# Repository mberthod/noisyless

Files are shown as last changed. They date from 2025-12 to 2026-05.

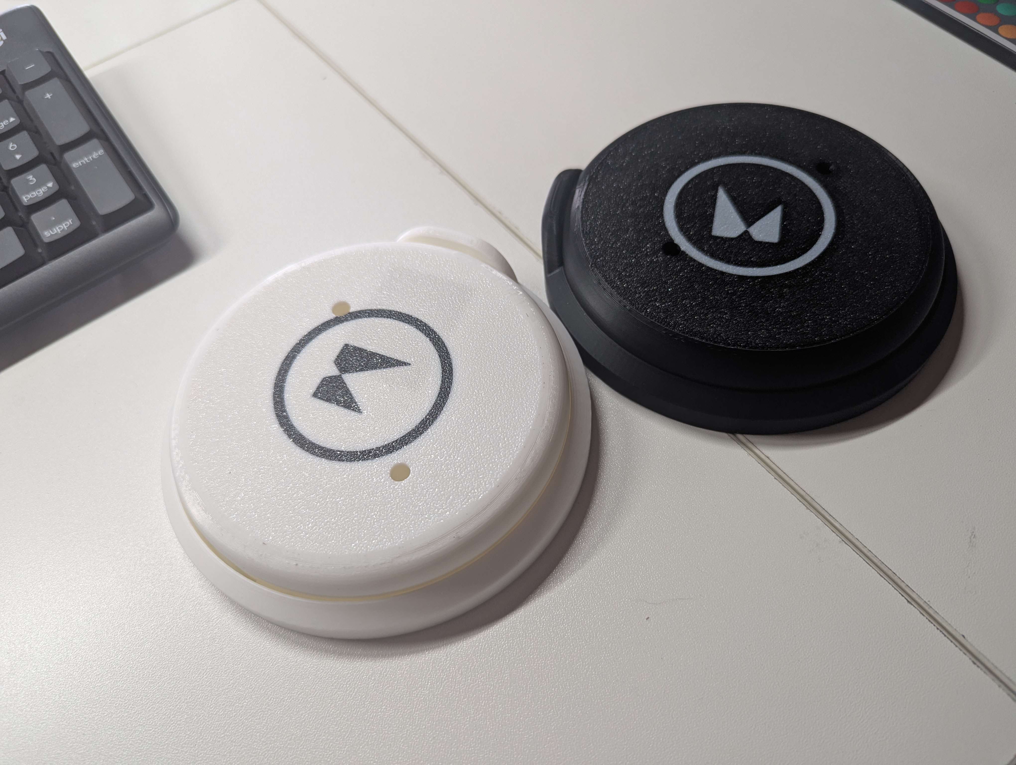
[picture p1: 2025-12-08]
01_PROJETS/202604_089_Capteur_Environnemental_V1/04_FABRICATION/PXL_20250405_083316542.jpg

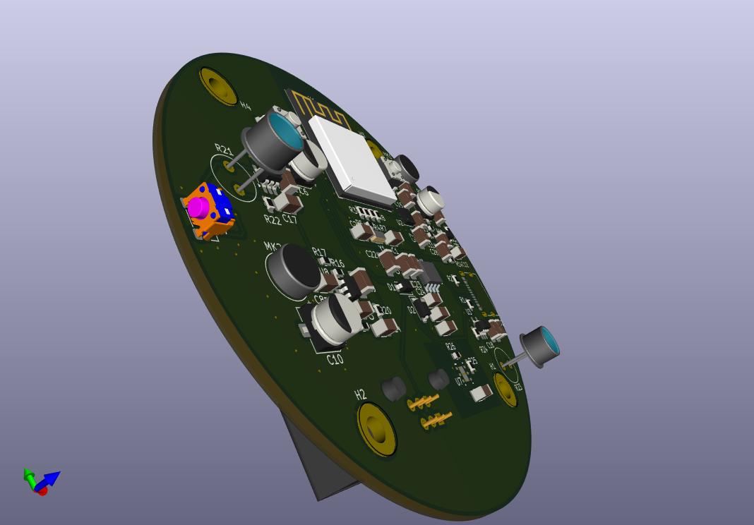
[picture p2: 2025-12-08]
01_PROJETS/202604_089_Capteur_Environnemental_V1/01_CAHIER_DES_CHARGES/Environnemental_sensor_V01.jpg

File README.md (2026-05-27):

# NOISYLESS — Capteur Environnemental IoT

Firmware ESP32-S3 modulaire pour le capteur environnemental NOISYLESS. Monitoring en temps réel du bruit, de la luminosité, de la qualité d'air (IAQ/CO₂/VOC) et de la présence humaine — transmission MQTT vers le dashboard, OTA over-the-air, LED de statut RGB.

## Capteurs (5 axes)

| Capteur | Pins | Mesure | Module |
|---|---|---|---|
| 🔆 **Luminosité ×2** | GPIO1, GPIO2 (ADC 12-bit) | Lux ambiant, deux directions | `analog_sensors.h` |
| 🎤 **Bruit (micro ×2)** | GPIO3, GPIO4 (ADC 12-bit) | Niveau sonore crête-à-crête (peak-to-peak 50ms) | `analog_sensors.h` |
| 🌡️ **Qualité d'air** | I²C SDA=GPIO35, SCL=GPIO36 | IAQ, CO₂eq, bVOCeq, T°/Hum/Pression compensées, Gas | `bme680_sensor.h` |
| 📡 **Présence radar** | UART Serial1 RX=GPIO18, TX=GPIO17 (256000 bauds) | Cible mobile, cible stationnaire, distance cm | `ld2410_sensor.h` |

### Principe de mesure

- **Lux ×2** : lecture directe `analogRead()` 12-bit, deux photorésistances orientées
- **Micro ×2** : échantillonnage 50ms, calcul de l'amplitude crête-à-crête (`max - min`) via deux électrets analogiques
- **BME680 + BSEC2** : capteur I²C 0x76, mode Ultra Low Power (ULP) — mesure toutes les 3s, calibration IAQ continue via algorithme Bosch BSEC2 (IAQ 0-500, CO₂eq, bVOCeq, T°/Hum/Pression compensées)
- **LD2410** : radar 24 GHz sur UART 256000 bauds, parse les trames binary → détection mouvement + stationnaire + distance

## Architecture firmware (v2.0.0)

```
05_FIRMWARE/
├── src/
│   ├── main.cpp                     # setup(), tâches FreeRTOS
│   ├── sensors/
│   │   ├── bme680_sensor.h/.cpp     # BME680 + BSEC2 (IAQ, CO2, VOC, T/H/P)
│   │   ├── ld2410_sensor.h          # LD2410 radar (présence, distance)
│   │   └── analog_sensors.h         # Lux ×2 + micros ×2 (ADC peak-to-peak)
│   ├── comm/
│   │   └── wifi_mqtt.h              # WiFi (hardcodé) + MQTT (PubSubClient)
│   ├── ota/
│   │   └── ota_manager.h            # OTA HTTP check 60s + download + flash SHA256
│   └── ui/
│       └── led_status.h/.cpp        # LED RGB (actif bas), séquence boot, timings
├── include/
│   ├── wifi_config.h                # SSID + mot de passe WiFi
│   └── credentials.h                # MQTT host/user/pass
└── platformio.ini                   # ESP32-S3, DIO, BSEC2 + LD2410 + PubSubClient
```

### FreeRTOS — 3 tâches

| Tâche | Cœur | Priorité | Stack | Rôle |
|---|---|---|---|---|
| `task_mqtt` | 0 | 1 | 4 Ko | WiFi/MQTT/OTA + publication 10s + LED rouge si WiFi perdu |
| `task_sensors` | 1 | 2 | 4 Ko | BME680 tick + LD2410 tick + Analog (50ms) |
| `task_led` | 0 | 0 | 2 Ko | Timings LED (vert boot 1s, flash publish 200ms) |

Les données sont partagées via `SharedData` protégé par `SemaphoreHandle_t` mutex.

### Séquence LED

| État | LED | Durée |
|---|-----|---|
| Boot | 🔴 Rouge fixe | ~1s |
| WiFi en cours | 🔵 Bleu fixe | Jusqu'à connexion |
| Version | 🔵×N clignotements | N = 3ᵉ chiffre version (ex: v2.0.**0** → 10 flashs) |
| Connecté | 🟢 Vert fixe | 1s |
| Publication MQTT OK | 🟢 Flash vert | 200ms |
| Idle | ⚫ Éteinte | — |
| WiFi perdu | 🔴 Rouge fixe | Jusqu'à reconnexion |

**Mapping GPIO** : LED_R=GPIO12, LED_G=GPIO13, LED_B=GPIO14. Actif bas : `LOW = allumé`.

## Payload MQTT

Topic : `esp32/noisyless/{MAC}/datas`

```json
{
  "product": "noisyless_env",
  "client_code": "client_demo",
  "device_id": "NL-A1B2C3D4E5F6",
  "fw_version": "2.0.0",

  "lux1_raw": 2048,
  "lux2_raw": 1890,
  "sound_mic1_pp": 295,
  "sound_mic2_pp": 266,

  "presence": true,
  "distance_cm": 120,

  "temp_comp_c": 22.40,
  "hum_comp_pct": 48.30,
  "pressure_pa": 101325,
  "iaq": 25.0,
  "co2eq_ppm": 450.0,
  "bvoc_eq_ppm": 0.50,
  "gas_ohms": 50000,
  "iaq_accuracy": 3,
  "stab_status": 1,
  "run_in_status": 1,

  "rssi_dbm": -58,
  "uptime_s": 3600
}
```

**Champs optionnels** : si le BME680 n'est pas détecté, les champs IAQ/CO₂/VOC/T°/Hum/Pression sont omis. Si le LD2410 n'est pas détecté, `presence` et `distance_cm` restent à `false`/`0`.

## Déploiement OTA — Workflow complet

### Prérequis

- PlatformIO (`pio --version`)
- Accès SSH au serveur Hetzner : `noisyless@91.99.26.43`
- Firmware servi par nginx depuis `/opt/noisyless/static/firmware/` sur le port 80
- WiFi hardcodé dans `include/wifi_config.h`

### 1. Modifier le firmware

```bash
cd 05_FIRMWARE
```

Sources à modifier :
- `src/main.cpp` — `FW_VERSION`, logique métier
- `include/wifi_config.h` — SSID + mot de passe WiFi
- `include/credentials.h` — host/user/pass MQTT

**Incrémenter `FW_VERSION`** dans `main.cpp` :
```cpp
#define FW_VERSION "2.0.1"  // ← changer ici
```

### 2. Builder

```bash
pio run -e esp32dev
```

Sortie : `.pio/build/esp32dev/firmware.bin` (~972 Ko avec BSEC2+LD2410)

**Config PlatformIO** (`platformio.ini`) :
- `board = esp32-s3-devkitc-1`
- `board_build.flash_size = 8MB`
- `board_build.psram_type = disabled`
- `board_build.flash_mode = dio`
- `board_build.flash_freq = 40m`
- `build_flags = -D ARDUINO_USB_CDC_ON_BOOT=1`
- `lib_deps = PubSubClient, ld2410, bsec2, BME68x`

### 3. Calculer le SHA256

```bash
sha256sum .pio/build/esp32dev/firmware.bin
```

### 4. Déployer sur le serveur

```bash
# Copier le binaire
scp .pio/build/esp32dev/firmware.bin noisyless@91.99.26.43:/opt/noisyless/static/firmware/

# Mettre à jour le manifest OTA
ssh noisyless@91.99.26.43 'cat > /opt/noisyless/static/firmware/latest.json << EOF
{"version":"2.0.1","url":"http://91.99.26.43/firmware/firmware.bin","sha256":"LE_HASH_ICI"}
EOF'
```

### 5. Vérifier

```bash
# Manifest
curl -s http://91.99.26.43/firmware/latest.json

# Binaire (200 OK)
curl -sI http://91.99.26.43/firmware/firmware.bin | head -3

# SHA256 côté serveur
ssh noisyless@91.99.26.43 'sha256sum /opt/noisyless/static/firmware/firmware.bin'
```

### 6. Propagation OTA

Chaque module checke le manifest **toutes les 60s**. Si `version != FW_VERSION` :
1. Téléchargement `.bin` (30s timeout)
2. Vérification SHA256
3. `Update.begin()` → flash
4. `ESP.restart()`

**Rollback automatique** : si le firmware ne boote pas, le bootloader ESP32-S3 restaure la partition précédente.

### 7. Surveillance

```bash
# Devices et versions
ssh noisyless@91.99.26.43 "docker compose -f /opt/noisyless/docker-compose.yml exec -T timescaledb psql -U noisyless -d noisyless -c 'SELECT device_id, firmware_version, status, last_seen FROM noisyless.devices ORDER BY last_seen DESC;'"

# Logs env-ingest
ssh noisyless@91.99.26.43 "docker compose -f /opt/noisyless/docker-compose.yml logs --tail=30 env-ingest | grep -E 'fw_version|device_id'"
```

### Flash USB direct (recovery)

```bash
pio run -e esp32dev -t upload

# Bootloop → full erase
pio run -e esp32dev -t erase && pio run -e esp32dev -t upload
```

## Architecture système

```
┌──────────────────────────┐     MQTT      ┌─────────────────┐     SQL      ┌──────────────┐
│  ESP32-S3 (×N)           │──────────────▶│  Hetzner VPS     │─────────────▶│ TimescaleDB   │
│  WiFi + MQTT + OTA       │   port 1883   │  mosquitto       │             │               │
│  lux×2 + mic×2           │               │  env-ingest      │    HTTP     │ devices       │
│  BME680/BSEC2 IAQ        │               │  api             │◀────────────│ measurements │
│  LD2410 présence         │◀──────────────│  nginx (static)  │             └──────────────┘
│  LED RGB statut          │   OTA HTTP:80  │                  │
└──────────────────────────┘               └─────────────────┘
```

## Pièges connus

- **ESP32-S3 flash mode** : S3-MINI-1 est QIO natif mais GPIO12/14 sont sur le bus SPI → utiliser DIO 40 MHz. Sans ça, les LEDs ne fonctionnent pas.
- **Partitions OTA** : `default.csv` suffit. `custom_partitions.csv` peut causer des bootloops si l'otadata est corrompue.
- **WiFiManager NVS** : les credentials WiFiManager survivent au reflash. Utiliser `esptool.py erase_flash` si on change de WiFi.
- **LED jaune** : toujours `led_off()` avant de changer de couleur (actif bas, rouge+vert simultanés = jaune).
- **SHA256 mismatch** : OTA silencieusement ignoré si le hash manifest ≠ hash binaire. Vérifier avec `curl | sha256sum`.
- **BSEC2 calibration** : l'IAQ met ~5 min à se stabiliser au premier boot (`run_in_status` = 1). L'accuracy monte progressivement de 0 à 3.
- **LD2410 baud rate** : 256000 obligatoire. Le constructeur documente 115200 mais le firmware usine est à 256000.
- **BME680 I²C** : scanne 0x76 puis 0x77. Si le capteur est en mode sleep (broche MODE flottante), il ne répond pas. GPIO37 doit être LOW.
- **Taille flash** : BSEC2 + BME68x + LD2410 = ~972 Ko / 1310 Ko dispo (74%). Compiler sans PSRAM. Vérifier `board_build.psram_type = disabled`.

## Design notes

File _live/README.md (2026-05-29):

# _live/ — Snapshot production NOISYLESS v1

Ce dossier est un **instantané** (`snapshot`) de ce qui tourne réellement
sur le VPS Hetzner (91.99.26.43) à la date du 29 mai 2026.

## Structure

```
_live/
├── STATE.md               ← État des lieux complet (ce document)
├── docker-compose.yml     ← Compose utilisé en production
├── services/              ← Code source des micro-services
│   ├── api/               ← FastAPI (auth, devices, admin, shop...)
│   ├── env-ingest/        ← ESP32 capteurs environnement → DB
│   ├── mqtt-ingest/       ← HeatMap → DB
│   ├── heatmap-agg/       ← Agrégation 5 min
│   └── alert-engine/      ← Alertes seuils
├── nginx/
│   ├── nginx.conf         ← Config nginx (2 domaines, SSL, proxy)
│   └── nginx.conf.bak     ← Backup précédent
├── mosquitto/config/
│   └── mosquitto.conf     ← Config broker MQTT
└── static/                ← Pages web (html uniquement)
    ├── platform.html      ← Dashboard plateforme
    ├── admin.html         ← Panel admin
    ├── dashboard.html     ← Dashboard utilisateur
    ├── pilote-heatmap.html
    ├── precommande.html
    ├── conciergerie.html
    ├── produits/          ← heatmap-indoor, outdoor, property-pack
    ├── cas-usage/         ← conciergerie, hospitality, immobilier, villa
    ├── comparatif/        ← vs-camera, vs-detecteur, vs-minut
    ├── technologie/       ← intelligence-spatiale, privacy, reseau-maille
    └── firmware/          ← stable.json, latest.json
```

## Avertissement

Les fichiers dans `services/` et `static/` sont les sources déployées en
production. Les chemins d'infrastructure correspondants dans le repo
sont synchronisés avec `_infra/` et `_commun/web/site/`.

Pour toute modification : éditer dans `_infra/`, déployer sur VPS,
**puis** mettre à jour `_live/` en miroir.

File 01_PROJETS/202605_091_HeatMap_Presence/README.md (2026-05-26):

# NOISYLESS — Organisation des projets

**Date :** 24 Mai 2026  
**Vue d'ensemble :** 3 produits distincts, 1 infrastructure commune

---

## 📋 Les 3 projets hardware

| Projet | Code | Capteurs | Usage | Prix cible |
|---|---|---|---|---|
| **NOISYLESS Simple** | `nl-presence` | PIR + ToF mono + CO₂ + Son | Détection présence basique | ~50 € |
| **NOISYLESS HeatMap Intérieur** | `nl-map-in` | Matrice ToF 16×16 (TMF8829) | Heatmap intérieure | ~80 € |
| **NOISYLESS HeatMap Extérieur** | `nl-map-out` | Radar 60 GHz (MS72SF1) | Heatmap extérieure | ~120 € |

---

## 🏗️ Architecture commune

```
┌─────────────────────────────────────────────────────────────┐
│                    NOISYLESS PLATFORM                       │
├─────────────────────────────────────────────────────────────┤
│                                                             │
│  ┌──────────┐  ┌──────────┐  ┌──────────┐                  │
│  │  Simple  │  │   Int    │  │   Ext    │                  │
│  │ nl-      │  │ nl-map-  │  │ nl-map-  │                  │
│  │ presence │  │   in     │  │   out    │                  │
│  └────┬─────┘  └────┬─────┘  └────┬─────┘                  │
│       │             │             │                         │
│       └─────────────┴─────────────┘                         │
│                     │                                       │
│                     ▼                                       │
│              ┌─────────────┐                                │
│              │   Mosquitto │  MQTT Broker                   │
│              │   (TLS 8883)│                                │
│              └──────┬──────┘                                │
│                     │                                       │
│                     ▼                                       │
│              ┌─────────────┐                                │
│              │  TimescaleDB │  Base de données              │
│              └──────┬──────┘                                │
│                     │                                       │
│       ┌─────────────┼─────────────┐                        │
│       │             │             │                         │
│       ▼             ▼             ▼                         │
│  ┌────────┐   ┌────────┐   ┌────────┐                      │
│  │ ingest │   │  agg   │   │ alert  │                      │
│  │  MQTT  │   │heatmap │   │ engine │                      │
│  └────────┘   └────────┘   └────────┘                      │
│                                                             │
│       ┌─────────────────────────────┐                      │
│       │      FastAPI Backend        │                      │
│       │   + Dashboard Web/Mobile    │                      │
│       └─────────────────────────────┘                      │
│                                                             │
└─────────────────────────────────────────────────────────────┘
```

---

## 📁 Arborescence des répertoires

```
/home/mathieu/Kdrive/01_CLIENTS/NOISYLESS/
├── 00_INFOS_CLIENT/              # Contrat, factures, contacts
│
├── _infra/                       # INFRASTRUCTURE COMMUNE
│   ├── docker-compose.yml        # Tous services
│   ├── services/
│   │   ├── mqtt-ingest/          # Subscribe MQTT → DB
│   │   ├── heatmap-agg/          # Agrégation 5min
│   │   ├── alert-engine/         # Alertes Telegram
│   │   └── api/                  # FastAPI REST
│   ├── mosquitto/                # Config broker
│   ├── timescaledb/              # Config DB
│   ├── nginx/                    # Reverse proxy + SSL
│   └── docs/
│       ├── DEPLOYMENT.md         # Guide déploiement (SIMPLE !)
│       ├── MAINTENANCE.md        # Opérations courantes
│       └── TROUBLESHOOTING.md    # Problèmes courants
│
├── 202605_091_HeatMap_Presence/  # PROJET PILOTE ( HeatMap )
│   ├── PROJECT.md                # Fiche projet #091
│   │
│   ├── 01_NOISYLESS_SIMPLE/      # Produit : Détection basique
│   │   ├── firmware/
│   │   │   └── node-presence/
│   │   │       ├── src/
│   │   │       ├── platformio.ini
│   │   │       └── README.md
│   │   ├── hardware/
│   │   │   ├── schematics/
│   │   │   └── bom/
│   │   ├── docs/
│   │   │   ├── QUICKSTART.md     # Démarrage rapide
│   │   │   └── INSTALL.md        # Installation
│   │   └── scripts/
│   │       └── flash.sh
│   │
│   ├── 02_NOISYLESS_HEATMAP_INT/ # Produit : Heatmap intérieur
│   │   ├── firmware/
│   │   │   └── node-tof-esp32s3/
│   │   │       ├── src/
│   │   │       ├── components/
│   │   │       ├── platformio.ini
│   │   │       └── README.md
│   │   ├── hardware/
│   │   │   ├── schematics/
│   │   │   └── bom/
│   │   ├── docs/
│   │   │   ├── QUICKSTART.md
│   │   │   └── INSTALL.md
│   │   └── scripts/
│   │       └── flash.sh
│   │
│   └── 03_NOISYLESS_HEATMAP_EXT/ # Produit : Heatmap extérieur
│       ├── firmware/
│       │   └── node-radar-ms72sf1/
│       │   ├── src/
│       │   ├── platformio.ini
│       │   └── README.md
│       ├── hardware/
│       │   ├── schematics/
│       │   └── bom/
│       ├── docs/
│       │   ├── QUICKSTART.md
│       │   └── INSTALL.md
│       └── scripts/
│           └── flash.sh
│
└── 202604_089_Capteur_Environnemental_V1/  # Ancien projet (archive)
```

---

## 🎯 Différences entre projets

### NOISYLESS Simple (`nl-presence`)

**Objectif :** Détecter présence + bruit + qualité d'air

**Capteurs :**
- PIR (présence binaire)
- ToF mono-zone (distance)
- SCD4x (CO₂, température, humidité)
- INMP441 (niveau sonore dB)

**Firmware :**
- Publish toutes les 30s
- Payload simple : `{present: bool, co2: int, db: int, temp: float}`
- Batterie possible (deep sleep)

**Backend :**
- Table `measurements` standard
- Alertes seuil CO₂ / bruit

---

### NOISYLESS HeatMap Intérieur (`nl-map-in`)

**Objectif :** Heatmap de densité intérieure

**Capteurs :**
- TMF8829 (ToF 16×16 zones)
- ESP32-S3 (WiFi + BLE)

**Firmware :**
- Mesh ESP-NOW (multi-noeuds)
- Master → MQTT toutes les 10s
- Payload : `{grid: [[count]], total: int}`

**Backend :**
- Continuous aggregates 5min
- Heatmap par zone
- Alertes suroccupation

---

### NOISYLESS HeatMap Extérieur (`nl-map-out`)

**Objectif :** Heatmap de densité extérieure

**Capteurs :**
- MS72SF1 (Radar 60 GHz)
- ESP32-S3 (WiFi + BLE)

**Firmware :**
- UART parsing (trames binaires TLV)
- Mesh ESP-NOW (multi-noeuds)
- Master → MQTT toutes les 10s
- Payload : `{targets: [{x,y,z,v}], count: int}`

**Backend :**
- Agrégation cibles 3D
- Heatmap projetée 2D
- Alertes suroccupation

---

## 🚀 Démarrage rapide

### 1. Déployer l'infrastructure

```bash
cd /home/mathieu/Kdrive/01_CLIENTS/NOISYLESS/_infra
./scripts/deploy.sh
```

→ Voir `_infra/docs/DEPLOYMENT.md`

### 2. Flasher un device

```bash
cd 01_NOISYLESS_SIMPLE/firmware/node-presence
pio run --target upload
```

→ Voir `01_NOISYLESS_SIMPLE/docs/QUICKSTART.md`

### 3. Claimer un device

```bash
curl -X POST https://platform.noisyless.com/api/devices/claim \
  -H "Authorization: Bearer <token>" \
  -d '{"duid": "24:EC:4A:23:36:BC", "claim_code": "HMAC..."}'
```

---

## 📊 État d'avancement

| Projet | Firmware | Hardware | Backend | Docs | Statut |
|---|---|---|---|---|---|
| **Simple** | 🟡 50% | ⚪ 0% | ✅ 80% | 🟡 50% | En dev |
| **HeatMap Int** | ✅ 90% | ⚪ 0% | ✅ 80% | 🟡 50% | Pilote |
| **HeatMap Ext** | 🟡 30% | ⚪ 0% | 🟡 50% | 🟡 50% | En dev |
| **Infra** | N/A | N/A | ✅ 90% | 🟡 60% | quasi-OK |

---

## 🔗 Liens utiles

- **Infrastructure :** `_infra/docs/DEPLOYMENT.md`
- **Projet #091 :** `PROJECT.md`
- **Architecture :** `_infra/ARCHITECTURE.md`
- **Migration :** `_infra/MIGRATION_PLAN.md`

---

*Document créé : 24 Mai 2026*  
*Mis à jour : 24 Mai 2026*

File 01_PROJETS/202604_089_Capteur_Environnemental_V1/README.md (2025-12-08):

# Environmental Sensor Firmware Documentation

## Overview

This documentation describes the firmware for an ESP32-S3 based environmental sensor system. The system is designed to monitor various environmental parameters including air quality, light levels, sound levels, and presence detection. The firmware is built using the Arduino framework and FreeRTOS for task management.

## System Architecture

The firmware is organized into several key components:

1. **Sensor Management**: Handles reading data from various environmental sensors
2. **Network Communication**: Manages WiFi connectivity and data transmission to a server
3. **Memory Management**: Monitors and optimizes memory usage
4. **Alert System**: Detects and reports significant environmental changes
5. **OTA Updates**: Supports over-the-air firmware updates

## FreeRTOS Task Structure

The firmware uses FreeRTOS to manage concurrent operations through the following tasks:

- **Memory Task**: Monitors memory usage and performs periodic defragmentation
- **Sensor Task**: Reads data from sensors at regular intervals
- **Network Task**: Handles all network communications
- **Button Task**: Monitors the physical button for user interactions

## Key Features

- Real-time environmental monitoring
- Automatic data transmission to a central server
- Offline data storage with automatic transmission when connectivity is restored
- Memory leak detection and prevention
- Automatic firmware updates
- Alert system for significant environmental changes

## Getting Started

To use this firmware:

1. Configure your credentials in `credentials.h`
2. Upload the firmware to your ESP32-S3 device
3. The device will automatically connect to WiFi and begin monitoring

## Memory Management

The firmware includes sophisticated memory management features:

- Periodic memory status logging
- Memory leak detection
- Automatic defragmentation
- NVS (Non-Volatile Storage) cleaning

## Network Communication

The firmware supports:

- Automatic WiFi connection and reconnection
- HTTP communication with a central server
- Retry mechanisms for failed transmissions
- Offline data storage

## Alert System

The alert system can detect:

- Device removal from its mounting
- Significant environmental changes
- System errors and warnings

## OTA Updates

The firmware supports over-the-air updates:

- Automatic update checking
- Secure update process
- Version management

## Dependencies

- Arduino Framework
- FreeRTOS
- WiFi Library
- HTTPClient Library
- ArduinoJson Library
- Preferences Library

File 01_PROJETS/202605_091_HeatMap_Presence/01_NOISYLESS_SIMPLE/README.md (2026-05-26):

# NOISYLESS Simple — `nl-presence`

**Statut :** En développement  
**Cible :** Détection présence basique + qualité d'air  
**Prix :** ~50 € BOM

---

## 📋 Spécifications

### Capteurs

| Capteur | Rôle | Interface |
|---|---|---|
| PIR HC-SR501 | Présence binaire | GPIO (IRQ) |
| VL53L0X | Distance mono-zone | I2C |
| SCD4x | CO₂, T°, HR | I2C |
| INMP441 | Niveau sonore (dB) | I2S |

### MCU

| Paramètre | Valeur |
|---|---|
| Modèle | ESP32-S3-MINI-1 |
| Flash | 8 MB |
| WiFi | 2.4 GHz |
| BLE | 5.0 |
| Antenne | PCB ou U.FL |

### Alimentation

| Mode | Conso | Autonomie |
|---|---|---|
| Actif | ~80 mA | — |
| Deep sleep | ~50 µA | ~2 ans (18650) |
| Secteur | USB-C 5V | Permanent |

---

## 📁 Structure du firmware

```
firmware/node-presence/
├── src/
│   ├── main.c              # App principale
│   ├── sensors/
│   │   ├── pir.c           # Driver PIR
│   │   ├── tof.c           # Driver VL53L0X
│   │   ├── scd4x.c         # Driver CO₂
│   │   └── mic.c           # Driver INMP441
│   ├── mesh/
│   │   ├── espnow.c        # ESP-NOW mesh
│   │   └── mqtt.c          # MQTT client
│   └── config/
│       ├── nvs.c           # Config NVS
│       └── ota.c           # OTA updates
├── platformio.ini
└── README.md
```

---

## 🔧 Installation firmware

### Prérequis

```bash
# Installer PlatformIO
pip install platformio

# Ou VS Code + extension PlatformIO
```

### Build

```bash
cd firmware/node-presence
pio run
```

### Flash USB

```bash
# Mode bootloader (tenir BOOT + RESET)
pio run --target upload
```

### Flash OTA (après premier claim)

```bash
# Le device récupère sa config WiFi + MQTT via provisioning
# Puis les mises à jour sont automatiques
```

---

## 📡 Payload MQTT

### Topic
```
noisyless/<duid>/telemetry
```

### Format
```json
{
  "schema": "nl.telemetry.v1",
  "model": "nl-presence",
  "duid": "24:EC:4A:23:36:BC",
  "ts": 1716500000,
  "metrics": {
    "present": true,
    "co2_ppm": 450,
    "temp_c": 22.5,
    "hum_pct": 45,
    "sound_db": 35
  },
  "health": {
    "battery_mv": 3300,
    "rssi": -62,
    "fw": "1.0.0"
  }
}
```

### Fréquence
- **Secteur :** Toutes les 30s
- **Batterie :** Toutes les 5min + delta significatif

---

## 🔐 Provisioning

### Méthode 1 : QR Code (recommandé)

1. Scanner QR sur étiquette device
2. App → WiFi credentials → device
3. Device → phone-home → backend
4. Backend → claim automatique

### Méthode 2 : SoftAP

1. Device boot → AP `NOISY-XXXX`
2. Connect → http://192.168.4.1
3. Config WiFi + MQTT
4. Redémarrage

### Méthode 3 : Claim code (secours)

1. Code HMAC sur étiquette
2. API POST `/devices/claim`
3. Validation manuelle

---

## 🏠 Installation physique

### Montage

| Emplacement | Hauteur | Fixation |
|---|---|---|
| Plafond | 2.5-3.5 m | Vis ou adhésif |
| Mur | 1.5-2.0 m | Vis |
| Bureau | — | Posé |

### Orientation

```
        ┌─────────┐
        │  PIR    │  ← Face à la zone à surveiller
        │  ● ●    │
        └─────────┘
           │
        Capteur
           │
        ▼ Zone de détection (120°)
```

### Portée PIR

- **Détection :** ~7 m
- **Angle :** 120°
- **Hauteur max :** 3.5 m

---

## 🆘 Dépannage

| Symptôme | Cause | Solution |
|---|---|---|
| LED ne s'allume pas | Pas d'alim | Vérifier USB-C |
| Pas de WiFi | Mauvais credentials | Refaire provisioning |
| CO₂ = 400 constant | SCD4x pas init | Redémarrer device |
| PIR toujours actif | Face à source chaleur | Déplacer capteur |
| Battery drain | Deep sleep bug | Flash firmware v1.1+ |

---

## 📊 Backend integration

### Tables DB utilisées

```sql
-- Devices
SELECT * FROM noisyless.devices WHERE model = 'nl-presence';

-- Mesures
SELECT time, payload->>'co2_ppm' AS co2
FROM noisyless.measurements
WHERE model = 'nl-presence'
ORDER BY time DESC
LIMIT 100;

-- Agrégats 5min
SELECT window_start, avg((payload->>'co2_ppm')::int) AS avg_co2
FROM noisyless.measurements_agg_5min
WHERE model = 'nl-presence'
GROUP BY window_start;
```

### Alertes configurables

```sql
-- Inscrire une alerte CO₂
INSERT INTO noisyless.alert_thresholds (villa_id, param, threshold)
VALUES ('villa_001', 'co2_ppm', 1000);

-- Inscrire une alerte présence (fête)
INSERT INTO noisyless.alert_thresholds (villa_id, param, threshold)
VALUES ('villa_001', 'present_count', 10);
```

---

## 📄 Fichiers du projet

| Fichier | Rôle |
|---|---|
| `firmware/node-presence/` | Code ESP32 |
| `hardware/schematics/` | Schémas électroniques |
| `hardware/bom/` | Liste composants |
| `docs/QUICKSTART.md` | Démarrage rapide |
| `docs/INSTALL.md` | Guide installation |
| `scripts/flash.sh` | Script flash |

---

## 🔗 Liens

- **Dashboard :** https://platform.noisyless.com
- **API docs :** https://api.platform.noisyless.com/docs
- **Infra deployment :** `../../_infra/docs/DEPLOYMENT.md`

---

*Créé : 24 Mai 2026*  
**Statut :** Firmware 50%, Hardware 0%, Backend 80%

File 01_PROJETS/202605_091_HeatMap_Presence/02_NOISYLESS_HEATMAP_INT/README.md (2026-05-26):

# NOISYLESS HeatMap Intérieur — `nl-map-in`

**Statut :** Pilote fonctionnel  
**Cible :** Heatmap intérieure (ToF 16×16)  
**Prix :** ~80 € BOM

---

## 📋 Spécifications

### Capteurs

| Capteur | Rôle | Interface |
|---|---|---|
| TMF8829 | ToF 16×16 zones | I2C |
| ESP32-S3 | MCU + WiFi | — |

### MCU

| Paramètre | Valeur |
|---|---|
| Modèle | ESP32-S3-MINI-1 |
| Flash | 8 MB |
| WiFi | 2.4 GHz |
| BLE | 5.0 |

### Alimentation

| Mode | Conso |
|---|---|
| Actif | ~150 mA |
| Deep sleep | ~100 µA |
| Secteur | USB-C 5V |

---

## 📁 Structure du firmware

```
firmware/node-tof-esp32s3/
├── src/
│   ├── main.c              # App principale
│   ├── components/
│   │   ├── tmf8829/        # Driver ToF
│   │   ├── cluster/        # Clustering 4-way
│   │   ├── mesh/           # ESP-NOW mesh
│   │   └── config/         # NVS config
│   └── power.c             # Gestion énergie
├── platformio.ini
└── README.md
```

---

## 🔧 Installation firmware

### Build

```bash
cd firmware/node-tof-esp32s3
pio run
```

### Flash

```bash
pio run --target upload
```

---

## 📡 Payload MQTT

```json
{
  "schema": "nl.telemetry.v1",
  "model": "nl-map-in",
  "duid": "24:EC:4A:23:36:BC",
  "ts": 1716500000,
  "metrics": {
    "grid": [[0,1,2],[1,3,1],[0,1,0]],
    "total_count": 5,
    "max_count": 3
  },
  "health": {
    "battery_mv": 3300,
    "rssi": -62,
    "fw": "1.0.0"
  }
}
```

---

## 🏠 Installation

### Montage plafond (recommandé)

```
        ┌─────────────┐
        │   ToF       │  ← Plafond, 2.5-3.5 m
        │  (16×16)    │
        └──────┬──────┘
               │
        ▼ Zone 5×5 m
```

### Multi-noeuds (mesh)

```
  ┌─────┐    ┌─────┐    ┌─────┐
  │Node1│◄──►│Node2│◄──►│Node3│  ← ESP-NOW mesh
  └──┬──┘    └──┬──┘    └──┬──┘
     │          │          │
     └──────────┴──────────┘
                │
           ┌────▼────┐
           │ Master  │  → MQTT
           └─────────┘
```

---

## 📊 Backend

### Tables utilisées

```sql
-- Heatmap agrégée 5min
SELECT window_start, villa_id, zone, total_count, max_count
FROM noisyless.heatmap_agg_5min
WHERE villa_id = 'villa_001'
ORDER BY window_start DESC
LIMIT 12;
```

### Alertes

```sql
-- Suroccupation
INSERT INTO noisyless.alert_thresholds (villa_id, param, threshold)
VALUES ('villa_001', 'max_count', 10);
```

---

## 🆘 Dépannage

| Symptôme | Cause | Solution |
|---|---|---|
| Pas de mesures | ToF pas init | Vérifier I2C (SDA/SCL) |
| Grid vide | Personne hors portée | Portée max ~5 m |
| Mesh instable | Nodes trop loin | Max 30 m entre nodes |

---

*Créé : 24 Mai 2026*  
**Statut :** Firmware 90%, Backend 80%

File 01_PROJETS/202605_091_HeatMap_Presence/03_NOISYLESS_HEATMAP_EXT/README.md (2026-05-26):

# NOISYLESS HeatMap Extérieur — `nl-map-out`

**Statut :** En développement  
**Cible :** Heatmap extérieure (Radar 60 GHz)  
**Prix :** ~120 € BOM

---

## 📋 Spécifications

### Capteurs

| Capteur | Rôle | Interface |
|---|---|---|
| MS72SF1 | Radar 60 GHz | UART |
| ESP32-S3 | MCU + WiFi | — |

### Performances

| Paramètre | Valeur |
|---|---|
| Portée | 0.5 - 30 m |
| Champ | 120° azimuth |
| Cibles max | 10-12 |
| Insensible | Lumière, pluie, vent |

---

## 📁 Structure du firmware

```
firmware/node-radar-ms72sf1/
├── src/
│   ├── main.c              # App principale
│   ├── components/
│   │   ├── ms72sf1/        # Driver UART
│   │   ├── parser/         # Parsing TLV
│   │   └── mesh/           # ESP-NOW
│   └── config/
├── platformio.ini
└── README.md
```

---

## 🔧 Test Python (validé)

```bash
# Installer dépendances
pip install PyQt5 pyqtgraph pyserial numpy

# Lancer l'app
python3 ms72sf1_radar_map.py --port /dev/ttyUSB0 --zmin 0.5 --zmax 2.5
```

---

## 📡 Payload MQTT

```json
{
  "schema": "nl.telemetry.v1",
  "model": "nl-map-out",
  "duid": "24:EC:4A:23:36:BC",
  "ts": 1716500000,
  "metrics": {
    "targets": [
      {"id": 1, "x": 1.2, "y": -0.5, "z": 1.8, "vx": 0.3, "q": 85}
    ],
    "count": 1
  },
  "health": {
    "battery_mv": 3300,
    "rssi": -62,
    "fw": "1.0.0"
  }
}
```

---

## 🏠 Installation

### Montage extérieur

```
        ┌─────────────┐
        │   Radar     │  ← IP65, -20 à +60°C
        │  60 GHz     │
        └──────┬──────┘
               │
        ▼ Zone 30×30 m
```

### Alimentation

- **Secteur :** USB-C 5V
- **PoE :** Option avec injecteur
- **Batterie :** 18650 + panneau solaire (option)

---

## 🆘 Dépannage

| Symptôme | Cause | Solution |
|---|---|---|
| Pas de trames | UART mal branché | Croiser TX/RX |
| Cibles fantômes | Sensibilité haute | `AT+SENS=3` |
| Z incorrect | Hauteur montage | `AT+HEIGHT=H` |

---

*Créé : 24 Mai 2026*  
**Statut :** Test Python OK, Firmware ESP32 30%

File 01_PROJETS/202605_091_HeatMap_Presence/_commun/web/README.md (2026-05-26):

# NOISYLESS — Web & Platform

**Structure :**
```
web/
├── site/              # Site vitrine OVH (noisyless.com)
│   ├── index.html     # Landing page (déjà en ligne)
│   └── assets/        # Images, CSS, JS
│
├── frontend/          # Dashboard client (platform.noisyless.com)
│   ├── src/
│   │   ├── components/
│   │   ├── views/
│   │   └── App.vue
│   └── public/
│
└── backend/           # API + Auth (VPS 91.99.26.43)
    ├── api/
    │   ├── main.py
    │   ├── auth.py    # Register, login, verify
    │   └── devices.py # CRUD devices
    └── services/
```

---

## 📋 État actuel

| Élément | URL | État |
|---|-----|---|
| **Site vitrine** | `noisyless.com` | ✅ En ligne (OVH) |
| **Dashboard** | `platform.noisyless.com` | 🟡 Page statique (VPS) |
| **Auth API** | `api.platform.noisyless.com/auth/*` | ❌ À créer |

---

## 🚀 Architecture cible

```
┌─────────────────────────────────────────────────────┐
│  OVH Hosting (noisyless.com)                        │
│  — Site vitrine statique                            │
│  — Présentation produits                            │
│  — Bouton "Dashboard" → platform.noisyless.com      │
└─────────────────────────────────────────────────────┘
                      │
                      ▼
┌─────────────────────────────────────────────────────┐
│  VPS 91.99.26.43 (platform.noisyless.com)           │
│  ┌─────────────────────────────────────────────┐   │
│  │  Frontend (Vue.js + Tailwind)               │   │
│  │  — Login/Register                           │   │
│  │  — Dashboard client                         │   │
│  │  — Devices management                       │   │
│  └─────────────────────────────────────────────┘   │
│  ┌─────────────────────────────────────────────┐   │
│  │  Backend (FastAPI)                          │   │
│  │  — POST /auth/register                      │   │
│  │  — POST /auth/login                         │   │
│  │  — POST /auth/verify                        │   │
│  │  — GET  /api/devices                        │   │
│  │  — POST /api/devices                        │   │
│  └─────────────────────────────────────────────┘   │
│  ┌─────────────────────────────────────────────┐   │
│  │  Database (TimescaleDB)                     │   │
│  │  — users                                    │   │
│  │  — devices                                  │   │
│  │  — measurements                             │   │
│  └─────────────────────────────────────────────┘   │
└─────────────────────────────────────────────────────┘
```

---

## 🔧 Prochaines étapes

### Semaine 1 — Authentification

1. **Backend API** (`backend/api/auth.py`)
   - [ ] `POST /auth/register` — Créer compte
   - [ ] `POST /auth/login` — Login + JWT
   - [ ] `POST /auth/verify` — Vérifier email
   - [ ] `POST /auth/forgot` — Reset password

2. **Frontend** (`frontend/src/views/Auth.vue`)
   - [ ] Page register
   - [ ] Page login
   - [ ] Page verify email
   - [ ] Dashboard après login

3. **Email (Brevo)**
   - [ ] Configurer API key Brevo
   - [ ] Template email verification
   - [ ] Template welcome

---

## 📊 Flux utilisateur

```
1. User arrive sur noisyless.com (OVH)
         │
         ▼
2. Clique "Dashboard" → platform.noisyless.com
         │
         ▼
3. Page login/register
         │
    ┌────┴────┐
    │         │
    ▼         ▼
4a. Login   4b. Register
    │         │
    ▼         ▼
5. JWT    5. Email verification
    │         │
    └────┬────┘
         ▼
6. Dashboard (voir ses devices + heatmap)
         │
         ▼
7. Acheter devices (Stripe)
         │
         ▼
8. Claim devices (QR code / HMAC)
```

---

## 🔗 Liens

- **Site OVH :** `ftp://noisyln@ftp.cluster121.hosting.ovh.net/www/`
- **VPS SSH :** `ssh -i ~/.ssh/id_ed25519 noisyless@91.99.26.43`
- **Infra docs :** `../_infra/docs/DEPLOYMENT.md`

---

*Créé : 24 Mai 2026*

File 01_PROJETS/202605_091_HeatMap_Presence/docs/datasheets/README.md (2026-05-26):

# Datasheets — Téléchargement manuel requis

## Téléchargés ✅
| Fichier | Taille | Source |
|---|---|---|
| `BME680-DS001.pdf` | 1.4 MB | Bosch Sensortec |
| `ESP32-S3-MINI-1_datasheet.pdf` | 1.3 MB | Espressif |

## À télécharger manuellement
| Fichier | URL probable | Notes |
|---|---|---|
| `TMF8829_DS001140.pdf` | https://www.ams-osram.com/en/download/doc/ds001140 | Portail de téléchargement ams-OSRAM — navigation manuelle requise |
| `TMF8829_short_DS001148.pdf` | https://www.ams-osram.com/en/products/tmf8829 | Short datasheet (général) — le DS001140 complet est protégé |
| `LD6001A_datasheet.pdf` | https://www.hi-link.com/products/ld6001a | Hi-Link product page — contacter le fabricant ou chercher via LCSC |

## Notes
- TMF8829 : le datasheet complet (DS001140, 2.5 MB) existe mais n'est pas accessible en curl direct — portail avec cookie/redirect
- LD6001A : Hi-Link ne publie pas le PDF en téléchargement libre — contacter le support ou chercher un distributeur (LCSC, AliExpress)
- ESP32-S3 (datasheet général, pas MINI-1) déjà couvert par le MINI-1 + la référence ESP32-S3 standard

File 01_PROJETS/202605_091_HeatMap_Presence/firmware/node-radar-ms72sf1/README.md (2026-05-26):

# MS72SF1 Radar Node — Documentation

## Vue d'ensemble

**Capteur :** MinewSemi MS72SF1 (mmWave 60-64 GHz)  
**Usage :** Détection de présence + tracking multi-cibles extérieur/intérieur  
**Portée :** Jusqu'à 30 m, insensible lumière du jour  
**Interface :** UART (115200 baud) → Protocole binaire TLV

---

## Spécifications techniques

| Paramètre | Valeur |
|---|---|
| Fréquence | 60-64 GHz (mmWave FMCW) |
| Portée | 0.1 - 30 m |
| Champ de vue | 120° (azimuth), 60° (élévation) |
| Résolution | ~5 cm (distance), ~10° (angle) |
| Cibles max | 10-12 personnes simultanées |
| Interface | UART TTL (3.3V) |
| Baudrate | 115200 |
| Alimentation | 3.3V ou 5V (selon module) |
| Montage | Plafond ou mural |

---

## Protocole de communication

### Trame binaire (datasheet §8.2)

```
┌────────┬────────┬────────┬─────────────────────┐
| HEADER | LENGTH | FRAME  | TLVs (variable)     |
| 8 octets| 4 octets| 4 octets| { type, len, payload } |
└────────┴────────┴────────┴─────────────────────┘
```

**Header :** `01 02 03 04 05 06 07 08` (fixe)  
**Length :** `uint32` little-endian (trame complète, header inclus)  
**Frame :** `uint32` little-endian (numéro de trame)

### TLV (Type-Length-Value)

| Type | Nom | Description |
|---|-----|---|
| 1 | Point Cloud | Nuage de points bruts (len=0 sur ce firmware) |
| 2 | Tracks | Pistes personnes (8 floats par cible) |

**Structure Track (32 octets = 8 × float32) :**

| Offset | Champ | Type | Unité |
|---|---|---|---|
| 0 | Q | float | Qualité (0-100) |
| 4 | ID | float | Identifiant unique |
| 8 | X | float | Position (m) |
| 12 | Y | float | Position (m) |
| 16 | Z | float | Hauteur (m) |
| 20 | Vx | float | Vitesse X (m/s) |
| 24 | Vy | float | Vitesse Y (m/s) |
| 28 | Vz | float | Vitesse Z (m/s) |

---

## Commandes AT

### Initialisation

```python
AT_INIT = [
    b"AT+DEBUG=3\n",   # Mode 3 = trames binaires
    b"AT+START\n",     # Démarrer l'acquisition
]
```

### Autres commandes (datasheet §8.1)

| Commande | Description |
|---|---|
| `AT+VERSION` | Version firmware |
| `AT+HELP` | Liste des commandes |
| `AT+CONFIG=<param>` | Configuration |
| `AT+STOP` | Arrêter l'acquisition |
| `AT+RESET` | Redémarrer le module |

---

## Test Python

### Installation dépendances

```bash
# Debian/Ubuntu
sudo apt install python3-pyqt5 python3-pyqtgraph python3-serial python3-numpy

# Ou via pip
pip install PyQt5 pyqtgraph pyserial numpy
```

### Usage

```bash
# Mode normal
python3 ms72sf1_radar_map.py

# Port série personnalisé
python3 ms72sf1_radar_map.py --port /dev/ttyUSB1

# Debug (hexdump des trames)
python3 ms72sf1_radar_map.py --debug

# Sans initialisation AT (si déjà fait)
python3 ms72sf1_radar_map.py --no-init

# Filtrage hauteur (rejette chiens, enfants assis)
python3 ms72sf1_radar_map.py --zmin 0.5 --zmax 2.5

# Désactiver filtrage zone
python3 ms72sf1_radar_map.py --no-zone-filter
```

### Options de filtrage

| Option | Description | Valeur recommandée |
|---|---|---|
| `--confirm N` | Trames avant validation piste | 3 (défaut) |
| `--zmin M` | Hauteur mini (m) | 0.5 (rejette chiens) |
| `--zmax M` | Hauteur maxi (m) | 2.5 (debout) |
| `--view M` | Demi-étendue vue (m) | 5.0 |

---

## Portage ESP32-S3

### Architecture cible

```
ESP32-S3 (UART) ←→ MS72SF1
    │
    ├─ ESP-NOW mesh (même proto que node-tof)
    │
    └─ MQTT (master only)
```

### Travail requis

| Tâche | Effort | Notes |
|---|---|---|
| Driver UART ESP-IDF | 2h | Lecture trames binaires |
| Parser TLV | 4h | Même algo que Python |
| Filtre anti-ghost | 2h | Confirmation N trames |
| Intégration mesh ESP-NOW | 4h | Compatibilité node-tof |
| Calibration zone/Z | 2h | Config NVS |
| Payload MQTT | 2h | Format compatible backend |

**Total : ~16h**

---

## Payload MQTT (format cible)

```json
{
  "schema": "nl.telemetry.v1",
  "model":  "nl-map-out",
  "duid":   "24:EC:4A:23:36:BC",
  "ts":     1716500000,
  "metrics": {
    "targets": [
      {"id": 1, "x": 1.2, "y": -0.5, "z": 1.8, "vx": 0.3, "vy": -0.1, "vz": 0.0, "q": 85},
      {"id": 2, "x": -1.0, "y": 2.1, "z": 1.7, "vx": -0.2, "vy": 0.4, "vz": 0.0, "q": 72}
    ],
    "count": 2,
    "zone": {"xmin": -3.0, "xmax": 3.0, "ymin": -3.0, "ymax": 3.0}
  },
  "health": {
    "battery_mv": 3300,
    "rssi": -62,
    "fw": "1.0.0"
  }
}
```

**Différences vs ToF :**
- `targets[]` au lieu de `grid[][]`
- Coordonnées 3D + vitesse
- `model = "nl-map-out"`

---

## Calibration

### Montage plafond (recommandé)

```
        ┌────────────┐
        │   Radar    │  ← Plafond, hauteur H
        │    (0,0)   │
        └─────┬──────┘
              │ Z (hauteur)
              │
    ──────────┼──────────  ← Sol (Z = -H)
              │
    ◄──── X ──┼── ─────►
              │
              │ Y (profondeur)
```

**Paramètres NVS :**
- `calib_x_m` : Décalage X (m)
- `calib_y_m` : Décalage Y (m)
- `calib_z_m` : Hauteur montage (m)
- `calib_theta_deg` : Rotation (°)

### Commandes AT de calibration

```
AT+ZONE=XMIN,XMAX,YMIN,YMAX
AT+HEIGHT=H
AT+ANGLE=THETA
```

---

## Dépannage

| Symptôme | Cause probable | Solution |
|---|---|---|
| Pas de trames | Mauvais port série | `ls /dev/ttyUSB*` |
| Trames corrompues | Baudrate incorrect | Vérifier 115200 |
| Cibles fantômes | Sensibilité trop haute | `AT+SENS=N` (réduire) |
| Perte de cibles | Zone trop petite | `AT+ZONE=...` (élargir) |
| Z incorrect | Hauteur montage erronée | `AT+HEIGHT=H` |

---

## Références

- Datasheet MS72SF1 : `docs/MS72SF1_Datasheet.pdf`
- Protocole §8.2 : `docs/MS72SF1_Protocol.pdf`
- Commandes AT §8.1 : `docs/MS72SF1_AT_Commands.pdf`

---

*Créé : 24 Mai 2026*  
*Statut : Test Python OK, portage ESP32 à faire*

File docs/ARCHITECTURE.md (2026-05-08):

# NOISYLESS — Architecture & Pipeline de donnees

**Derniere mise a jour** : 2026-05-08
**Etat** : MVP fonctionnel end-to-end

---

## 1. Vue d'ensemble

```
+------------------+        WiFi          +-----------------+
| ESP32-S3 capteur | <------------------> | Reseau client    |
| BME680 + LD2410  |                      +-----------------+
| 2x mic + 2x lux  |                              |
+------------------+                              |
        |                                         v
        | MQTT plain (port 1883)         +-----------------+
        | Topic: esp32/noisyless/        | Internet        |
        |        <MAC>/datas             +-----------------+
        v                                         |
+------------------+                              v
| VPS Hetzner      |   <----  91.99.26.43  ------+
| (platform.       |
|  noisyless.com)  |
+------------------+
        |
        | Docker network "noisyless_default"
        |
        +---> Mosquitto (1883)  -+
        |                        |
        |                        v
        +---> mqtt_ingest.py ----+
        |        |
        |        v
        +---> TimescaleDB (5432, table measurements)
        |
        +---> FastAPI (interne 8000) <-- Nginx (443) <-- HTTPS clients
```

---

## 2. Pipeline de donnees

### 2.1 Firmware ESP32-S3

**Fichier principal** : `05_FIRMWARE/src/main.cpp`

**Capteurs lus** :
| Capteur | Bus | Pins | Donnees |
|---|-----|---|---|
| BME680 | I2C | SDA=35, SCL=36 | Temp, humidite, pression, gaz, IAQ, CO2eq, VOC (via BSEC2) |
| LD2410 | UART1 | RX=18, TX=17 @256000 baud | Presence, distance moving/stationary, energy |
| Mic 1 | ADC analog | GPIO 3 | Pic-a-pic 50ms |
| Mic 2 | ADC analog | GPIO 4 | Pic-a-pic 50ms |
| Lux 1 | ADC analog | GPIO 1 | Brut 0-4095 |
| Lux 2 | ADC analog | GPIO 2 | Brut 0-4095 |

**Tasks FreeRTOS** (dual-core ESP32-S3) :
- `task_mqtt` — connexion WiFi + MQTT, publish toutes les 10s, check OTA toutes les heures
- `task_adc` — lecture lux + mic toutes les 100ms
- `task_ld2410` — lecture frames radar toutes les 100ms (parser custom)
- `task_bsec` — execute BSEC2 toutes les 50ms

**Format JSON publie** (toutes les 10s) :
```json
{
  "product": "noisyless_env",
  "device_id": "NL-001",
  "fw_version": "1.0.0",
  "temperature_c": 27.47,
  "humidity_pct": 43.07,
  "pressure_pa": 95867,
  "gas_ohms": 59724,
  "iaq": 50.0,
  "co2eq_ppm": 500.0,
  "bvoc_eq_ppm": 0.5,
  "lux1_raw": 1014,
  "lux2_raw": 1158,
  "sound_mic1_pp": 251,
  "sound_mic2_pp": 0,
  "presence": true,
  "target_distance_cm": 30,
  "rssi_dbm": -47,
  "uptime_s": 3373
}
```

**Topic MQTT** : `esp32/noisyless/<MAC>/datas` (MAC sans deux-points, hex maj.)

### 2.2 Mosquitto (broker MQTT)

**Container** : `noisyless-mosquitto-1` sur VPS
**Config** : `/opt/noisyless/mosquitto/config/mosquitto.conf`

```
listener 1883
allow_anonymous false
password_file /mosquitto/config/passwd
persistence true
persistence_location /mosquitto/data/
```

**Auth** : user `esp32` / pass dans `/opt/noisyless/mosquitto/config/passwd`
**Port expose** : 1883 sur l'IP publique du VPS (Hetzner sans firewall par defaut)
**TLS 8883** : non actif au MVP, prevue pour Phase 2 (clients externes)

### 2.3 mqtt_ingest.py (pont MQTT -> DB)

**Container** : `noisyless-mqtt-ingest`
**Image** : buildee localement depuis `/opt/noisyless/mqtt-ingest/`

**Role** :
1. Subscribe au topic `esp32/noisyless/+/datas`
2. Parse le JSON
3. Convertit `sound_mic1_pp` -> dB SPL (formule log)
4. Convertit `lux1_raw` -> lux (lineaire)
5. INSERT dans `measurements` (TimescaleDB)
6. UPDATE `devices.last_seen` + `firmware_version`

**Conversions appliquees** :
- `db_avg = 30 + 20*log10(max(pp, 1))`
- `db_peak = 30 + 20*log10(max(max(mic1, mic2), 1))`
- `lux = raw_adc * 0.25`

**Code** : `/home/mathieu/noisyless/deploy/mqtt-ingest/mqtt_ingest.py`

### 2.4 TimescaleDB (table measurements)

**Container** : `noisyless-timescaledb-1`
**DB** : `noisyless`, user `noisyless`
**Schema** :
```sql
CREATE TABLE measurements (
    time TIMESTAMPTZ NOT NULL,
    device_id VARCHAR(20) REFERENCES devices(device_id),
    temp NUMERIC(5,2),
    humidity NUMERIC(5,2),
    gas_resistance NUMERIC(10,2),
    iaq INTEGER,
    presence BOOLEAN,
    distance_cm NUMERIC(5,2),
    db_avg NUMERIC(5,2),
    db_peak NUMERIC(5,2),
    lux1 NUMERIC(5,2),
    lux2 NUMERIC(5,2),
    PRIMARY KEY (time, device_id)
);
SELECT create_hypertable('measurements', 'time');
```

`devices.firmware_version` ajoute via `ALTER TABLE` le 2026-05-08.

### 2.5 API FastAPI

**Container** : `noisyless-api-1`
**Endpoints utilises par le dashboard** :
- `POST /api/auth/send-magic-link` — auth email-only
- `POST /api/auth/verify-magic-link` — retourne JWT
- `GET /api/devices` — liste capteurs lies au user (avec dernier etat)
- `GET /api/devices/{id}/live` — derniere mesure (format imbrique)
- `GET /api/devices/{id}/timeline` — 24h d'historique
- `POST /api/devices` — lier un nouveau capteur

**Format reponse `/live`** (corrige 2026-05-08) :
```json
{
  "device_id": "NL-001",
  "last_seen": "2026-05-08T13:16:03Z",
  "bme": { "temp": 27.47, "humidity": 43.07, "iaq": 50, "gas_resistance": 59724 },
  "ld2410": { "presence": true, "distance_cm": 30 },
  "mic": { "db_avg": 78.1, "db_peak": 78.1 },
  "lux1": 1.2,
  "lux2": 11.2
}
```

### 2.6 Dashboard frontend

**Fichiers** : `/opt/noisyless/static/{index,verify,dashboard}.html`
**Tech** : Vue 3 (CDN), CSS pur, pas de build step

**Bug corrige le 2026-05-08** : le dashboard lisait `d.live.temp` (plat) alors que l'API retourne `d.live.bme.temp` (imbrique). Toutes les references corrigees pour utiliser le format imbrique.

---

## 3. Modifications firmware (2026-05-08)

### 3.1 MQTT broker pointe vers VPS

**Avant** : `MQTT_HOST = "85.215.145.44"` (mauvais serveur)
**Apres** : `MQTT_HOST = "91.99.26.43"` (VPS NOISYLESS)

Fichier : `05_FIRMWARE/include/credentials.h`

### 3.2 Parser LD2410 custom (remplace lib buggee)

**Probleme** : `ncmreynolds/ld2410@^0.1.4` retournait `false` sur `radar.begin()` alors que le capteur envoyait bien des frames.

**Diagnostic** : lecture brute UART a montre des frames valides au format datasheet HLK-LD2410 :
```
F4 F3 F2 F1 [header] | LL LL [length] | 02 AA [type] | STATE | MD_L MD_H | ME | SD_L SD_H | SE | DD_L DD_H | 55 | CK | F8 F7 F6 F5 [footer]
```

**Solution** : parser custom (`parseLD2410Stream()`) ~50 lignes qui scanne les frames F4F3F2F1...F8F7F6F5. La lib est toujours dans `platformio.ini` mais `radar.read()` n'est plus appele.

**Champs lus** :
- `state` : 0=aucun, 1=mouvement, 2=stationnaire, 3=les deux
- `moving_dist_cm` + `moving_energy`
- `still_dist_cm` + `still_energy`
- `detection_dist_cm`

### 3.3 Re-essai d'init en boucle (5s)

L'init du LD2410 ne fait plus echec definitif. La task `task_ld2410` re-essaie toutes les 5s si l'init echoue (utile au boot si le capteur met du temps a demarrer).

---

## 4. Deploiement VPS — comment ca a ete fait

### 4.1 Service mqtt_ingest

```bash
# Local
cd /home/mathieu/noisyless/deploy
bash deploy-vps.sh
```

Le script :
1. Upload `mqtt-ingest/` sur `/opt/noisyless/mqtt-ingest/`
2. Upload `mosquitto/mosquitto.conf` sur le VPS
3. Cree le fichier passwd Mosquitto via container temp (avec bonnes permissions UID 1883)
4. Genere `/opt/noisyless/docker-compose.mqtt-ingest.yml` (overlay)
5. Patche `docker-compose.yml` pour:
   - Fixer le double-mount des volumes mosquitto
   - Ajouter le port 1883 au mapping
6. `docker compose up -d --build mosquitto mqtt-ingest`

### 4.2 Permissions Mosquitto

Probleme rencontre : le passwd cree par defaut etait owned root mode 600, Mosquitto (UID 1883) ne pouvait pas le lire. Solution :
```bash
docker run --rm -v /opt/noisyless/mosquitto/config:/mosquitto/config --user root \
    eclipse-mosquitto:2 \
    sh -c 'rm -f /mosquitto/config/passwd && \
           mosquitto_passwd -b -c /mosquitto/config/passwd esp32 "<pass>" && \
           chown 1883:1883 /mosquitto/config/passwd && \
           chmod 644 /mosquitto/config/passwd'
```

### 4.3 Reseau Docker

Mosquitto et mqtt-ingest sont sur le reseau `noisyless_default` (auto-cree par compose). DNS interne resout `mosquitto`, `timescaledb`, `api`, etc.

---

## 5. Comment flasher l'ESP32

### 5.1 Prerequis

- PlatformIO installe : `pip install platformio` (ou venv)
- ESP32-S3 connecte en USB (apparait comme `/dev/ttyACM0`)
- User dans groupe `dialout`

### 5.2 Compilation

```bash
cd /home/mathieu/noisyless/05_FIRMWARE
source /home/mathieu/.pio-venv/bin/activate
pio run -e esp32dev
```

**Premier build** : ~10 min (telecharge toolchain RISC-V, framework Arduino ESP32, esptool)
**Builds suivants** : ~30s

### 5.3 Flash

```bash
pio run -e esp32dev -t upload --upload-port /dev/ttyACM0
```

L'ESP32 reboote automatiquement. Le firmware se connecte au WiFi puis au MQTT.

### 5.4 Lecture des logs serie

```bash
pio device monitor -p /dev/ttyACM0 -b 115200
# OU script Python pour lecture filtree :
python3 -c "
import serial; s = serial.Serial('/dev/ttyACM0', 115200)
while True: print(s.readline().decode(errors='replace').strip())
"
```

### 5.5 Reset programme via DTR/RTS

Pour relancer le boot sans debrancher :
```python
import serial, time
s = serial.Serial('/dev/ttyACM0', 115200)
s.setDTR(False); s.setRTS(True); time.sleep(0.2); s.setRTS(False)
```

---

## 6. Verifications end-to-end

### 6.1 Capteur emet bien des frames LD2410

```python
# Lit les bytes bruts UART pendant 5s
import serial, time
s = serial.Serial('/dev/ttyACM0', 115200)
# (apres reset, lire les logs DIAG si compile en mode diag)
```

Frame valide :
```
F4 F3 F2 F1 0D 00 02 AA <state> <md_l> <md_h> <me> <sd_l> <sd_h> <se> <dd_l> <dd_h> 55 <ck> F8 F7 F6 F5
```

### 6.2 MQTT recoit les messages

Sur le VPS :
```bash
ssh noisyless@91.99.26.43
docker exec -it noisyless-mosquitto-1 mosquitto_sub \
    -h localhost -p 1883 -u esp32 -P '<pass>' \
    -t 'esp32/noisyless/+/datas' -v
```

### 6.3 Ingest insere en DB

```bash
docker logs noisyless-mqtt-ingest --tail 20
```

Doit afficher des lignes `[INGEST] NL-001 | temp=... iaq=... presence=... db_avg=... lux1=...`.

### 6.4 DB contient les mesures

```bash
docker exec noisyless-timescaledb-1 psql -U noisyless -d noisyless -c \
    "SELECT time, device_id, temp, presence, distance_cm, db_avg, lux1 \
     FROM measurements ORDER BY time DESC LIMIT 5;"
```

### 6.5 Dashboard affiche les donnees

`https://platform.noisyless.com/dashboard.html` apres login magic-link.
La carte du capteur doit afficher : Bruit dB, Presence OUI/NON, Temp, Humidite, IAQ, Lumiere.

---

## 7. Limitations actuelles (a corriger pour la vente)

### 7.1 WiFi hardcode
SSID/pass dans le code -> impossible pour client de configurer.
**TODO** : integrer `WiFiManager` (lib deja dans platformio.ini, captive portal AP).

### 7.2 Device ID fixe `NL-001`
Tous les capteurs flashes auront le meme ID -> conflit MQTT topic.
**TODO** : generer ID a partir de la MAC address au boot.

### 7.3 LEDs status non utilisees
Les 3 LEDs RGB sont initialisees mais pas pilotees selon l'etat.
**TODO** : rouge=pas WiFi, bleu=connect MQTT, vert=OK, vert clignotant=OTA.

### 7.4 Pas de TLS MQTT
Port 1883 sans TLS. Mot de passe en clair sur le reseau.
**TODO** : Phase 2, activer 8883 avec certs Let's Encrypt embarques.

### 7.5 OTA via GitHub manifest
Existe deja, pointe sur `mberthod/202411_Projet_029___EnvironnementalSensor/noisyless_ws/ota/stable.json` mais le repo a change pour `mberthod/noisyless`.
**TODO** : creer `ota/stable.json` dans le nouveau repo + GitHub Action de build.

### 7.6 Pas de webhook Stripe
Achat -> aucune creation auto de compte / device.
**TODO** : webhook `/api/stripe/webhook` qui cree le user et envoie le magic-link.

---

## 8. Fichiers cles

```
/home/mathieu/noisyless/
├── 05_FIRMWARE/
│   ├── platformio.ini
│   ├── include/credentials.h          (MQTT_HOST=91.99.26.43, user/pass)
│   └── src/main.cpp                   (parser LD2410 custom integre)
├── deploy/
│   ├── mqtt-ingest/
│   │   ├── mqtt_ingest.py             (pont MQTT -> TimescaleDB)
│   │   ├── Dockerfile
│   │   └── requirements.txt
│   ├── mosquitto/mosquitto.conf
│   └── deploy-vps.sh                  (script idempotent)
├── docs/
│   └── ARCHITECTURE.md                (ce fichier)
└── PLAN_J5_VENTE.md                   (roadmap J+5 pour la vente)
```

```
VPS noisyless@91.99.26.43:/opt/noisyless/
├── docker-compose.yml                 (modifie : mosquitto port 1883 + volumes fixes)
├── docker-compose.mqtt-ingest.yml     (overlay mqtt-ingest)
├── mqtt-ingest/                       (deploye depuis local)
├── mosquitto/config/{mosquitto.conf,passwd}
└── static/dashboard.html              (corrige format imbrique 2026-05-08)
```

---

## 9. Auth / secrets (NE PAS COMMIT)

| Service | Secret | Stockage |
|---|---|---|
| MQTT | user `esp32` / pass | `credentials.h` (.gitignore), `/opt/noisyless/mosquitto/config/passwd` |
| Postgres | user `noisyless` / pass | `/opt/noisyless/.env` |
| JWT | HS256 secret | `/opt/noisyless/.env` |
| SMTP OVH | user/pass | `/opt/noisyless/.env` |
| Stripe | sk_live | `/opt/noisyless/.env` |

`.env` du VPS contient les vrais secrets, ne sort pas du serveur.

---

*-- Artemis, 2026-05-08*

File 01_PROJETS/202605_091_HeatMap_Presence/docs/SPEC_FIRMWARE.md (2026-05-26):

# Firmware Specification — NOISYLESS HeatMap #091

> **Version** : 1.0-draft | **Date** : 2026-05-23 | **Auteur** : MBHREP/ELEC-CORE
> **Cible** : ESP32-S3-MINI-1 | **Framework** : ESP-IDF + FreeRTOS
> **North Star** : SaaS récurrent par villa → revenu, pas marge hardware. Tout cycle CPU inutile = coût différé.

---

## 1. Architecture logicielle

```
┌──────────────────────────────────────────────────────────┐
│                   APPLICATION LAYER                       │
│  ┌──────────┐  ┌───────────┐  ┌──────────────────────┐   │
│  │  Task    │  │  Task     │  │  Task                │   │
│  │  Sensor  │  │  Mesh     │  │  Master (conditionnel)│   │
│  │  (driver)│  │  (ESP-NOW)│  │  Fusion spatiale     │   │
│  └────┬─────┘  └─────┬─────┘  └──────────┬───────────┘   │
│       │              │                    │               │
│  ┌────┴──────────────┴────────────────────┴───────────┐   │
│  │              Event Bus / Message Queue              │   │
│  └────────────────────────┬───────────────────────────┘   │
│                           │                               │
│  ┌────────────────────────┴───────────────────────────┐   │
│  │                  SERVICES LAYER                     │   │
│  │  Power Mgr  │  OTA  │  Health  │  Config  │  Log    │   │
│  └────────────────────────────────────────────────────┘   │
│                           │                               │
│  ┌────────────────────────┴───────────────────────────┐   │
│  │                  HAL / DRIVERS                      │   │
│  │  I2C (TMF8829) │ UART (LD6001A) │ GPIO │ ADC │ RTC │   │
│  └────────────────────────────────────────────────────┘   │
└──────────────────────────────────────────────────────────┘
```

**Principe** : même binaire pour tous les nodes. Le rôle (ToF / Radar / Master) est déterminé au boot par la config stockée en NVS.

---

## 2. Tâches FreeRTOS

### 2.1 Table des tâches

| Tâche | Priorité | Stack | Core | Période | Rôle |
|---|---|---|---|---|---|
| `sensor_task` | 3 | 4096 | 0 | Déclenchée par timer (période configurable) | Lecture capteur + formatage payload |
| `mesh_task` | 4 | 6144 | 1 | Event-driven (ESP-NOW callback) | Réception/émission mesh, master election |
| `master_task` | 2 | 8192 | 0 | Déclenchée sur réception payload complet | Recalage spatial + fusion → heatmap |
| `mqtt_task` | 3 | 4096 | 1 | Event-driven | MQTT TX (heatmap finale → AOS-Core) |
| `health_task` | 1 | 2048 | 0 | 30s | Watchdog, tension batterie, status LED |
| `ota_task` | 1 | 4096 | 0 | Déclenché sur notification | OTA SHA-256 |

### 2.2 sensor_task — commun ToF / Radar

```
boucle:
  wait(sensor_timer_semaphore)  // donné par timer HW ou duty-cycle
  
  si ROLE == TOF:
    zones = tmf8829_read_16x16()
    payload = {
      type: "tof",
      device_id: MAC,
      ts: rtc_now(),
      zones: [[dist_cm_0..15] * 16],
      confidence_pct: avg_confidence()
    }
  
  si ROLE == RADAR:
    targets = ld6001a_read_tracks()
    payload = {
      type: "radar",
      device_id: MAC,
      ts: rtc_now(),
      targets: [{x, y, z, v, confidence}],
      count: len(targets)
    }
  
  mesh_send(payload)  // unicast au master élu
  power_down_sensor()  // duty-cycle agressif si batterie
```

### 2.3 mesh_task — ESP-NOW

**Protocole mesh simplifié ESP-NOW :**

```
Trame ESP-NOW (max 250 bytes) :
┌──────┬──────┬────────┬──────────┬────────────────────┐
│ Type │  ID  │ Master │   TTL    │     Payload        │
│  1B  │  6B  │  1B    │   1B     │     max 241 bytes  │
└──────┴──────┴────────┴──────────┴────────────────────┘

Types :
  0x01 DATA       → payload capteur (ToF ou Radar)
  0x02 HEARTBEAT  → alive + battery + role
  0x03 ELECTION   → master election (bully algorithm)
  0x04 HEATMAP    → heatmap finale (master → broker bridge)
  0x05 ACK        → acquittement
```

**Master election — Bully simplifié :**

1. Au boot, chaque node écoute 2s.
2. Si aucun `HEARTBEAT` avec `master=true` → élection.
3. Le node avec l'adresse MAC la plus basse gagne.
4. Master broadcast `HEARTBEAT(master=true)` toutes les 5s.
5. Si master silencieux > 15s → réélection.
6. Master = celui qui collecte + fusionne + transmet MQTT.

**Payload DATA → mesh (max 241 bytes) :**

```json
{
  "t": 1,                    // type DATA
  "d": "a1b2c3d4e5f6",      // device_id (MAC)
  "r": 0,                    // role: 0=TOF, 1=RADAR
  "ts": 1716472800,          // timestamp RTC
  "b": 3.7,                  // tension batterie
  "p": {                     // payload capteur (compressé)
    "z": [[b64_encoded]],    // zones ToF (diff encoding)
    "c": 85                  // confidence %
  }
}
```

**Payload HEATMAP → master → MQTT (final, pas mesh) :**

```json
{
  "villa_id": "villa_001",
  "ts": 1716472800,
  "node_count": 12,
  "threshold_breach": true,
  "total_count": 15,
  "max_count": 8,
  "heatmap": {
    "resolution": "1m",
    "grid": [[x, y, count], ...],
    "dimensions": {"w": 20, "h": 30}
  },
  "zones": {
    "salon": {"count": 8, "trend": "rising"},
    "terrasse": {"count": 5, "trend": "stable"},
    "piscine": {"count": 2, "trend": "stable"}
  }
}
```

---

## 3. Master — Recalage spatial & fusion

Le master tourne sur son propre ESP32-S3. Opérations :

```
1. Réception payload de tous les nodes (window glissante 2s)
2. Recalage spatial :
   - Charger calibration pré-enregistrée : {device_id → (x, y, θ, FOV, portée)}
   - Transformer chaque grille ToF et chaque cible radar dans le repère global
3. Fusion ToF + Radar :
   - Zones intérieures : grille ToF 16×16 → maillage villa (interpolation bilinéaire)
   - Zones extérieures : points radar → grille villa (accumulation gaussienne)
   - Zone overlap (transition int/ext) : pondération linéaire selon distance bordure
4. Comptage :
   - Density-based clustering (DBSCAN simplifié, ε=0.5m, min_samples=2)
   - count = nombre de clusters
5. Heatmap finale → MQTT compressé (msgpack ou JSON minifié)
6. Alerte locale si count > seuil (buzzer? LED?), même sans connexion backend
```

**Recalage spatial — détail :**

```
Coordonnées monde :
  x_world = x_node + (x_local * cos(θ) - y_local * sin(θ))
  y_world = y_node + (x_local * sin(θ) + y_local * cos(θ))

Pour le ToF (grille 16×16) :
  - Chaque cellule (i,j) couvre un rectangle au sol
  - À H=3m, FOV 67.9°×52.8° → couverture ~4.2m × 3.0m
  - cellule ~0.26m × 0.19m

Pour le Radar (nuage de points) :
  - Chaque cible = (r, θ, φ) → (x, y, z) monde via pose du capteur
```

**Calibration stockée en NVS :** `calib` namespace. Format JSON dans une clé unique :
```json
{
  "a1b2c3d4e5f6": [2.5, 1.0, 0, 67.9, 5.0, 0],  // x, y, θ, FOV_h, FOV_v, portée
  "b2c3d4e5f6a1": [5.0, 1.0, 90, null, null, 12.0, 1]  // radar: x, y, θ, null, null, portée, type
}
```

---

## 4. Drivers — TMF8829 (I²C)

### 4.1 Init

```
I2C: 400 kHz fast mode
Adresse 7-bit : 0x29 (TMF8829 après power-up)
Config requise :
  - Mode 16×16 (register 0x14 → 0x01)
  - ITERATIONS = 500 (per datasheet, compromis portée/précision)
  - Période ranging = 33 ms (30 Hz max)
  - Seuil confidence = 5 (valeur datasheet par défaut)
```

### 4.2 Lecture

```
1. Écrire commande START (0x80 → reg 0x00)
2. Poll reg 0x01 → attendre bit READY (timeout 67ms)
3. Lire résultat : 16×16×2 bytes = 512 bytes en burst I²C
4. Décoder : chaque zone = uint16 (distance_mm), confidence dans octet de poids faible
5. Post-processing côté MCU : remplacer valeurs hors range (>5000 ou 0) par -1
```

### 4.3 Cycle batterie

```
Éveil complet : ~30 ms (PLL lock)
Ranging actif : 117 mA × 33ms = 3.86 mAs/lecture
Standby entre lectures : 65 µA
Transmission WiFi : ~80 µAh par TX

Exemple budget 1×18650 (3000 mAh) :
  - Lecture toutes les 60s → 1440 lectures/jour
  - Ranging : 1440 × 3.86 mAs = 5.56 mAh/jour
  - Standby : 23.99h × 0.065 mA = 1.56 mAh/jour
  - WiFi TX (10×/jour sur delta) : 10 × 0.08 mAh = 0.8 mAh/jour
  - Total : ~7.9 mAh/jour → ~380 jours autonomie
```

---

## 5. Drivers — LD6001A (UART)

### 5.1 Interface

```
UART : 115200 bauds, 8N1
Protocole : trames binaires (pas AT commands, protocole constructeur)
Format trame (hypothèse standard radar mmWave) :
  Header 0x55 0xAA | Length 2B | Type 1B | Payload N bytes | CRC 2B

Type 0x01 = cibles tracking
Type 0x02 = configuration ACK
Type 0x03 = status

Payload cible unique (12 bytes) :
  target_id 1B | x 2B (cm, int16) | y 2B | z 2B | velocity 2B (cm/s) | confidence 1B
```

### 5.2 Config

```
Via UART à l'init :
  1. Détection baudrate automatique (envoyer 0x55 0xAA 0x00 0x00)
  2. Lire version firmware
  3. Configurer seuil détection (sensibilité) : register SENSITIVITY = 5/10
  4. Configurer zone morte : < 50 cm ignoré (rebonds proches)
  5. Mode : continuous tracking, rapport toutes les 100ms
```

### 5.3 Consommation

```
Actif : ~1.5W (estimé module 60 GHz)
Solaire : panneau 5W + batterie 5000 mAh LiFePO4
3 jours autonomie : 5000 mAh × 3.2V = 16 Wh / 4.5 Wh/jour (1.5W × 3h peak tracking) = 3.5j
→ OK, avec marge si tracking intermittent
```

---

## 6. Power Management

### 6.1 ToF (batterie 18650)

| État | Action | Courant | Durée typique |
|---|---|---|---|
| `SLEEP` | deep sleep ESP32, TMF8829 power-down | 2 µA + 8 µA RTC | 58s (sur cycle 60s) |
| `WAKE` | boot ESP32 (fast wake from RTC) | 40 mA | 200 ms |
| `RANGING` | TMF8829 16×16 actif | 117 mA + 80 mA CPU | 33 ms |
| `PROCESS` | CPU actif, I²C burst, format payload | 80 mA | 5 ms |
| `TX` | ESP-NOW émission (si delta détecté) | 300 mA | 3 ms |
| `STANDBY` | retour attente (si heartbeat à envoyer) | 65 µA + 20 mA CPU light sleep | variable |

**Algorithme décision TX :**
```
si |count_current - count_previous| > 1 OU time_since_last_tx > 120s:
  mesh_send(payload)
  previous_count = current_count
```

### 6.2 Radar (solaire + batterie)

| État | Action | Courant |
|---|---|---|
| `ACTIVE_DAY` | LD6001A tracking continu + CPU | ~1.5W |
| `IDLE_NIGHT` | LD6001A sleep, CPU deep sleep, réveil /5min | 50 µA total |
| `ACTIVE_NIGHT` | Si alerte occupée → reprise tracking | 1.5W |
| `CHARGING` | Panneau solaire actif → charge batterie | — |

---

## 7. OTA

```
Mécanisme : double partition OTA (factory + ota_0 / ota_1)
Source : manifest JSON sur GitHub (mberthod/noisyless-heatmap-firmware)
Vérification : SHA-256 du binaire avant flash

Manifest :
{
  "version": "1.0.1",
  "url": "https://github.com/mberthod/noisyless-heatmap-firmware/releases/download/v1.0.1/heatmap-fw.bin",
  "sha256": "ab12...",
  "min_version": "1.0.0",
  "target_roles": ["all"]
}

Déclencheur : mqtt topic noisyless/{villa_id}/ota/notify → {version, url, sha256}
```

---

## 8. Config NVS

| Namespace | Clé | Type | Valeur par défaut |
|---|-----|---|---|
| `identity` | `role` | u8 | 0xFF (auto-detect) |
| `identity` | `device_id` | string | MAC |
| `calib` | `pose` | string (JSON) | null |
| `calib` | `villa_id` | string | "unassigned" |
| `sensor` | `period_ms` | u32 | 60000 (ToF), 1000 (Radar) |
| `sensor` | `duty_cycle_s` | u32 | 60 |
| `power` | `battery_low_mv` | u32 | 3200 |
| `master` | `fusion_window_ms` | u32 | 2000 |
| `master` | `threshold_count` | u8 | 10 |
| `mesh` | `channel` | u8 | 1 |
| `mqtt` | `broker_uri` | string | "mqtts://192.168.0.176:8883" |

---

## 9. Logging & Debug

```
UART0 : logs série (115200, 8N1)
Format : [LEVEL][TASK_NAME] message
Niveaux : ERROR, WARN, INFO, DEBUG

LED RGB (actif bas) :
  ROUGE   = erreur (batterie basse, capteur HS)
  VERT    = heartbeat OK (clignotement 1s)
  BLEU    = master actif
  JAUNE   = élection en cours
  BLANC   = OTA en cours

Health endpoint (MQTT, toutes les 30s si master) :
{
  "device_id": "a1b2...",
  "role": "master",
  "uptime_s": 86400,
  "battery_mv": 3700,
  "free_heap": 123456,
  "mesh_peers": 11,
  "last_sensor_ms": 1234,
  "error_count": 0
}
```

---

## 10. Failsafes

| Scénario | Comportement |
|---|---|
| Capteur I²C timeout (>100ms) | Reset I²C bus, 3 tentatives, puis alerte ERROR |
| Master down (>15s sans heartbeat) | Réélection automatique |
| WiFi AP down | Buffer circulaire 100 entrées en RTC RAM, TX en rafale au retour |
| Batterie < 3.2V | Deep sleep 10 min, TX LOW_BATTERY alert, puis extinction propre |
| OTA échouée (SHA mismatch) | Rollback partition factory |
| MQTT déconnecté > 5 min | Reconnect exponential backoff (1s, 2s, 4s... max 60s) |
| Watchdog task bloquée | HW watchdog 10s → reset complet |

---

## 11. Roadmap firmware

| Phase | Livrable | Effort |
|---|---|---|
| **P1.1** | Driver TMF8829 I²C + lecture 16×16 + payload | 3j |
| **P1.2** | Mesh ESP-NOW : découverte + HEARTBEAT + élection | 5j |
| **P1.3** | Master : collecte + recalage spatial + fusion | 5j |
| **P1.4** | Power mgmt : duty-cycle ToF + deep sleep | 3j |
| **P2.1** | Driver LD6001A UART + parsing cibles | 3j |
| **P2.2** | Intégration mesh radar + fusion ToF/radar combiné | 3j |
| **P3.1** | MQTT bridge master → AOS-Core + compression payload | 2j |
| **P4** | OTA + config NVS + calibration tooling | 3j |
| **P5** | Tests villa réelle + itération | 5j |

**Total estimé : 32 jours-homme firmware**

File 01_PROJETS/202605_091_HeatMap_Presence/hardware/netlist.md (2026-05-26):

# Netlist — Node ToF HeatMap #091
# Format: Ref, Value, Footprint, Pins, Net
# Date: 2026-05-23

## Sheet 1 — MCU (ESP32-S3-MINI-1)

U1,ESP32-S3-MINI-1,ESP32-S3-MINI-1,3V3,VDD_3V3
U1,ESP32-S3-MINI-1,ESP32-S3-MINI-1,GND,GND
U1,ESP32-S3-MINI-1,ESP32-S3-MINI-1,EN,NRST
U1,ESP32-S3-MINI-1,ESP32-S3-MINI-1,IO0,BOOT
U1,ESP32-S3-MINI-1,ESP32-S3-MINI-1,IO1,VBAT_SENSE
U1,ESP32-S3-MINI-1,ESP32-S3-MINI-1,IO2,UART0_RX
U1,ESP32-S3-MINI-1,ESP32-S3-MINI-1,IO3,UART0_TX
U1,ESP32-S3-MINI-1,ESP32-S3-MINI-1,IO4,TMF8829_INT
U1,ESP32-S3-MINI-1,ESP32-S3-MINI-1,IO8,I2C_SDA
U1,ESP32-S3-MINI-1,ESP32-S3-MINI-1,IO9,I2C_SCL
U1,ESP32-S3-MINI-1,ESP32-S3-MINI-1,IO38,LED_BLUE
U1,ESP32-S3-MINI-1,ESP32-S3-MINI-1,IO47,LED_GREEN
U1,ESP32-S3-MINI-1,ESP32-S3-MINI-1,IO48,LED_RED

## Sheet 2 — TMF8829 ToF Sensor

U2,TMF8829,OLGA-26,VDD,VDD_3V3
U2,TMF8829,OLGA-26,GND,GND
U2,TMF8829,OLGA-26,VCSEL,VDD_3V3
U2,TMF8829,OLGA-26,SDA,I2C_SDA
U2,TMF8829,OLGA-26,SCL,I2C_SCL
U2,TMF8829,OLGA-26,GPIO0,TMF8829_INT
U2,TMF8829,OLGA-26,GPIO1,NC

## Sheet 3 — Power Management

U3,AP7362-33SP,SOP-8,VIN,VBAT
U3,AP7362-33SP,SOP-8,VOUT,VDD_3V3
U3,AP7362-33SP,SOP-8,GND,GND
U3,AP7362-33SP,SOP-8,EN,VDD_3V3

U4,TP4056,SOP-8,VCC,USB_VBUS
U4,TP4056,SOP-8,BAT,VBAT
U4,TP4056,SOP-8,GND,GND
U4,TP4056,SOP-8,PROG,TP_PROG
U4,TP4056,SOP-8,CHRG,TP_CHRG
U4,TP4056,SOP-8,STDBY,TP_STDBY

U5,DW01,SOT-23-6,VDD,VBAT
U5,DW01,SOT-23-6,VSS,GND
U5,DW01,SOT-23-6,OD,FS8205_OD
U5,DW01,SOT-23-6,OC,FS8205_OC
U5,DW01,SOT-23-6,CS,VBAT_SENSE2

U6,FS8205,TSSOP-8,OD,FS8205_OD
U6,FS8205,TSSOP-8,OC,FS8205_OC
U6,FS8205,TSSOP-8,BAT-,BAT_NEG
U6,FS8205,TSSOP-8,GND,GND

## Sheet 4 — USB-C Connector

J1,USB-C_16P,USB-C_Receptacle,VBUS,USB_VBUS
J1,USB-C_16P,USB-C_Receptacle,GND,GND
J1,USB-C_16P,USB-C_Receptacle,CC1,CC1
J1,USB-C_16P,USB-C_Receptacle,CC2,CC2
J1,USB-C_16P,USB-C_Receptacle,D+,NC
J1,USB-C_16P,USB-C_Receptacle,D-,NC

## Sheet 5 — Battery

J2,18650_Holder,THT_18650,POS,VBAT
J2,18650_Holder,THT_18650,NEG,BAT_NEG

## Sheet 6 — Debug Header

J4,Header_3P,2.54mm_THT,1,UART0_TX
J4,Header_3P,2.54mm_THT,2,UART0_RX
J4,Header_3P,2.54mm_THT,3,GND

## Sheet 7 — RGB LED

D1,LED_RGB_CA,PLCC-4,R,LED_RED
D1,LED_RGB_CA,PLCC-4,G,LED_GREEN
D1,LED_RGB_CA,PLCC-4,B,LED_BLUE
D1,LED_RGB_CA,PLCC-4,A,VDD_3V3

## Sheet 8 — Passives

# Decoupling
C1,10µF,0805,1,VDD_3V3
C1,10µF,0805,2,GND
C2,10µF,0805,1,VDD_3V3
C2,10µF,0805,2,GND
C3,100nF,0603,1,VDD_3V3
C3,100nF,0603,2,GND
C4,100nF,0603,1,VDD_3V3
C4,100nF,0603,2,GND
C5,100nF,0603,1,VDD_3V3
C5,100nF,0603,2,GND
C6,100nF,0603,1,VDD_3V3
C6,100nF,0603,2,GND
C7,22µF,0805,1,VBAT
C7,22µF,0805,2,GND

# Current limiting
R1,220Ω,0603,1,LED_RED
R1,220Ω,0603,2,IO48
R2,220Ω,0603,1,LED_GREEN
R2,220Ω,0603,2,IO47
R3,220Ω,0603,1,LED_BLUE
R3,220Ω,0603,2,IO38

# I2C pull-ups
R6,10kΩ,0603,1,I2C_SDA
R6,10kΩ,0603,2,VDD_3V3
R7,10kΩ,0603,1,I2C_SCL
R7,10kΩ,0603,2,VDD_3V3

# Battery voltage divider
R4,100kΩ,0603,1,VBAT
R4,100kΩ,0603,2,VBAT_SENSE
R5,100kΩ,0603,1,VBAT_SENSE
R5,100kΩ,0603,2,GND

# Boot pull-up
R8,10kΩ,0603,1,BOOT
R8,10kΩ,0603,2,VDD_3V3

# Reset RC
R9,10kΩ,0603,1,NRST
R9,10kΩ,0603,2,VDD_3V3
C8,1µF,0603,1,NRST
C8,1µF,0603,2,GND

# TP4056 config
R10,2.4kΩ,0603,1,TP_PROG
R10,2.4kΩ,0603,2,GND

# USB-C CC resistors (5.1kΩ pulldown for 5V negotiation)
R11,5.1kΩ,0603,1,CC1
R11,5.1kΩ,0603,2,GND
R12,5.1kΩ,0603,1,CC2
R12,5.1kΩ,0603,2,GND

## Nets

### Power nets
VDD_3V3 : U1.3V3, U2.VDD, U2.VCSEL, U3.VOUT, U3.EN, D1.A, R6.2, R7.2, R8.2, R9.2, C1.1, C2.1, C3.1, C4.1, C5.1, C6.1
VBAT : U3.VIN, U4.BAT, U5.VDD, J2.POS, C7.1, R4.1
GND : U1.GND, U2.GND, U3.GND, U4.GND, U5.VSS, U6.GND, J1.GND, J2.NEG, J4.3, C1.2, C2.2, C3.2, C4.2, C5.2, C6.2, C7.2, R5.2, R10.2, R11.2, R12.2, C8.2
USB_VBUS : U4.VCC, J1.VBUS
BAT_NEG : U6.BAT-, J2.NEG

### Signal nets
I2C_SDA : U1.IO8, U2.SDA, R6.1
I2C_SCL : U1.IO9, U2.SCL, R7.1
TMF8829_INT : U1.IO4, U2.GPIO0
LED_RED : D1.R, R1.1
LED_GREEN : D1.G, R2.1
LED_BLUE : D1.B, R3.1
BOOT : U1.IO0, R8.1
NRST : U1.EN, R9.1, C8.1
VBAT_SENSE : U1.IO1, R4.2, R5.1
UART0_TX : U1.IO3, J4.1
UART0_RX : U1.IO2, J4.2
TP_PROG : U4.PROG, R10.1
TP_CHRG : U4.CHRG, NC
TP_STDBY : U4.STDBY, NC
FS8205_OD : U5.OD, U6.OD
FS8205_OC : U5.OC, U6.OC
CC1 : J1.CC1, R11.1
CC2 : J1.CC2, R12.1

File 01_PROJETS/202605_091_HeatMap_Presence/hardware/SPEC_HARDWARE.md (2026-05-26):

# Hardware Specification — Node ToF Intérieur (#091)

> **Version** : 1.0-draft | **Date** : 2026-05-23 | **Cible** : PCB 50×50mm max, 2 couches
> **Base** : Projet LVMH #062 (MCU.kicad_sch) → adapter pour batterie + TMF8829

---

## 1. Schéma bloc

```
┌─────────────────────────────────────────────────────┐
│                   BATTERY SECTION                    │
│                                                      │
│  18650 Li-Ion ──┬── TP4056 Charge Controller ── USB-C│
│  (3.7V nom)     │   + DW01 Protection IC             │
│                 │                                     │
│          ┌──────┴──────┐                              │
│          │  LDO 3.3V   │──→ VDD_3V3 (ESP + sensors)  │
│          │  AP7362-33SP │                              │
│          │  1.5A max    │                              │
│          └─────────────┘                              │
└─────────────────────────────────────────────────────┘
                         │
┌────────────────────────┼────────────────────────────┐
│                   MCU SECTION                         │
│                   ESP32-S3-MINI-1                     │
│                                                      │
│  GPIO8  ─── I²C SDA ─── TMF8829                     │
│  GPIO9  ─── I²C SCL ─── TMF8829                     │
│  GPIO4  ─── TMF8829 INT (optional)                   │
│  GPIO1  ─── ADC1_CH0 ── Battery voltage divider      │
│  GPIO38 ─── LED Blue                                 │
│  GPIO47 ─── LED Green                                │
│  GPIO48 ─── LED Red                                  │
│  GPIO0  ─── BOOT button (pull-up, GND to flash)      │
│  EN     ─── Reset + RC delay                         │
│  GPIO3  ─── UART0 TX (debug)                         │
│  GPIO2  ─── UART0 RX (debug)                         │
│                                                      │
│  Antenna: PCB trace or U.FL external                 │
└─────────────────────────────────────────────────────┘
                         │
┌────────────────────────┼────────────────────────────┐
│                 SENSOR SECTION                        │
│                   TMF8829 dToF                         │
│                                                      │
│  I²C addr 0x29                                       │
│  VDD = 3.3V                                          │
│  VCSEL = 3.3V (shared with VDD for simplicity)       │
│  GPIO0 = INT (optional, not used in V1)              │
│  GPIO1 = not connected                               │
│  Decoupling: 100nF + 10µF on VDD, 100nF on VCSEL    │
└─────────────────────────────────────────────────────┘
```

---

## 2. BOM (Bill of Materials)

| Ref | Qty | Value | Package | Description |
|-----|-----|---|---|---|
| **MCU & Wireless** | | | | |
| U1 | 1 | ESP32-S3-MINI-1 | SMD module | Espressif, 8MB flash, PCB antenna |
| **ToF Sensor** | | | | |
| U2 | 1 | TMF8829 | OLGA-26 | ams-OSRAM dToF, I²C |
| **Power** | | | | |
| U3 | 1 | AP7362-33SP | SOP-8 | 3.3V LDO, 1.5A |
| U4 | 1 | TP4056 | SOP-8 | Li-Ion charger, USB-C input |
| U5 | 1 | DW01 + FS8205 | SOT-23-6 + TSSOP-8 | Battery protection IC |
| **Connectors** | | | | |
| J1 | 1 | USB-C 16-pin | USB-C receptacle | Power only (no data) |
| J2 | 1 | 18650 holder | THT | Battery holder (or solder tabs) |
| J3 | 1 | U.FL | SMD | Optional external antenna |
| J4 | 1 | 3-pin header | 2.54mm | UART debug (TX/RX/GND) |
| **LED** | | | | |
| D1 | 1 | LED RGB Common Anode | 5050 PLCC-4 | Status indicator |
| R1,R2,R3 | 3 | 220Ω | 0603 | LED current limit |
| **Passives** | | | | |
| C1,C2 | 2 | 10µF | 0805 | VDD decoupling |
| C3,C4,C5 | 3 | 100nF | 0603 | VDD decoupling |
| C6 | 1 | 100nF | 0603 | VCSEL decoupling |
| C7 | 1 | 22µF | 0805 | Battery bulk cap |
| R4 | 1 | 100kΩ | 0603 | Voltage divider R1 |
| R5 | 1 | 100kΩ | 0603 | Voltage divider R2 (VBAT/2) |
| R6,R7 | 2 | 10kΩ | 0603 | I²C pull-ups |

---

## 3. Instructions — Modification du projet LVMH

### 3.1 Ouvrir le projet LVMH dans KiCad
```
kicad ~/Kdrive/01_CLIENTS/LVMH/202510_Projet_062_LVMH_HeatMap/03_CAO/01_Schemas/202510_Projet_062_LVMH_HeatMap/202510_Projet_062_LVMH_HeatMap.kicad_pro
```

### 3.2 Sauvegarder comme nouveau projet
- File → Save As → `~/Kdrive/01_CLIENTS/NOISYLESS/202605_091_HeatMap_Presence/hardware/kicad/heatmap-tof.kicad_pro`

### 3.3 Feuilles à supprimer
- `ETHERNET.kicad_sch` — plus de PoE/W5500
- `RADAR.kicad_sch` — le radar est un node séparé

### 3.4 Feuille MCU — modifications
- **Garder** : ESP32-S3-MINI-1, découplage, boot, reset, UART debug, LED RGB
- **Supprimer** : connecteur RJ45, W5500, circuit PoE (TPS2375)
- **Remplacer** : alim secteurs → alim batterie 18650

### 3.5 Nouvelle feuille — alim batterie
- TP4056 + USB-C pour charger
- Protection DW01 + FS8205
- AP7362-33SP LDO 3.3V
- Diviseur résistif sur ADC1_CH0 (GPIO1)

### 3.6 Nouvelle feuille — TMF8829
- I²C sur GPIO8/GPIO9 (partagés avec le bus existant)
- Alim 3.3V avec découplage
- Pull-ups 10kΩ sur SDA/SCL

### 3.7 Layout
- Format max 50×50mm
- Antenne ESP32 en bord de carte, zone dégagée (pas de cuivre)
- TMF8829 centré, optique vers le bas (bottom layer si possible, ou cutout)
- USB-C sur un bord pour accès boîtier
- UART debug accessible via pastilles ou header 3-pin

---

## 4. Notes de design

### Antenne ESP32
- PCB trace antenna intégrée au module MINI-1
- Zone keep-out : pas de cuivre sous l'antenne ni à <5mm autour, tous les layers
- Option U.FL pour antenne externe si boîtier métallique

### TMF8829 layout
- Optique dégagée : ouverture dans le boîtier + fenêtre
- Pas de composants hauts <2mm autour du capteur
- Zone de garde : pas de vias sous le capteur

### Batterie
- TP4056 charge à 500mA par défaut (PROG resistor 2.4kΩ)
- DW01 coupe à 2.4V (décharge profonde) et 4.28V (survoltage)
- LDO AP7362 dropout ~400mV à 1A → OK avec 3.7V Li-Ion vers 3.3V

### Connecteurs
- USB-C : VBUS, GND, CC1, CC2 uniquement (pas de data)
- CC1/CC2 : pull-down 5.1kΩ pour négociation 5V
- 18650 : prévoir soudure sur pastilles ou holder clipsable

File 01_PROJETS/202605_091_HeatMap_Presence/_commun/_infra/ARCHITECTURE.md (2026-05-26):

# NOISYLESS - Architecture Technique

## Vue d'ensemble

NOISYLESS est une plateforme IoT de surveillance d'occupation par capteurs ToF (Time of Flight) et Radar. Le système collecte les données de présence, génère des heatmaps en temps réel, et alerte en cas de surpopulation.

**Projet :** #091 - HeatMap Présence  
**Serveur :** 91.99.26.43 (OVH)  
**Domaine :** platform.noisyless.com

---

## Architecture Logicielle

```
┌─────────────────────────────────────────────────────────────────────┐
│                         NOISYLESS PLATFORM                          │
├─────────────────────────────────────────────────────────────────────┤
│                                                                     │
│  ┌──────────────┐     ┌──────────────┐     ┌──────────────┐        │
│  │   Devices    │────▶│    Mosquitto │────▶│  MQTT Ingest │        │
│  │  (ToF/Radar) │ MQTT│   Broker     │ MQTT│   Service    │        │
│  │  ESP32-S3    │     │  :1883/:8883 │     │              │        │
│  └──────────────┘     └──────────────┘     └──────┬───────┘        │
│                                                    │                 │
│                                                    ▼                 │
│                                             ┌──────────────┐        │
│                                             │  TimescaleDB │        │
│                                             │  PostgreSQL  │        │
│                                             │    :5432     │        │
│                                             └──────┬───────┘        │
│                                                    │                 │
│           ┌─────────────────────────────────────────┼─────────┐     │
│           │                 │                       │         │     │
│           ▼                 ▼                       ▼         ▼     │
│    ┌────────────┐   ┌────────────┐          ┌──────────┐ ┌───────┐ │
│    │  Heatmap   │   │   Alert    │          │ FastAPI  │ │ Nginx │ │
│    │ Aggregator │   │   Engine   │          │ Backend  │ │ Proxy │ │
│    │            │   │            │          │          │ │       │ │
│    └────────────┘   └─────┬──────┘          └────┬─────┘ └───┬───┘ │
│                           │                      │           │     │
│                           ▼                      │           │     │
│                    ┌─────────────┐                │           │     │
│                    │  Telegram   │                │           │     │
│                    │   Alerts    │                │           │     │
│                    └─────────────┘                │           │     │
│                                                   │           │     │
│                                             ┌─────┴───────────┴───┐ │
│                                             │   HTTPS :443      │ │
│                                             │   HTTP  :80       │ │
│                                             └─────────┬─────────┘ │
│                                                       │           │
└───────────────────────────────────────────────────────┼───────────┘
                                                        │
                                              ┌─────────▼─────────┐
                                              │   Web Client      │
                                              │   Mobile App      │
                                              │   Third-party API │
                                              └───────────────────┘
```

---

## Composants

### 1. MQTT Broker (Eclipse Mosquitto)

**Image :** `eclipse-mosquitto:2`  
**Ports :** 1883 (MQTT), 8883 (MQTT TLS)  
**Rôle :** Message broker pour les devices IoT

**Topics :**
- `noisyless/+/heatmap` - Données de présence des capteurs
- `noisyless/+/config` - Configuration OTA (futur)
- `noisyless/+/status` - Télémétrie devices (futur)

**Config :** `/opt/noisyless/mosquitto/config/mosquitto.conf`

---

### 2. TimescaleDB (PostgreSQL + Time Series)

**Image :** `timescale/timescaledb:latest-pg16`  
**Port :** 5432 (localhost only)  
**Rôle :** Base de données time-series pour les mesures

**Schéma :** `noisyless`

**Tables principales :**

| Table | Description | Rétention |
|---|---|---|
| `users` | Utilisateurs plateforme | Permanent |
| `devices` | Enregistrement des capteurs | Permanent |
| `user_devices` | Liaison users/devices | Permanent |
| `measurements` | Mesures brutes (hypertable) | 90 jours |
| `heatmap_agg_5min` | Heatmaps agrégées 5min | 30 jours |
| `alert_thresholds` | Seuils d'alerte par villa | Permanent |

**Hypertable :** `measurements` partitionné par `time`

---

### 3. MQTT Ingest Service

**Langage :** Python 3.11  
**Source :** `services/mqtt-ingest/main.py`  
**Rôle :** Subscribe MQTT → Insert DB

**Fonctionnement :**
1. Subscribe au topic `noisyless/+/heatmap`
2. Parse le payload JSON
3. Extrait `device_id` du topic
4. Insert dans `noisyless.measurements`

**Payload attendu :**
```json
{
  "villa_id": "villa_001",
  "total_count": 5,
  "heatmap": {"grid": [[0,1,2],[1,3,1],[0,1,0]]},
  "battery_mv": 3300
}
```

---

### 4. Heatmap Aggregator

**Langage :** Python 3.11  
**Source :** `services/heatmap-agg/main.py`  
**Rôle :** Agrège les mesures en heatmaps 5min

**Fonctionnement :**
1. Toutes les 60 secondes
2. Lit les mesures des 5 dernières minutes
3. Regroupe par `villa_id` et `zone`
4. Fusionne les grids (moyenne)
5. Insert dans `heatmap_agg_5min`

**Fenêtre :** 300 secondes (configurable via `AGG_WINDOW_SECONDS`)

---

### 5. Alert Engine

**Langage :** Python 3.11  
**Source :** `services/alert-engine/main.py`  
**Rôle :** Surveillance seuils → Notifications

**Fonctionnement :**
1. Toutes les 30 secondes
2. Lit `alert_thresholds` par villa
3. Compare avec dernière aggregation
4. Si `max_count > threshold` → Alert Telegram

**Notifications :**
- Telegram Bot (configurable)
- Anti-spam : 1 alerte max par fenêtre 5min

---

### 6. FastAPI Backend

**Langage :** Python 3.11 + FastAPI  
**Source :** `services/api/main.py`  
**Rôle :** API REST pour clients web/mobile

**Authentification :** JWT (HS256)

**Endpoints :**

| Method | Endpoint | Description | Auth |
|---|---|---|---|
| GET | `/health` | Health check | ❌ |
| GET | `/api/devices` | Liste des devices | ✅ |
| POST | `/api/devices` | Nouveau device | ✅ |
| GET | `/api/devices/{id}/live` | Données temps réel | ✅ |
| GET | `/api/devices/{id}/timeline` | Historique (24h) | ✅ |
| GET | `/api/villas/{id}/heatmap` | Heatmap agrégée | ✅ |

**Sécurité :**
- JWT expiry : 30 minutes
- Password hashing : bcrypt
- CORS : à configurer

---

### 7. Nginx Reverse Proxy

**Image :** `nginx:alpine`  
**Ports :** 80 (HTTP), 443 (HTTPS)  
**Rôle :** Reverse proxy + SSL termination

**Configuration :**
- HTTP → Redirect HTTPS
- HTTPS → Proxy vers API (:8000)
- Static files : `/var/www/static`
- SSL : Let's Encrypt (Cloudflare DNS)

**Certificats :**
- Domaine : `platform.noisyless.com`, `api.platform.noisyless.com`
- Validité : 90 jours (renouvellement auto mensuel)
- Stockage : `/opt/noisyless/nginx/ssl`

---

## Infrastructure

### Serveur

| Spécification | Valeur |
|---|---|
| Fournisseur | OVH |
| IP | 91.99.26.43 |
| OS | Linux (à préciser) |
| Docker | v27+ |
| DNS | Cloudflare |

### DNS (Cloudflare)

| Type | Name | Content | Proxy |
|---|---|---|---|
| A | platform | 91.99.26.43 | DNS only |
| A | api.platform | 91.99.26.43 | DNS only |

### SSL/TLS

- **Autorité :** Let's Encrypt
- **Validation :** DNS-01 (Cloudflare API)
- **Renouvellement :** Cron mensuel (1er à 03:00)
- **Script :** `/opt/noisyless/renew-ssl.sh`

---

## Réseau Docker

**Network :** `noisyless-net` (bridge)

**Communication interne :**

| Service | Port | Accessible depuis |
|---|---|---|
| mosquitto | 1883 | mqtt-ingest |
| timescaledb | 5432 | Tous services |
| api | 8000 | nginx uniquement |
| nginx | 80/443 | Internet |

---

## Variables d'environnement

### Fichier `.env` (à créer sur le serveur)

```bash
# Database
DB_PASSWORD=noisyless_secret_password

# JWT
JWT_SECRET=noisyless_jwt_super_secret_key_2026
JWT_EXPIRY_MINUTES=30

# Telegram Alerts
TELEGRAM_BOT_TOKEN=<token>
TELEGRAM_CHAT_ID=<chat_id>
```

### Emplacement
`/opt/noisyless/.env`

---

## Déploiement

### Prérequis
- Docker & Docker Compose
- SSH access : `~/.ssh/id_ed25519`
- Cloudflare API token

### Commandes

```bash
# Connexion au serveur
ssh -i ~/.ssh/id_ed25519 noisyless@91.99.26.43

# Démarrage
cd /opt/noisyless
docker compose up -d

# Logs
docker compose logs -f

# Redémarrage
docker compose restart

# Arrêt
docker compose down
```

---

## Surveillance

### Logs

```bash
# Tous services
docker compose logs -f

# Service spécifique
docker compose logs -f mqtt-ingest

# Nginx
docker exec noisyless-nginx tail -f /var/log/nginx/access.log
```

### Santé

```bash
# API health
curl -k https://platform.noisyless.com/health

# DB connection
docker exec noisyless-timescaledb pg_isready -U noisyless

# MQTT broker
docker exec noisyless-mosquitto mosquitto_sub -t '#' -v
```

### Métriques (à implémenter)

- CPU/RAM par container
- DB size & growth
- MQTT messages/sec
- API response time
- Error rate

---

## Sécurité

### En place

- ✅ HTTPS (Let's Encrypt)
- ✅ JWT authentication API
- ✅ DB password protégée
- ✅ TimescaleDB localhost only
- ✅ Container isolation (network)

### À améliorer

- [ ] MQTT authentication (username/password)
- [ ] MQTT TLS (port 8883)
- [ ] Rate limiting API
- [ ] Firewall rules (ufw)
- [ ] Fail2ban
- [ ] Backup automatique DB
- [ ] Monitoring (Prometheus/Grafana)

---

## Sauvegarde

### Base de données

```bash
# Backup manuel
docker exec noisyless-timescaledb pg_dump -U noisyless noisyless > backup_$(date +%Y%m%d).sql

# Restore
cat backup_YYYYMMDD.sql | docker exec -i noisyless-timescaledb psql -U noisyless noisyless
```

### À automatiser

- [ ] Backup quotidien (cron)
- [ ] Rotation 7 jours
- [ ] Stockage externe (S3, etc.)

---

## Évolution

### Roadmap

**V1.1 - Sécurité MQTT**
- Authentification broker
- Chiffrement TLS
- Certificats devices

**V1.2 - Dashboard**
- Interface web temps réel
- Visualisation heatmaps
- Historique graphs

**V1.3 - Firmware OTA**
- Mise à jour devices à distance
- Topic `noisyless/+/ota`

**V2.0 - Multi-tenant**
- Isolation par client
- Quotas & billing
- White-label

---

## Dépannage

### Problèmes courants

**API ne répond pas :**
```bash
docker compose logs api
docker compose restart api
```

**DB connection failed :**
```bash
docker compose ps timescaledb
docker compose logs timescaledb
```

**Certificat expiré :**
```bash
/opt/noisyless/renew-ssl.sh
```

**MQTT messages non reçus :**
```bash
docker exec noisyless-mosquitto mosquitto_sub -t 'noisyless/+/heatmap' -v
```

---

## Contact

**Développeur :** NOISYLESS Team  
**Email :** contact@noisyless.com  
**Documentation :** `/opt/noisyless/README.md`

---

*Dernière mise à jour : 24 Mai 2026*

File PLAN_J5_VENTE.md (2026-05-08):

# NOISYLESS — Plan J+5 : Systeme pret a vendre

**Date**: 2026-05-07
**Objectif**: Premier capteur vendu et fonctionnel en J+5 (12 mai 2026)
**Temps Mathieu**: 2-3h max (demain J+1), reste = Artemis autonome

---

## AUDIT — Etat actuel

### Firmware (ESP32-S3, PlatformIO)
- **Board**: ESP32-S3-DevKitC-1, flash 8MB, partitions OTA
- **Capteurs**: BME680 (BSEC2: temp, hum, pression, gaz, IAQ, CO2eq, VOC), LD2410 (radar presence/distance), 2x lux analogiques, 2x microphones analogiques (pic-a-pic)
- **Comm**: WiFi + MQTT (PubSubClient) → JSON toutes les 10s
- **Topic MQTT**: `esp32/noisyless/<MAC>/datas`
- **Broker MQTT**: `85.215.145.44:1883` (user: esp32) ← **PROBLEME: ce n'est PAS le VPS prod (91.99.26.43)**
- **OTA**: via manifest GitHub (canal stable), SHA256 verifie
- **WiFi**: SSID/pass **hardcodes** dans le code (TP-Link_B150) ← **BLOQUANT pour client**
- **WiFiManager**: lib presente dans platformio.ini mais **pas utilisee** dans main.cpp

### Plateforme (VPS Hetzner 91.99.26.43)
- **API**: FastAPI + psycopg3 + TimescaleDB, auth magic-link email, JWT 12h
- **Dashboard**: Vue3 (static HTML), affiche devices + live + timeline
- **Mosquitto**: container Docker present mais **pas demarre**
- **MQTT Ingest**: **N'EXISTE PAS** — pas de pont MQTT → DB
- **Stripe**: 4 Payment Links crees (Basic 99€, Basic abo 4.99€/m, Premium 149€, Premium abo 7.99€/m)
- **Site marketing noisyless.com**: heberge OVH, **pas les CTAs Stripe**
- **Webhook Stripe**: **aucun** — achat ne cree pas de compte auto

### Schema DB `measurements`
| Champ DB | Source firmware | Mapping |
|---|---|---|
| temp | temperature_c | direct  |
| humidity | humidity_pct | direct  |
| gas_resistance | gas_ohms | direct  |
| iaq | iaq (float→int) | cast |
| presence | presence | direct  |
| distance_cm | target_distance_cm | direct  |
| db_avg | sound_mic1_pp | **A CONVERTIR** (ADC raw → dB) |
| db_peak | sound_mic2_pp | **A CONVERTIR** |
| lux1 | lux1_raw | **A CALIBRER** (ADC raw → lux) |
| lux2 | lux2_raw | **A CALIBRER** |

---

## GAPS CRITIQUES (bloquent la vente)

1. **WiFi hardcode** → le client ne peut pas configurer son reseau
2. **Broker MQTT pointe vers mauvais serveur** (85.215.145.44 ≠ VPS 91.99.26.43)
3. **Pas de service MQTT ingest** → donnees firmware n'arrivent jamais en DB
4. **Mosquitto pas demarre** sur le VPS
5. **Conversion ADC mic → dB manquante** → dashboard affiche des valeurs brutes
6. **Pas de tunnel acquisition** → client ne peut pas acheter + recevoir son capteur configure
7. **device_id hardcode** NL-001 → chaque capteur doit avoir un ID unique

---

## PLAN J+5

### J+0 (aujourd'hui 7 mai) — Artemis seul, prep
**Duree Mathieu: 0h**

- [x] Audit firmware + plateforme (ce document)
- [ ] **ARTEMIS**: Creer `mqtt_ingest.py` — service Python qui:
  - Subscribe MQTT `esp32/noisyless/+/datas`
  - Parse JSON firmware
  - Convertit mic_pp → dB approximatif (formule: `20 * log10(pp/4095 * Vref)` + offset calibration)
  - Convertit lux_raw → lux approximatif (lineaire ADC)
  - INSERT dans `measurements` TimescaleDB
  - UPDATE `devices.last_seen`
- [ ] **ARTEMIS**: Creer Dockerfile + ajouter au docker-compose VPS
- [ ] **ARTEMIS**: Preparer config Mosquitto (auth, ports)

### J+1 (8 mai) — Mathieu 2-3h
**Ce qui necessite Mathieu:**

1. **WiFi capteur physique** (15 min):
   - Brancher le NOISYLESS sur ton reseau actuel (partage de connexion ou WiFi local)
   - Me donner le SSID + password pour que je modifie credentials.h temporairement
   - OU: je compile un firmware avec WiFiManager (captive portal) et tu flashe via USB

2. **Deploiement VPS** (30 min de commandes sudo):
   - `scp` les fichiers mqtt_ingest sur le VPS
   - Demarrer Mosquitto + mqtt-ingest containers
   - Verifier que les data arrivent en DB

3. **Validation end-to-end** (30 min):
   - Capteur branche → data visible sur platform.noisyless.com/dashboard
   - Screenshot = preuve que ca marche

4. **DNS optionnel** (10 min):
   - Ajouter un record A `mqtt.noisyless.com` → 91.99.26.43
   - Pour que le firmware pointe vers un hostname (pas une IP)

### J+2 (9 mai) — Artemis seul
- [ ] Integrer WiFiManager dans le firmware (captive portal "NOISYLESS-Setup")
  - Client branche le capteur → WiFi "NOISYLESS-Setup" apparait
  - Se connecte → page de config → entre son SSID/pass
  - Sauvegarde en NVS (flash), reboot, se connecte au WiFi client
- [ ] Device ID unique par capteur (base MAC address)
- [ ] LED status: rouge=pas WiFi, bleu=connecte MQTT, vert=tout OK
- [ ] Deployer firmware OTA manifest pour canal "beta"

### J+3 (10 mai) — Artemis seul
- [ ] Page acquisition noisyless.com:
  - Landing page avec les 4 produits Stripe
  - Formulaire pre-commande (email → magic-link plateforme)
  - Integration Payment Links existants
- [ ] Webhook Stripe basique:
  - A la completion du paiement → creer user + device dans la plateforme
  - Envoyer email "Votre capteur est en cours de preparation"
- [ ] Onboarding premiere connexion (profil user)

### J+4 (11 mai) — Artemis seul
- [ ] Test complet du tunnel: achat Stripe → compte cree → capteur lie → data live
- [ ] Fix bugs trouves
- [ ] Calibration son/lumiere (ajuster formules de conversion)
- [ ] Rate limit sur magic-link (securite)
- [ ] Doc utilisateur minimaliste (1 page: brancher → configurer WiFi → voir dashboard)

### J+5 (12 mai) — GO LIVE
- [ ] Premier capteur pret a expedier
- [ ] Tunnel acquisition fonctionnel
- [ ] Dashboard affiche donnees reelles
- [ ] Prospection: premiers emails/messages aux leads

---

## BESOINS MCP / SKILLS SUPPLEMENTAIRES

### Ce dont j'ai besoin pour etre autonome:

1. **Acces SSH au VPS NOISYLESS** (91.99.26.43)
   - Pour deployer mqtt_ingest, demarrer mosquitto, modifier compose
   - Soit cle SSH, soit commandes sudo a coller

2. **Acces PlatformIO / compilation firmware**
   - Est-ce que PlatformIO est installe sur cette machine?
   - Sinon: `pip install platformio` ou je prepare le firmware.bin et tu flashe

3. **Acces DNS OVH noisyless.com**
   - Pour ajouter `mqtt.noisyless.com` (optionnel, peut utiliser IP directe)

4. **Acces au code source noisyless.com (site marketing OVH)**
   - Pour integrer les CTAs Stripe + page acquisition

### Ce que je peux faire sans toi:
- Ecrire tout le code (mqtt_ingest, firmware WiFiManager, webhook Stripe, landing page)
- Preparer les configs Docker
- Compiler le firmware (si PlatformIO disponible)
- Tester localement

---

## DECISION A PRENDRE (Mathieu)

**Option A** — MVP rapide (J+1 = demain):
- Firmware garde WiFi hardcode (tu configures a la main pour chaque client)
- Broker MQTT = IP directe du VPS
- Pas de WiFiManager, pas de captive portal
- **Avantage**: on valide le flux data end-to-end demain

**Option B** — Produit fini (J+3):
- WiFiManager captive portal
- Device ID auto (MAC)
- LED status
- **Avantage**: experience client pro, mais 2 jours de plus

**Recommandation**: Option A demain pour valider, puis Option B en parallele pour J+3.

---

*-- Artemis, 2026-05-07*

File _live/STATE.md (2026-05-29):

# NOISYLESS v1 — État des lieux (29 mai 2026)

> Snapshot complet du système en production. Capture de ce qui tourne réellement
> sur le VPS Hetzner (91.99.26.43), synchronisé avec le repo GitHub.

---

## Architecture production

```
noisyless.com (marketing)
  └── nginx → /var/www/static/index.html + produits/, cas-usage/, etc.

platform.noisyless.com (dashboard)
  └── nginx → /var/www/static/platform.html
                ├── /admin.html (admin panel)
                ├── /dashboard.html (user dashboard)
                ├── /api/* → api container:8000
                └── /admin/* → api container:8000/admin/
```

## Conteneurs Docker (8)

| Conteneur | IP | Status | Rôle |
|---|----|---|---|
| noisyless-api | 172.18.0.2 | Up 18h | FastAPI backend (auth, devices, shop, admin) |
| noisyless-timescaledb | 172.18.0.3 | Up 4d | TimescaleDB PG16 |
| noisyless-alert-engine | 172.18.0.4 | Up 4d | ✅ Alertes seuils |
| noisyless-heatmap-agg | 172.18.0.5 | Up 4d | Agrégation HeatMap 5 min |
| noisyless-nginx | 172.18.0.6 | Up 16h | Reverse proxy (2 domaines) |
| noisyless-mosquitto | 172.18.0.7 | Up 4d | Broker MQTT (1883, 8883) |
| noisyless-mqtt-ingest | 172.18.0.8 | Up 4d | MQTT → DB (HeatMap data) |
| noisyless-env-ingest | 172.18.0.9 | Up 45h | ESP32 → DB (env data) |

## DNS / Réseau

- **Hetzner VPS** : Ubuntu 7.0.0, 38GB disk (8G used), aarch64
- **iptables / firewall** : 80, 443, 1883, 8883 ouverts
- **SSL** : LetsEncrypt via certbot (auto-renouvellement)

---

## Pages web — Site public (noisyless.com)

### Accueil
- `/` → index.html ✅ 200

### Pages légales
- `/faq.html` ✅
- `/cgv.html` ✅
- `/confidentialite.html` ✅
- `/mentions-legales.html` ✅
- `/annule.html` ✅
- `/merci.html` ✅

### Produits
- `/produits/heatmap.html` ✅
- `/produits/heatmap-indoor.html` ✅
- `/produits/heatmap-outdoor.html` ✅
- `/produits/heatmap-property-pack.html` ✅
- `/produits/noisyless-simple.html` ✅

### Cas d'usage
- `/cas-usage/conciergerie.html` ✅
- `/cas-usage/hospitality-resort.html` ✅
- `/cas-usage/immobilier-institutionnel.html` ✅
- `/cas-usage/villa-premium.html` ✅
- ❌ **URLs attendues** : copropriete, bureaux, logement-social, residence-senior → 404

### Comparatif
- `/comparatif/heatmap-vs-camera.html` ✅
- `/comparatif/heatmap-vs-detecteur.html` ✅
- `/comparatif/heatmap-vs-minut.html` ✅

### Technologie
- `/technologie/intelligence-spatiale.html` ✅
- `/technologie/privacy-by-design.html` ✅
- `/technologie/reseau-maille.html` ✅

### CTA
- `/boutique.html` ✅
- `/pilote.html` ✅
- `/pilote-heatmap.html` ✅
- `/precommande.html` ✅
- `/conciergerie.html` ✅
- `/dashboard.html` ✅

### Blog (10 articles)
- `/blog/index.html` ✅
- `/blog/channel-managers-monitoring.html`
- `/blog/degat-des-eaux-vanne-coupure-automatique.html`
- `/blog/detecter-fete-airbnb-sans-camera.html`
- `/blog/detecteur-bruit-airbnb-legal.html`
- `/blog/minut-vs-noisyless-comparatif.html`
- `/blog/nuisances-sonores-copropriete.html`
- `/blog/rgpd-capteurs-location-conformite.html`
- `/blog/suroccupation-location-courte-duree.html`
- `/blog/vapotage-cigarette-location-detection.html`

### SEO ❌
- `/robots.txt` → **404** (non déployé)
- `/sitemap.xml` → **404** (non déployé)
- Pourtant listés dans la config nginx du skill → à déployer

---

## Pages web — Plateforme (platform.noisyless.com)

- `/` → platform.html ✅ 200
- `/admin.html` ✅ 200
- `/dashboard.html` ✅

---

## Base de données

### Tables (schéma `noisyless.`)

| Table | Rôle |
|---|---|
| users | 20 comptes |
| devices | 8 devices (0 online) |
| user_devices | Liaison users ↔ devices |
| measurements | Données environnementales (hypertable) |
| heatmap_agg_5min | Agrégats HeatMap 5 min |
| firmware_versions | 5 versions enregistrées |
| ota_deployments | Déploiements OTA |
| alert_thresholds | Seuils d'alerte |
| device_health | Santé des devices |
| auth_tokens | Tokens d'authentification |
| orders | Commandes boutique |
| order_items | Lignes de commande |

### Firmware versions en DB

| Version | SHA256 |
|---|---|
| 0.0.1 | eca3b180ec39b86c5... |
| 0.0.2 | b366af87ffa4e2e2d... |
| 1.0.1 | afde99ed3d12cb8e2... |
| 1.0.2 | 1280dfb513ccea72c... |
| 1.1.0-wifimanager | 703182fd39b96e30f... |

### Firmware binaires sur VPS

| Fichier | Taille | Statut |
|---|---|---|
| noisyless-v0.0.1.bin | 1,083,440 | Déployé |
| noisyless-v0.0.2.bin | 1,083,472 | Déployé |
| noisyless-v0.0.3.bin | 1,083,984 | Déployé |
| noisyless-v1.0.1.bin | 879,504 | Déployé |
| noisyless-v1.0.2.bin | 879,376 | Déployé |
| noisyless-v1.1.0-wifimanager.bin | 1,083,056 | WiFi Manager intégré |
| firmware.bin | 1,083,984 | Copie sympa de v0.0.3 |

---

## Services backend (Python/FastAPI)

### API (12 fichiers)
- `main.py` — App FastAPI, routes, DB pool
- `auth.py` — Inscription, login, vérification email, reset password (bcrypt, JWT)
- `admin.py` — Panel admin : devices, overview, firmware, users (⚠️ seulement sur VPS)
- `devices.py` — CRUD devices, registration, claim
- `customer.py` — Espace client
- `emails.py` — Envoi emails (SMTP OVH)
- `pilot.py` — Programme pilote
- `shop.py` — Boutique Stripe
- `shop_webhook.py` — Webhooks Stripe
- `Dockerfile`, `requirements.txt`

### Micro-services (4)
- `mqtt-ingest/` — HeatMap data (MQTT → TimescaleDB)
- `env-ingest/` — ESP32 capteurs environnement (MQTT → TimescaleDB)
- `heatmap-agg/` — Agrégation 5 min des heatmaps
- `alert-engine/` — Alertes seuils (Telegram)

---

## Bugs v1 connus

### 🔴 alert-engine : ConnectionRefusedError
```
ConnectionRefusedError: [Errno 111] Connect call failed ('172.18.0.3', 5432)
```
- L'alert-engine essaie de se connecter à la DB sur 172.18.0.3:5432 mais la connexion est refusée
- TimescaleDB pourtant up (healthy) sur la même IP
- **À investiguer** : problème de réseau Docker, dépendance de démarrage, ou changement d'IP

### 🔴 API : send_verification_email() parameter mismatch
```
TypeError: send_verification_email() missing 1 required positional argument: 'background_tasks'
```
- Dans `auth.py`, la fonction attend un paramètre `background_tasks: BackgroundTasks`
- Mais elle est appelée sans ce paramètre quelque part
- **Fix** : aligner l'appel dans main.py ou les routes

### 🟡 heatmap-agg : No data for window
- L'agrégateur tourne toutes les 5 min mais ne trouve aucune donnée
- Pourtant mqtt-ingest reçoit bien des messages HeatMap → les données arrivent
- **À investiguer** : peut-être un décalage de timestamp, ou les heatmap_agg_5min ne sont pas peuplées

### 🟡 8 devices offline
- Tous les devices enregistrés en DB ont status = 'offline'
- Dernière activité : NL-B43A45B7A9B0 (env-ingest reçoit encore des datas)
- **Hypothèse** : heartbeat non mis à jour, ou les ESP32 déconnectés

### 🟡 4 pages cas-usage 404
- Les URLs attendues (copropriete, bureaux, logement-social, residence-senior) ne correspondent pas aux fichiers déployés (conciergerie, hospitality-resort, immobilier-institutionnel, villa-premium)
- **Deux choix** : renommer les fichiers ou corriger les URLs dans le site

### 🟡 robots.txt + sitemap.xml 404
- Pas déployés sur le VPS alors qu'ils étaient listés dans la config nginx prévue
- **Fix** : générer et déployer

---

## GitHub vs VPS — Écarts résolus

Ce commit synchronise tous les fichiers manquants entre le VPS et le repo :

| Fichier | Source | Destination |
|---|---|---|
| `admin.py` | VPS only | _infra + backend |
| `env-ingest/` (3 fichiers) | VPS only | _infra |
| `platform.html` | VPS only | _infra + web/site |
| `admin.html` | VPS only | _infra + web/site |
| `dashboard.html` | VPS only | _infra + web/site |
| `pilote-heatmap.html` | VPS only | _infra + web/site |
| `precommande.html` | VPS only | _infra + web/site |
| `conciergerie.html` | VPS only | _infra + web/site |
| `produits/heatmap-*.html` (3) | VPS only | _infra + web/site |
| `cas-usage/*.html` (4) | VPS only | _infra + web/site |
| `comparatif/*.html` (3) | VPS only | _infra + web/site |
| `technologie/*.html` (3) | VPS only | _infra + web/site |
| `nginx.conf` | Updated VPS | _infra |
| `docker-compose.yml` | Updated VPS | _infra |
| `mosquitto.conf` | VPS | _infra |
| `firmware/stable.json` | VPS | _infra |
| `firmware/latest.json` | VPS only | _infra |
| `auth.py`, `devices.py`, `main.py` | VPS version | _infra (remplace) |

**Notes :**
- Les fichiers `index.html`, `faq.html`, etc. déjà dans le repo n'ont pas été écrasés (ils sont présents dans `_live/static` pour info)
- Les binaires firmware ne sont pas commités dans `_live/` (trop lourds), mais copiés dans `01_PROJETS/202604_089_Capteur_Environnemental_V1/05_FIRMWARE/` et `ota/`
- Le dossier `_live/` est un snapshot de référence — pas un dossier d'infrastructure actif

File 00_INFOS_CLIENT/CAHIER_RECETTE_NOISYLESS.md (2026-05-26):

# CAHIER DE RECETTE — NOISYLESS
## État des lieux complet au 25/05/2026

> **Objet** : Ce document dresse l'état exhaustif de tout ce qui a été réalisé sur le projet NOISYLESS.  
> **Usage** : Base pour la rédaction du cahier des charges et du dossier de conception.  
> **Méthode** : Audit en direct du serveur Hetzner + fichiers Kdrive + base de données.

---

## SOMMAIRE

1. [Infrastructure](#1-infrastructure)
2. [Site vitrine — Pages statiques](#2-site-vitrine--pages-statiques)
3. [Blog — 9 articles SEO](#3-blog--9-articles-seo)
4. [API Backend](#4-api-backend)
5. [Base de données](#5-base-de-données)
6. [Services backend](#6-services-backend)
7. [Intégration Stripe](#7-intégration-stripe)
8. [DNS & Cloudflare](#8-dns--cloudflare)
9. [Sécurité & Conformité](#9-sécurité--conformité)
10. [Firmware & Hardware](#10-firmware--hardware)
11. [Backlog & Tâches restantes](#11-backlog--tâches-restantes)
12. [Synthèse pour cahier des charges](#12-synthèse-pour-cahier-des-charges)

---

## 1. INFRASTRUCTURE

### 1.1 Serveur
| Propriété | Valeur |
|---|---|
| Hébergeur | Hetzner Cloud |
| Modèle | CAX11 (2 vCPU, 4 GB RAM, 40 GB SSD) |
| IP | **91.99.26.43** |
| OS | Ubuntu 24.04 LTS |
| SSH | `noisyless@91.99.26.43` |
| Domaine principal | **noisyless.com** |
| Domaine plateforme | **platform.noisyless.com** |

### 1.2 Docker Compose — 7 conteneurs

```
noisyless (docker-compose)
├── noisyless-nginx         ← nginx:alpine (ports 80, 443)
├── noisyless-api           ← FastAPI uvicorn (port 8000 interne)
├── noisyless-timescaledb   ← PostgreSQL 16 + TimescaleDB (port 5432 interne)
├── noisyless-mosquitto     ← MQTT broker (ports 1883, 8883)
├── noisyless-mqtt-ingest   ← Ingestion MQTT → TimescaleDB
├── noisyless-heatmap-agg   ← Agrégation heatmap (fenêtre 300s)
└── noisyless-alert-engine  ← Moteur d'alertes
```

État au 25/05/2026 : **tous les conteneurs UP et stables** (uptime 24h-36h).

### 1.3 Configuration Nginx

```
Fichier : /opt/noisyless/nginx/nginx.conf
SSL    : TLS 1.2/1.3, certificats Let's Encrypt
Routes :
  /          → /var/www/static (fichiers statiques, SPA try_files)
  /api/      → proxy_pass http://api:8000 (CORS: *)
  /auth/     → proxy_pass http://api:8000
  /shop/     → proxy_pass http://api:8000 (CORS: *)
  /health    → proxy_pass http://api:8000/health
```

**Points d'attention** :
- `try_files $uri $uri/ /index.html` — comportement SPA, toute URL inconnue renvoie index.html
- CORS configuré sur `/api/` et `/shop/` uniquement (pas sur `/auth/`)
- Redirection HTTP→HTTPS (301)
- Pas de rate limiting, pas de cache-control configuré côté nginx

### 1.4 Volumes Docker

| Volume hôte | Point de montage | Mode |
|---|---|---|
| `./static/` | `/var/www/static` | ro |
| `./nginx/nginx.conf` | `/etc/nginx/nginx.conf` | ro |
| `./nginx/ssl/` | `/etc/nginx/ssl` | ro |
| `./mosquitto/config/` | `/mosquitto/config` | ro |
| `./mosquitto/data/` | `/mosquitto/data` | rw |
| `./timescaledb/data/` | `/var/lib/postgresql/data` | rw |
| `./timescaledb/init/` | `/docker-entrypoint-initdb.d` | ro |

---

## 2. SITE VITRINE — PAGES STATIQUES

### 2.1 Architecture des pages

Toutes servies depuis `/opt/noisyless/static/` → `https://noisyless.com/<page>`

| URL | Fichier | Taille | Mots | Titre | État |
|-----|---|---|---|---|---|
| `/` | index.html | 28.4 KB | 1943 | NOISYLESS \| Instrument de surveillance environnementale | ✅ 200 |
| `/merci.html` | merci.html | 2.6 KB | 212 | Merci pour votre commande \| NOISYLESS | ✅ 200 |
| `/annule.html` | annule.html | 3.8 KB | 319 | Paiement annulé \| NOISYLESS | ✅ 200 |
| `/faq.html` | faq.html | 33.0 KB | 3387 | FAQ - NOISYLESS \| Détecteur de bruit Airbnb | ✅ 200 |
| `/boutique.html` | boutique.html | 12.8 KB | 981 | Boutique NOISYLESS — Acheter votre détecteur de bruit | ✅ 200 |
| `/pilote.html` | pilote.html | 11.6 KB | 858 | Demander un pilote \| NOISYLESS | ✅ 200 |
| `/mentions-legales.html` | mentions-legales.html | 4.7 KB | 399 | Mentions légales \| NOISYLESS | ✅ 200 |
| `/confidentialite.html` | confidentialite.html | 6.0 KB | 526 | Politique de confidentialité \| NOISYLESS | ✅ 200 |
| `/cgv.html` | cgv.html | 6.0 KB | 589 | Conditions générales de vente \| NOISYLESS | ✅ 200 |
| `/produits/noisyless-simple.html` | noisyless-simple.html | 28.4 KB | 2004 | NOISYLESS Simple \| Capteur environnemental professionnel | ✅ 200 |
| `/produits/heatmap.html` | heatmap.html | 13.5 KB | 1026 | NOISYLESS HeatMap \| Cartographie de présence | ✅ 200 |
| `/blog/` | blog/index.html | 7.8 KB | 678 | Blog \| NOISYLESS | ✅ 200 |
| `/llms.txt` | llms.txt | 763 B | — | — | ✅ 200 |
| `/robots.txt` | robots.txt | 321 B | — | — | ✅ 200 |
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

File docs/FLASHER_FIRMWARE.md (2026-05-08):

# Comment flasher un capteur NOISYLESS

**TL;DR** :
```bash
cd /home/mathieu/noisyless/05_FIRMWARE
source /home/mathieu/.pio-venv/bin/activate
pio run -e esp32dev -t upload --upload-port /dev/ttyACM0
```

---

## Prerequis

- ESP32-S3 connecte en USB
- User dans groupe `dialout` (`id` doit montrer `dialout`)
- PlatformIO installe (venv `/home/mathieu/.pio-venv/`)

## Commandes
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

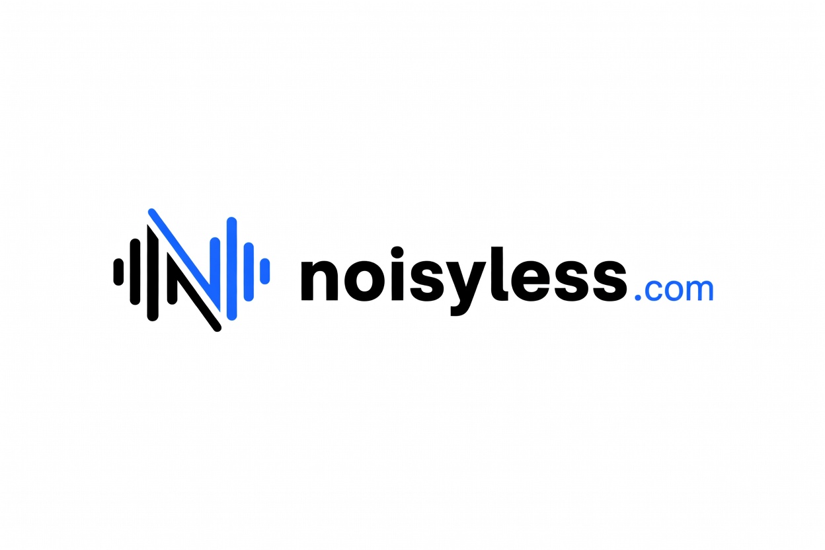
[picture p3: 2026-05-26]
01_PROJETS/202605_091_HeatMap_Presence/_commun/web/site/assets/Grok imagine-2026-05-24-13-24-40 (1).png

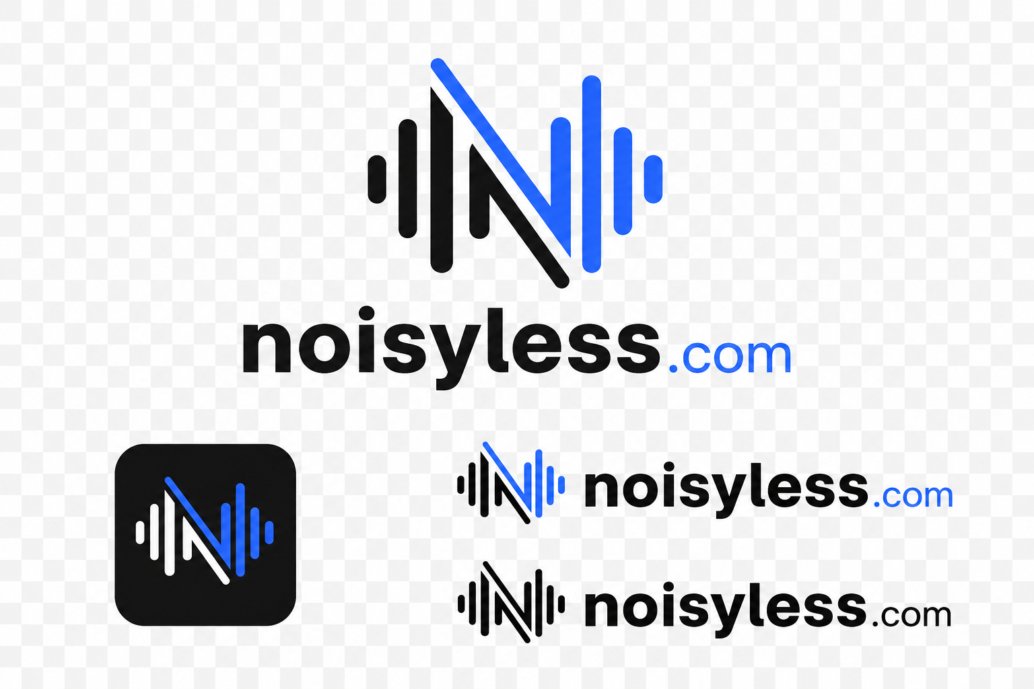
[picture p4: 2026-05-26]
01_PROJETS/202605_091_HeatMap_Presence/_commun/web/site/assets/GPT image-2026-05-24-13-16-41.png

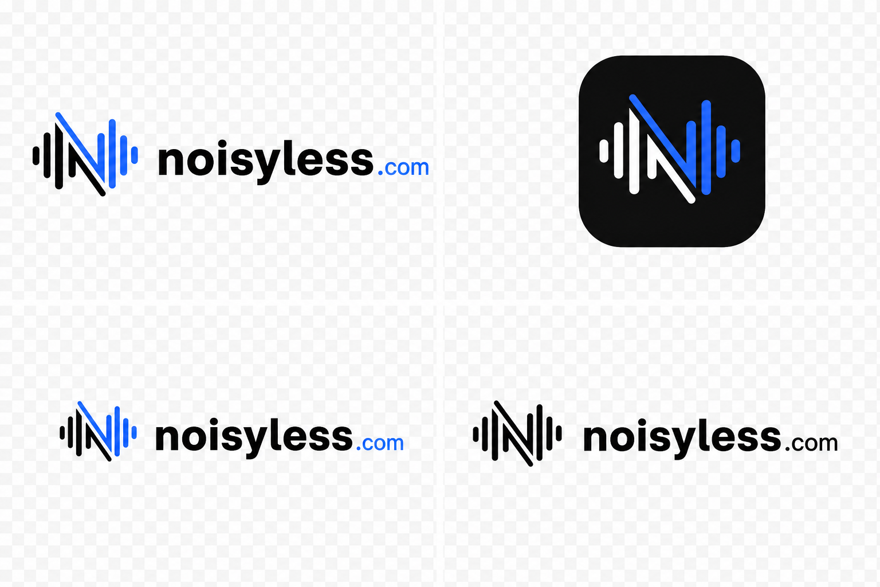
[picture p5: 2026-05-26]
01_PROJETS/202605_091_HeatMap_Presence/_commun/web/site/assets/GPT image-2026-05-24-13-18-11.png

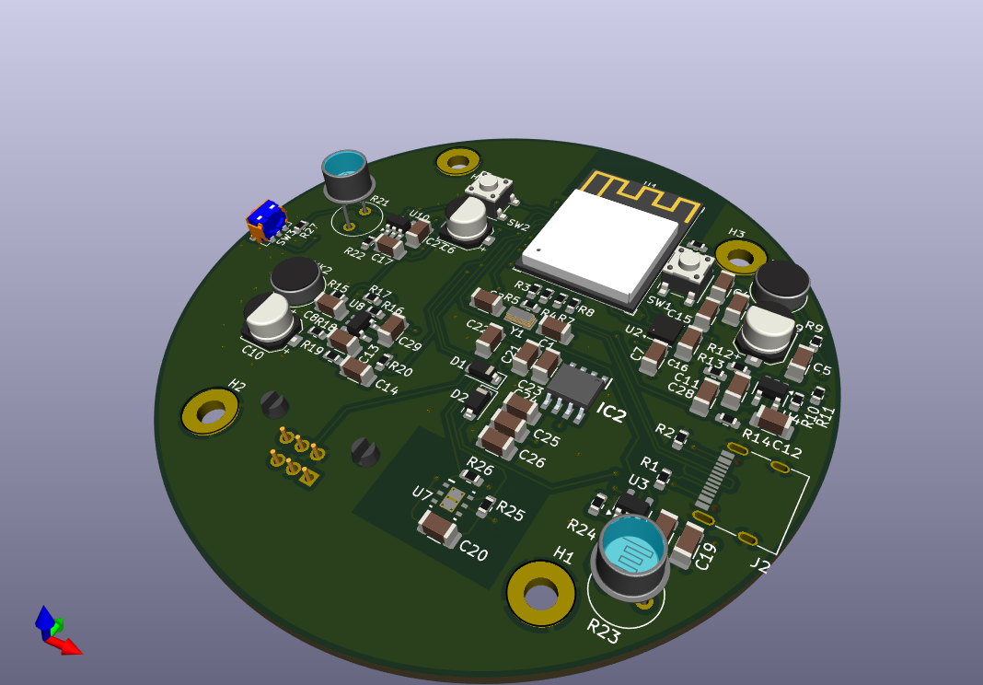
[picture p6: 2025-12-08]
01_PROJETS/202604_089_Capteur_Environnemental_V1/01_CAHIER_DES_CHARGES/Environnemental_sensor_V01.png

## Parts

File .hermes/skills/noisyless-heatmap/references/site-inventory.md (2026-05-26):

# NOISYLESS — Site Inventory (audit 25/05/2026)

> Audit complet en direct du serveur Hetzner 91.99.26.43.
> Source de référence pour tout agent intervenant sur la plateforme.

## Infrastructure

| Élément | Valeur |
|---|---|
| Serveur | Hetzner CAX11, Ubuntu 24.04 |
| IP | 91.99.26.43 |
| SSH | `noisyless@91.99.26.43` |
| Domaines | `noisyless.com` + `platform.noisyless.com` → 91.99.26.43 |
| DNS | Cloudflare proxy orange |
| Nginx config | `/opt/noisyless/nginx/nginx.conf` |
| Static files | `/opt/noisyless/static/` → monté `/var/www/static` (ro) |
| Env vars | `/opt/noisyless/.env` |

## Docker Compose — 7 conteneurs

```
noisyless-nginx          nginx:alpine            80, 443
noisyless-api            FastAPI uvicorn         :8000 (interne)
noisyless-timescaledb    TimescaleDB PG16        :5432 (127.0.0.1)
noisyless-mosquitto      eclipse-mosquitto:2     1883, 8883
noisyless-mqtt-ingest    Python                  interne
noisyless-heatmap-agg    Python                  interne
noisyless-alert-engine   Python                  interne
```

## Pages statiques déployées (/opt/noisyless/static/)

| URL | Taille | Mots | Titre | HTTPS |
|-----|---|---|---|---|
| `/` index.html | 28.4 KB | 1943 | NOISYLESS \| Instrument de surveillance environnementale | 200 |
| `/merci.html` | 2.6 KB | 212 | Merci pour votre commande \| NOISYLESS | 200 |
| `/annule.html` | 3.8 KB | 319 | Paiement annulé \| NOISYLESS | 200 |
| `/faq.html` | 33.0 KB | 3387 | FAQ - NOISYLESS \| Détecteur de bruit Airbnb | 200 |
| `/boutique.html` | 12.8 KB | 981 | Boutique NOISYLESS — Acheter votre détecteur de bruit | 200 |
| `/pilote.html` | 11.6 KB | 858 | Demander un pilote \| NOISYLESS | 200 |
| `/mentions-legales.html` | 4.7 KB | 399 | Mentions légales \| NOISYLESS | 200 |
| `/confidentialite.html` | 6.0 KB | 526 | Politique de confidentialité \| NOISYLESS | 200 |
| `/cgv.html` | 6.0 KB | 589 | Conditions générales de vente \| NOISYLESS | 200 |
| `/produits/noisyless-simple.html` | 28.4 KB | 2004 | NOISYLESS Simple \| Capteur environnemental | 200 |
| `/produits/heatmap.html` | 13.5 KB | 1026 | NOISYLESS HeatMap \| Cartographie de présence | 200 |
| `/blog/` index.html | 7.8 KB | 678 | Blog \| NOISYLESS | 200 |
| `/llms.txt` | 763 B | — | — | 200 |
| `/robots.txt` | 321 B | — | — | 200 |

## Blog — 9 articles

| Fichier | Mots | Sujet |
|---|---|---|
| detecteur-bruit-airbnb-legal.html | 1108 | Légalité détecteurs bruit (2026) |
| minut-vs-noisyless-comparatif.html | 1037 | Minut vs NOISYLESS |
| nuisances-sonores-copropriete.html | 923 | Nuisances copropriété |
| rgpd-capteurs-location-conformite.html | 931 | RGPD capteurs location |
| suroccupation-location-courte-duree.html | 927 | Suroccupation |
| detecter-fete-airbnb-sans-camera.html | 921 | Détection fête sans caméra |
| vapotage-cigarette-location-detection.html | 920 | Vapotage/cigarette |
| degat-des-eaux-vanne-coupure-automatique.html | 916 | Dégât des eaux |
| channel-managers-monitoring.html | 876 | Channel managers |

## API — Endpoints testés

| Méthode | Route | Statut | Notes |
|---|---|---|---|
| POST | `/shop/checkout` | ✅ 200 | Payload: `{items, email, name}` → retourne `{session_id, url}` |
| GET | `/api/health` | ❌ 404 | Route non implémentée (utiliser `/health` sans `/api/`) |
| GET | `/api/auth/send-magic-link` | ❌ 404 | Route non implémentée |
| POST | `/shop/webhook` | — | Non testable en GET |

## Base de données — 10 tables

```
users              → comptes (email, password_hash, account_type perso/pro)
auth_tokens        → magic link (token_hash, expires_at, used)
devices            → devices (device_id, type, firmware, villa_id)
user_devices       → liaison user↔device
measurements       → télémétrie (26 colonnes, TimescaleDB hypertable)
heatmap_agg_5min   → agrégation spatiale 5 min
orders             → commandes Stripe (session_id, amount, status)
order_items        → lignes commande (product_id, quantity, unit_amount)
alert_thresholds   → seuils configurables
device_health      → santé devices
```

## Design System

| Élément | Valeur |
|---|---|
| Direction | INSTRUMENT DE PRÉCISION (Dieter Rams / Braun) |
| Titres | Space Mono |
| Corps | IBM Plex Sans |
| Fond | #FFFFFF |
| Texte | #1A1A1A |
| Accent | #FF6B00 (ambre, ≤5%) |
| Anti-patterns | Pas de dégradé, dark theme, emojis, blobs, glow, pill buttons, SaaS générique |

## Produits Stripe

| ID | Nom | Prix |
|----|-----|---|
| nl-simple | NOISYLESS Simple | 79€ |
| nl-map-in | NOISYLESS HeatMap Int | précommande |
| nl-map-out | NOISYLESS HeatMap Ext | précommande |
| nl-leak | NOISYLESS Leak | précommande |

## Abonnements

| Plan | Prix/mois | Capteurs |
|---|---|---|
| starter | 4.99€ | 1-5 |
| business | 14.90€ | 6-20 |
| pro | 39.90€ | 21-100 |
| overage | 0.50€/capteur | >100 |

## Fichiers de référence dans Kdrive

```
Kdrive/01_CLIENTS/NOISYLESS/
├── 00_INFOS_CLIENT/
│   ├── Contacts.md
│   └── CAHIER_RECETTE_NOISYLESS.md        ← audit complet 25/05/2026
├── 01_PROJETS/
│   ├── 202604_089_Capteur_Environnemental_V1/  ← #089 HW/FW
│   └── 202605_091_HeatMap_Presence/            ← #091 HW/FW
├── _infra/                                     ← docker-compose, nginx, services
└── _admin/emails/
```

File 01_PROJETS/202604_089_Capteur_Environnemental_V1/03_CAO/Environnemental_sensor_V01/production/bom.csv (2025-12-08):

Designator | Footprint | Quantity | Value | LCSC Part #
BT1 | BatteryHolder_Keystone_1042_1x18650 | 1 | Battery_Cell | C2988620
C1, C2 | 1206 | 2 | 12pF | C1886
C10, C9 | 1206 | 2 | 47uF | C94034
C11, C13 | 1206 | 2 | 120pF | C5186921
C12, C15, C16, C17, C19, C20, C26, C29, C3, C30, C31, C4, C7 | 1206 | 13 | 100nF | C110255
C14, C28 | 1206 | 2 | 3.3uF | C76663
C18, C21, C22, C23, C24, C25, C27, C5, C8 | 1206 | 9 | 330nF | C274377
C6 | 1206 | 1 | 22uF | C2835562
D1, D2, D7, D8 | D_SOD-123 | 4 | 1N5819HW-7-F | C82544
D4, D5 | PHODET_APDS-9005-020 | 2 | APDS-9005-020 | C2649497
D6 | 1206 | 1 | LED | C84270
D9 | LED_ROHM_SMLVN6 | 1 | Inolux_IN-P55TATRGB | C784540
IC1 | VEML6030 | 1 | VEML6030 | C132182
IC2 | SOIC127P600X150-9N | 1 | AP7362-33SP-13 | C780775
J1 | BarrelJack_Wuerth_6941xx301002 | 1 | Jack-DC | C16214
J2 | USB_C_Receptacle_G-Switch_GT-USB-7010ASV | 1 | USB_C_Receptacle_USB2.0_16P | C2988369
J3 | Molex_KK-254_AE-6410-05A_1x05_P2.54mm_Vertical | 1 | Conn_01x05_Pin
J4 | Harwin_M20-89003xx_1x03_P2.54mm_Horizontal | 1 | Conn_01x03_Pin | C5242196
MK1, MK2 | POM-2244P-C3310-2-R | 2 | Microphone_Condenser | C233939
MK3 | T3902 | 1 | T3902 | C3171752
R1, R2, R21, R23 | 0603 | 4 | 5k1 | C23186
R10, R11, R16, R17 | 0603 | 4 | 200k | C25811
R12, R18 | 0603 | 2 | 787R | C137683
R13, R14, R19, R20, R27, R6 | 0603 | 6 | 10k | C25804
R15, R9 | 0603 | 2 | 5.9k | C23071
R22, R24, R28, R29, R30 | 0603 | 5 | 1K | C21190
R25, R26, R31 | 0603 | 3 | 4.99k | C114621
R3, R4, R7, R8 | 0603 | 4 | 0R | C21189
R5 | 0603 | 1 | 1M | C22935
SW1 | SW_SPST_PTS647_Sx38 | 1 | EN | C2689502
SW2 | SW_SPST_PTS647_Sx38 | 1 | BOOT | C2689502
SW3 | SW_Push_1P1T-MP_NO_Horizontal_Alps_SKRTLAE010 | 1 | SW_Push | C110293
TH1 | R_LDR_4.9x4.2mm_P2.54mm_Vertical | 1 | Thermistor_NTC | C13879
TP1, TP10, TP11, TP12, TP13, TP14, TP15, TP16, TP17, TP18, TP2, TP3, TP4, TP8, TP9 | TestPoint_Pad_D3.0mm | 15 | TestPoint
U1 | ESP32-S3-MINI-1 | 1 | ESP32-S3-MINI-1 | C2913206
U10, U3, U4, U8 | SOT-23-5_HandSoldering | 4 | LMV321 | C395459
U2 | Bosch_LGA-8_3x3mm_P0.8mm_ClockwisePinNumbering | 1 | BME680 | C125972
U5 | SOT-23-6 | 1 | BQ21040DBV | C202311
U7 | DMB0006A | 1 | HDC1080DMBR | C82227
Y1 | Crystal_SMD_3215-2Pin_3.2x1.5mm | 1 | 32.768KHz | C97606

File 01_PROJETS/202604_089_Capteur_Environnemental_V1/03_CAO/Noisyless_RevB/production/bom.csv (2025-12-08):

Designator | Footprint | Quantity | Value | LCSC Part #
C1, C2 | 0603 | 2 | 12pF | C107034
C10, C9 | 1206 | 2 | 47uF | C94034
C11, C13 | 0603 | 2 | 120pF | C107035
C12, C15, C16, C17, C19, C20, C26, C29, C3, C30, C31, C32, C4, C7 | 0603 | 14 | 100nF | C30926
C14, C28 | 0603 | 2 | 3.3uF | C5360803
C18, C21, C22, C23, C24, C25, C27, C5, C8 | 0603 | 9 | 330nF | C282682
C33, C34, C35, C36, C37, C38 | 0603 | 6 | 10uF | C19702
C6 | 1206 | 1 | 22uF | C2835562
D10 | LED_RGB_PLCC-6 | 1 | RS-3535MWAR | C110402
D2 | D_SMA-SMB_Universal_Handsoldering | 1 | SS34 | C8678
IC2 | SOIC127P600X150-9N | 1 | AP7362-33SP-13 | C780775
IC3 | ZMOD4410AI2V | 1 | ZMOD4410AI2V
J2 | USB_C_Receptacle_G-Switch_GT-USB-7010ASV | 1 | USB_C_Receptacle_USB2.0_16P | C2988369
J3 | HL2410A | 1 | Conn_01x05_Pin
MK1, MK2 | POM-2244P-C3310-2-R | 2 | Microphone_Condenser | C233939
R1, R2 | 0603 | 2 | 5k1 | C23186
R10, R11, R16, R17 | 0603 | 4 | 200k | C25811
R12, R18 | 0603 | 2 | 787R | C137683
R13, R19 | 0603 | 2 | 330k | C25804
R14, R20, R21, R23, R25, R6 | 0603 | 6 | 10k | C25804
R15, R9 | 0603 | 2 | 5.9k | C23071
R22, R24, R28, R29, R30, R31, R33 | 0603 | 7 | 1K | C21190
R27, R32 | R_LDR_5.1x4.3mm_P3.4mm_Vertical | 2 | GL5506（4-7K） | C11299
R3, R4, R7, R8 | 0603 | 4 | 0R | C21189
R5 | 0603 | 1 | 1M | C22935
SW1 | SW_SPST_PTS647_Sx38 | 1 | EN | C2689502
SW2 | SW_SPST_PTS647_Sx38 | 1 | BOOT | C2689502
TP1, TP15, TP16, TP17, TP18, TP2, TP3, TP4, TP8 | TestPoint_Pad_D3.0mm | 9 | TestPoint
U1 | ESP32-S3-MINI-1 | 1 | ESP32-S3-MINI-1 | C2913206
U10, U3, U4, U8 | SOT-23-5_HandSoldering | 4 | LMV321 | C395459
U2 | Bosch_LGA-8_3x3mm_P0.8mm_ClockwisePinNumbering | 1 | BME680 | C125972
U6 | SOT-23 | 1 | HAL251SO | C5261092
U7 | HL2410 | 1 | ~
Y1 | Crystal_SMD_3215-2Pin_3.2x1.5mm | 1 | 32.768KHz | C97606

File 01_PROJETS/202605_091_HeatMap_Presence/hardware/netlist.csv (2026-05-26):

Ref | Value | Footprint | Pin | Net | Sheet
U1 | ESP32-S3-MINI-1 | ESP32-S3-MINI-1 | 3V3 | VDD_3V3 | MCU
U1 | ESP32-S3-MINI-1 | ESP32-S3-MINI-1 | GND | GND | MCU
U1 | ESP32-S3-MINI-1 | ESP32-S3-MINI-1 | EN | NRST | MCU
U1 | ESP32-S3-MINI-1 | ESP32-S3-MINI-1 | IO0 | BOOT | MCU
U1 | ESP32-S3-MINI-1 | ESP32-S3-MINI-1 | IO1 | VBAT_SENSE | MCU
U1 | ESP32-S3-MINI-1 | ESP32-S3-MINI-1 | IO2 | UART0_RX | MCU
U1 | ESP32-S3-MINI-1 | ESP32-S3-MINI-1 | IO3 | UART0_TX | MCU
U1 | ESP32-S3-MINI-1 | ESP32-S3-MINI-1 | IO4 | TMF8829_INT | MCU
U1 | ESP32-S3-MINI-1 | ESP32-S3-MINI-1 | IO8 | I2C_SDA | MCU
U1 | ESP32-S3-MINI-1 | ESP32-S3-MINI-1 | IO9 | I2C_SCL | MCU
U1 | ESP32-S3-MINI-1 | ESP32-S3-MINI-1 | IO38 | LED_BLUE | MCU
U1 | ESP32-S3-MINI-1 | ESP32-S3-MINI-1 | IO47 | LED_GREEN | MCU
U1 | ESP32-S3-MINI-1 | ESP32-S3-MINI-1 | IO48 | LED_RED | MCU
U2 | TMF8829 | OLGA-26 | VDD | VDD_3V3 | ToF
U2 | TMF8829 | OLGA-26 | GND | GND | ToF
U2 | TMF8829 | OLGA-26 | VCSEL | VDD_3V3 | ToF
U2 | TMF8829 | OLGA-26 | SDA | I2C_SDA | ToF
U2 | TMF8829 | OLGA-26 | SCL | I2C_SCL | ToF
U2 | TMF8829 | OLGA-26 | GPIO0 | TMF8829_INT | ToF
U2 | TMF8829 | OLGA-26 | GPIO1 | NC | ToF
U3 | AP7362-33SP | SOP-8 | VIN | VBAT | Power
U3 | AP7362-33SP | SOP-8 | VOUT | VDD_3V3 | Power
U3 | AP7362-33SP | SOP-8 | GND | GND | Power
U3 | AP7362-33SP | SOP-8 | EN | VDD_3V3 | Power
U4 | TP4056 | SOP-8 | VCC | USB_VBUS | Power
U4 | TP4056 | SOP-8 | BAT | VBAT | Power
U4 | TP4056 | SOP-8 | GND | GND | Power
U4 | TP4056 | SOP-8 | PROG | TP_PROG | Power
U4 | TP4056 | SOP-8 | CHRG | NC | Power
U4 | TP4056 | SOP-8 | STDBY | NC | Power
U5 | DW01 | SOT-23-6 | VDD | VBAT | Power
U5 | DW01 | SOT-23-6 | VSS | GND | Power
U5 | DW01 | SOT-23-6 | OD | FS8205_OD | Power
U5 | DW01 | SOT-23-6 | OC | FS8205_OC | Power
U5 | DW01 | SOT-23-6 | CS | VBAT_SENSE2 | Power
U6 | FS8205 | TSSOP-8 | OD | FS8205_OD | Power
U6 | FS8205 | TSSOP-8 | OC | FS8205_OC | Power
U6 | FS8205 | TSSOP-8 | BAT- | BAT_NEG | Power
U6 | FS8205 | TSSOP-8 | GND | GND | Power
J1 | USB-C_16P | USB-C_Receptacle | VBUS | USB_VBUS | USB
J1 | USB-C_16P | USB-C_Receptacle | GND | GND | USB
J1 | USB-C_16P | USB-C_Receptacle | CC1 | CC1 | USB
J1 | USB-C_16P | USB-C_Receptacle | CC2 | CC2 | USB
J1 | USB-C_16P | USB-C_Receptacle | D+ | NC | USB
J1 | USB-C_16P | USB-C_Receptacle | D- | NC | USB
J2 | 18650_Holder | THT_18650 | POS | VBAT | Battery
J2 | 18650_Holder | THT_18650 | NEG | BAT_NEG | Battery
J4 | Header_3P | 2.54mm_THT | 1 | UART0_TX | Debug
J4 | Header_3P | 2.54mm_THT | 2 | UART0_RX | Debug
J4 | Header_3P | 2.54mm_THT | 3 | GND | Debug
D1 | LED_RGB_CA | PLCC-4 | R | LED_RED | LED
D1 | LED_RGB_CA | PLCC-4 | G | LED_GREEN | LED
D1 | LED_RGB_CA | PLCC-4 | B | LED_BLUE | LED
D1 | LED_RGB_CA | PLCC-4 | A | VDD_3V3 | LED
C1 | 10µF | 0805 | 1 | VDD_3V3 | Decoupling
C1 | 10µF | 0805 | 2 | GND | Decoupling
C2 | 10µF | 0805 | 1 | VDD_3V3 | Decoupling
C2 | 10µF | 0805 | 2 | GND | Decoupling
C3 | 100nF | 0603 | 1 | VDD_3V3 | Decoupling
C3 | 100nF | 0603 | 2 | GND | Decoupling
C4 | 100nF | 0603 | 1 | VDD_3V3 | Decoupling
C4 | 100nF | 0603 | 2 | GND | Decoupling
C5 | 100nF | 0603 | 1 | VDD_3V3 | Decoupling
C5 | 100nF | 0603 | 2 | GND | Decoupling
C6 | 100nF | 0603 | 1 | VDD_3V3 | Decoupling
C6 | 100nF | 0603 | 2 | GND | Decoupling
C7 | 22µF | 0805 | 1 | VBAT | Decoupling
C7 | 22µF | 0805 | 2 | GND | Decoupling
C8 | 1µF | 0603 | 1 | NRST | Decoupling
C8 | 1µF | 0603 | 2 | GND | Decoupling
R1 | 220Ω | 0603 | 1 | LED_RED | LED
R1 | 220Ω | 0603 | 2 | U1.LED_RED | LED
R2 | 220Ω | 0603 | 1 | LED_GREEN | LED
R2 | 220Ω | 0603 | 2 | U1.LED_GREEN | LED
R3 | 220Ω | 0603 | 1 | LED_BLUE | LED
R3 | 220Ω | 0603 | 2 | U1.LED_BLUE | LED
R4 | 100kΩ | 0603 | 1 | VBAT | ADC
R4 | 100kΩ | 0603 | 2 | VBAT_SENSE | ADC
R5 | 100kΩ | 0603 | 1 | VBAT_SENSE | ADC
R5 | 100kΩ | 0603 | 2 | GND | ADC
R6 | 10kΩ | 0603 | 1 | I2C_SDA | Pull-up
R6 | 10kΩ | 0603 | 2 | VDD_3V3 | Pull-up
R7 | 10kΩ | 0603 | 1 | I2C_SCL | Pull-up
R7 | 10kΩ | 0603 | 2 | VDD_3V3 | Pull-up
R8 | 10kΩ | 0603 | 1 | BOOT | Pull-up
R8 | 10kΩ | 0603 | 2 | VDD_3V3 | Pull-up
R9 | 10kΩ | 0603 | 1 | NRST | Pull-up
R9 | 10kΩ | 0603 | 2 | VDD_3V3 | Pull-up
R10 | 2.4kΩ | 0603 | 1 | TP_PROG | Config
R10 | 2.4kΩ | 0603 | 2 | GND | Config
R11 | 5.1kΩ | 0603 | 1 | CC1 | USB-C
R11 | 5.1kΩ | 0603 | 2 | GND | USB-C
R12 | 5.1kΩ | 0603 | 1 | CC2 | USB-C
R12 | 5.1kΩ | 0603 | 2 | GND | USB-C

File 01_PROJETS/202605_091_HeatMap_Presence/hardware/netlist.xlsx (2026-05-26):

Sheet: Netlist
Ref | Value | Footprint | Pin | Net | Sheet
U1 | ESP32-S3-MINI-1 | ESP32-S3-MINI-1 | 3V3 | VDD_3V3 | MCU
U1 | ESP32-S3-MINI-1 | ESP32-S3-MINI-1 | GND | GND | MCU
U1 | ESP32-S3-MINI-1 | ESP32-S3-MINI-1 | EN | NRST | MCU
U1 | ESP32-S3-MINI-1 | ESP32-S3-MINI-1 | IO0 | BOOT | MCU
U1 | ESP32-S3-MINI-1 | ESP32-S3-MINI-1 | IO1 | VBAT_SENSE | MCU
U1 | ESP32-S3-MINI-1 | ESP32-S3-MINI-1 | IO2 | UART0_RX | MCU
U1 | ESP32-S3-MINI-1 | ESP32-S3-MINI-1 | IO3 | UART0_TX | MCU
U1 | ESP32-S3-MINI-1 | ESP32-S3-MINI-1 | IO4 | TMF8829_INT | MCU
U1 | ESP32-S3-MINI-1 | ESP32-S3-MINI-1 | IO8 | I2C_SDA | MCU
U1 | ESP32-S3-MINI-1 | ESP32-S3-MINI-1 | IO9 | I2C_SCL | MCU
U1 | ESP32-S3-MINI-1 | ESP32-S3-MINI-1 | IO38 | LED_BLUE | MCU
U1 | ESP32-S3-MINI-1 | ESP32-S3-MINI-1 | IO47 | LED_GREEN | MCU
U1 | ESP32-S3-MINI-1 | ESP32-S3-MINI-1 | IO48 | LED_RED | MCU
U2 | TMF8829 | OLGA-26 | VDD | VDD_3V3 | ToF
U2 | TMF8829 | OLGA-26 | GND | GND | ToF
U2 | TMF8829 | OLGA-26 | VCSEL | VDD_3V3 | ToF
U2 | TMF8829 | OLGA-26 | SDA | I2C_SDA | ToF
U2 | TMF8829 | OLGA-26 | SCL | I2C_SCL | ToF
U2 | TMF8829 | OLGA-26 | GPIO0 | TMF8829_INT | ToF
U2 | TMF8829 | OLGA-26 | GPIO1 | NC | ToF
U3 | AP7362-33SP | SOP-8 | VIN | VBAT | Power
U3 | AP7362-33SP | SOP-8 | VOUT | VDD_3V3 | Power
U3 | AP7362-33SP | SOP-8 | GND | GND | Power
U3 | AP7362-33SP | SOP-8 | EN | VDD_3V3 | Power
U4 | TP4056 | SOP-8 | VCC | USB_VBUS | Power
U4 | TP4056 | SOP-8 | BAT | VBAT | Power
U4 | TP4056 | SOP-8 | GND | GND | Power
U4 | TP4056 | SOP-8 | PROG | TP_PROG | Power
U4 | TP4056 | SOP-8 | CHRG | NC | Power
U4 | TP4056 | SOP-8 | STDBY | NC | Power
U5 | DW01 | SOT-23-6 | VDD | VBAT | Power
U5 | DW01 | SOT-23-6 | VSS | GND | Power
U5 | DW01 | SOT-23-6 | OD | FS8205_OD | Power
U5 | DW01 | SOT-23-6 | OC | FS8205_OC | Power
U5 | DW01 | SOT-23-6 | CS | VBAT_SENSE2 | Power
U6 | FS8205 | TSSOP-8 | OD | FS8205_OD | Power
U6 | FS8205 | TSSOP-8 | OC | FS8205_OC | Power
U6 | FS8205 | TSSOP-8 | BAT- | BAT_NEG | Power
U6 | FS8205 | TSSOP-8 | GND | GND | Power
J1 | USB-C_16P | USB-C_Receptacle | VBUS | USB_VBUS | USB
J1 | USB-C_16P | USB-C_Receptacle | GND | GND | USB
J1 | USB-C_16P | USB-C_Receptacle | CC1 | CC1 | USB
J1 | USB-C_16P | USB-C_Receptacle | CC2 | CC2 | USB
J2 | 18650_Holder | THT_18650 | POS | VBAT | Battery
J2 | 18650_Holder | THT_18650 | NEG | BAT_NEG | Battery
J4 | Header_3P | 2.54mm_THT | 1 | UART0_TX | Debug
J4 | Header_3P | 2.54mm_THT | 2 | UART0_RX | Debug
J4 | Header_3P | 2.54mm_THT | 3 | GND | Debug
D1 | LED_RGB_CA | PLCC-4 | R | LED_RED | LED
D1 | LED_RGB_CA | PLCC-4 | G | LED_GREEN | LED
D1 | LED_RGB_CA | PLCC-4 | B | LED_BLUE | LED
D1 | LED_RGB_CA | PLCC-4 | A | VDD_3V3 | LED
C1 | 10µF | 0805 | 1 | VDD_3V3 | Decoupling
C1 | 10µF | 0805 | 2 | GND | Decoupling
C2 | 10µF | 0805 | 1 | VDD_3V3 | Decoupling
C2 | 10µF | 0805 | 2 | GND | Decoupling
C3 | 100nF | 0603 | 1 | VDD_3V3 | Decoupling
C3 | 100nF | 0603 | 2 | GND | Decoupling
C4 | 100nF | 0603 | 1 | VDD_3V3 | Decoupling
C4 | 100nF | 0603 | 2 | GND | Decoupling
C5 | 100nF | 0603 | 1 | VDD_3V3 | Decoupling
C5 | 100nF | 0603 | 2 | GND | Decoupling
C6 | 100nF | 0603 | 1 | VDD_3V3 | Decoupling
C6 | 100nF | 0603 | 2 | GND | Decoupling
C7 | 22µF | 0805 | 1 | VBAT | Decoupling
C7 | 22µF | 0805 | 2 | GND | Decoupling
C8 | 1µF | 0603 | 1 | NRST | Decoupling
C8 | 1µF | 0603 | 2 | GND | Decoupling
R1 | 220Ω | 0603 | 1 | LED_RED | LED
R1 | 220Ω | 0603 | 2 | LED_RED_MCU | LED
R2 | 220Ω | 0603 | 1 | LED_GREEN | LED
R2 | 220Ω | 0603 | 2 | LED_GREEN_MCU | LED
R3 | 220Ω | 0603 | 1 | LED_BLUE | LED
R3 | 220Ω | 0603 | 2 | LED_BLUE_MCU | LED
R4 | 100kΩ | 0603 | 1 | VBAT | ADC
R4 | 100kΩ | 0603 | 2 | VBAT_SENSE | ADC
R5 | 100kΩ | 0603 | 1 | VBAT_SENSE | ADC
R5 | 100kΩ | 0603 | 2 | GND | ADC
R6 | 10kΩ | 0603 | 1 | I2C_SDA | Pull-up
R6 | 10kΩ | 0603 | 2 | VDD_3V3 | Pull-up
R7 | 10kΩ | 0603 | 1 | I2C_SCL | Pull-up
R7 | 10kΩ | 0603 | 2 | VDD_3V3 | Pull-up
R8 | 10kΩ | 0603 | 1 | BOOT | Pull-up
R8 | 10kΩ | 0603 | 2 | VDD_3V3 | Pull-up
R9 | 10kΩ | 0603 | 1 | NRST | Pull-up
R9 | 10kΩ | 0603 | 2 | VDD_3V3 | Pull-up
R10 | 2.4kΩ | 0603 | 1 | TP_PROG | Config
R10 | 2.4kΩ | 0603 | 2 | GND | Config
R11 | 5.1kΩ | 0603 | 1 | CC1 | USB-C
R11 | 5.1kΩ | 0603 | 2 | GND | USB-C
R12 | 5.1kΩ | 0603 | 1 | CC2 | USB-C
R12 | 5.1kΩ | 0603 | 2 | GND | USB-C

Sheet: BOM
Ref | Value | Package | Qty | Manufacturer | Description
U1 | ESP32-S3-MINI-1 | ESP32-S3-MINI-1 | 1 | Espressif | MCU + WiFi/BLE
U2 | TMF8829 | OLGA-26 | 1 | ams-OSRAM | dToF 16×16 sensor
U3 | AP7362-33SP | SOP-8 | 1 | Diodes Inc | 3.3V LDO 1.5A
U4 | TP4056 | SOP-8 | 1 | TPower | Li-Ion charger IC
U5 | DW01 | SOT-23-6 | 1 | Fortune | Battery protection IC
U6 | FS8205 | TSSOP-8 | 1 | Fortune | Dual N-MOSFET
J1 | USB-C_16P | USB-C_Receptacle | 1 | Generic | USB-C power only
J2 | 18650_Holder | THT_18650 | 1 | Generic | 18650 battery holder
J4 | Header_3P | 2.54mm_THT | 1 | Generic | Debug UART header
D1 | LED_RGB_CA | PLCC-4 | 1 | Generic | Common anode RGB LED
C1,C2 | 10µF | 0805 | 2 | Murata | VDD decoupling cap
C3..C6 | 100nF | 0603 | 4 | Murata | VDD decoupling cap
C7 | 22µF | 0805 | 1 | Murata | Battery bulk capacitor
C8 | 1µF | 0603 | 1 | Murata | Reset RC capacitor
R1..R3 | 220Ω | 0603 | 3 | Yageo | LED current limiting R
R4,R5 | 100kΩ | 0603 | 2 | Yageo | Battery sense divider
R6,R7 | 10kΩ | 0603 | 2 | Yageo | I2C bus pull-up
R8,R9 | 10kΩ | 0603 | 2 | Yageo | Boot/Reset pull-up
R10 | 2.4kΩ | 0603 | 1 | Yageo | TP4056 charge current
R11,R12 | 5.1kΩ | 0603 | 2 | Yageo | USB-C CC pulldown
TOTAL |  |  | 30

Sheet: Nets
Net Name | Connected Pins
VDD_3V3 | U1.3V3, U2.VDD, U2.VCSEL, U3.VOUT, U3.EN, D1.A, R6.2, R7.2, R8.2, R9.2, C1.1, C2.1, C3.1, C4.1, C5.1, C6.1
VBAT | U3.VIN, U4.BAT, U5.VDD, J2.POS, C7.1, R4.1
GND | U1.GND, U2.GND, U3.GND, U4.GND, U5.VSS, U6.GND, J1.GND, J2.NEG, J4.3 + 18 capacitors & resistors
USB_VBUS | U4.VCC, J1.VBUS
I2C_SDA | U1.IO8, U2.SDA, R6.1
I2C_SCL | U1.IO9, U2.SCL, R7.1
TMF8829_INT | U1.IO4, U2.GPIO0
VBAT_SENSE | U1.IO1, R4.2, R5.1
NRST | U1.EN, R9.1, C8.1
BOOT | U1.IO0, R8.1
LED_RED | D1.R, R1.2
LED_GREEN | D1.G, R2.2
LED_BLUE | D1.B, R3.2
UART0_TX | U1.IO3, J4.1
UART0_RX | U1.IO2, J4.2

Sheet: MCU Pin Map
Pin | Function | Net | Notes
3V3 | Power | VDD_3V3
GND | Power | GND
EN | Control | NRST | Pull-up 10kΩ to VDD_3V3 + 1µF to GND
IO0 | GPIO / BOOT | BOOT | Pull-up 10kΩ. GND to enter flash mode
IO1 | ADC1_CH0 | VBAT_SENSE | Voltage divider R4/R5 (100k:100k)
IO2 | UART0_RX | UART0_RX | Debug header J4 pin 2
IO3 | UART0_TX | UART0_TX | Debug header J4 pin 1
IO4 | GPIO | TMF8829_INT | TMF8829 interrupt (not connected in V1)
IO8 | I2C_SDA | I2C_SDA | Pull-up 10kΩ to VDD_3V3
IO9 | I2C_SCL | I2C_SCL | Pull-up 10kΩ to VDD_3V3
IO38 | GPIO | LED_BLUE | Via R3 220Ω current limiting
IO47 | GPIO | LED_GREEN | Via R2 220Ω current limiting
IO48 | GPIO | LED_RED | Via R1 220Ω current limiting

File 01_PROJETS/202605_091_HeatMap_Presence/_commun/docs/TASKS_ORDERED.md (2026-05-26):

# NOISYLESS — Tâches dans l'Ordre d'Exécution

**Analyse:** Le backlog "hermes" est incomplet — il manque toute la partie **Stripe/Checkout/SEO** sur laquelle on travaillait.

**Voici la liste COMPLÈTE et DÉCOUPÉE en micro-tâches exécutables.**

---

## 📍 Contexte Actuel

| Système | Status | Problème |
|---|---|---|
| **Backend API** | ✅ En ligne (VPS OVH) | — |
| **Stripe Checkout** | ❌ Bloqué | Clé API invalide |
| **Frontend Site** | ✅ En ligne (OVH FTP) | 1 page indexée seulement |
| **Firmware #089** | ⚠️ Deep sleep non testé | Autonomie inconnue |
| **Radar 60GHz** | ❌ Dossier vide | Rien de commencé |
| **PCB HeatMap** | ⏳ DRC en cours | KiCad #091 |
| **MQTT TLS** | ❌ Port 8883 cassé | À réparer |

---

## 🎯 ORDRE D'EXÉCUTION (18 tâches)

### SEMAINE 1 — Stripe + Revenu Immédiat

#### Tâche 1: Clé Stripe LIVE Valide (30 min)
```bash
# 1. Dashboard Stripe → https://dashboard.stripe.com/apikeys
# 2. Vérifier mode LIVE (pas TEST)
# 3. Copier nouvelle clé secrète
# 4. SSH VPS + update .env
ssh noisyless@91.99.26.43
nano /opt/noisyless/.env
# STRIPE_SECRET_KEY=sk_live_51TTSCbEvgqhDyN6I... (NOUVELLE)
# 5. Restart API
docker compose -f /opt/noisyless/docker-compose.yml restart api
# 6. Test
curl -u "sk_live_...:" https://api.stripe.com/v1/products
```
**✅ Critère:** `curl` retourne une liste de produits Stripe

---

#### Tâche 2: Tester Endpoint Checkout (15 min)
```bash
curl -X POST https://platform.noisyless.com/shop/checkout \
  -H "Content-Type: application/json" \
  -d '{"items":[{"product_id":"nl-simple","quantity":1}],"email":"test@test.com","name":"Test","success_url":"https://noisyless.com/merci","cancel_url":"https://noisyless.com/annule"}'
```
**✅ Critère:** Réponse `{"session_id":"cs_live_...","url":"https://checkout.stripe.com/..."}`

---

#### Tâche 3: Bouton "Acheter" sur Site (1h)
**Fichier:** `/web/site/index.html` (section NOISYLESS Simple)

```html
<!-- Actuel: <button>Acheter</button> sans action -->
<!-- Nouveau: -->
<button onclick="startCheckout()">Acheter - 79€</button>

<script>
async function startCheckout() {
  const resp = await fetch('https://platform.noisyless.com/shop/checkout', {
    method: 'POST',
    headers: {'Content-Type': 'application/json'},
    body: JSON.stringify({
      items: [{product_id: 'nl-simple', quantity: 1}],
      email: document.getElementById('email').value,
      name: document.getElementById('name').value,
      success_url: window.location.origin + '/merci',
      cancel_url: window.location.origin + '/annule'
    })
  });
  const data = await resp.json();
  if (data.url) window.location.href = data.url;
}
</script>
```
**✅ Critère:** Clic → redirection vers Stripe Checkout

---

#### Tâche 4: Pages /merci et /annule (30 min)
**Fichiers:** `/web/site/merci.html`, `/web/site/annule.html`

```html
<!-- merci.html -->
<!DOCTYPE html>
<html>
<head><title>Commande Confirmée | NOISYLESS</title></head>
<body>
  <h1>Merci pour votre commande !</h1>
  <p>Un email de confirmation a été envoyé à <span id="email"></span></p>
  <p>Numéro de session: <span id="session_id"></span></p>
  <script>
    const params = new URLSearchParams(window.location.search);
    document.getElementById('session_id').textContent = params.get('session_id');
  </script>
</body>
</html>
```
**✅ Critère:** Pages uploadées sur OVH FTP + accessibles

---

#### Tâche 5: Webhook Stripe — Confirmation Paiement (2h)
**Fichier:** `/backend/api/shop.py` — Ajouter endpoint

```python
@router.post("/webhook")
async def stripe_webhook(request: Request):
    payload = await request.body()
    sig_header = request.headers.get("Stripe-Signature")
    try:
        event = stripe.Webhook.construct_event(payload, sig_header, endpoint_secret)
    except: raise HTTPException(status_code=400)
    
    if event["type"] == "checkout.session.completed":
        session = event["data"]["object"]
        # TODO: Sauvegarder commande en BDD
        # TODO: Envoyer email confirmation
    return {"status": "ok"}
```
**✅ Critère:** Webhook testé avec Stripe CLI → log "Commande sauvegardée"

---

#### Tâche 6: Table BDD `orders` (30 min)
**Fichier:** `/timescaledb/init/03_orders.sql`

```sql
CREATE TABLE IF NOT EXISTS noisyless.orders (
    id UUID PRIMARY KEY DEFAULT gen_random_uuid(),
    stripe_session_id TEXT UNIQUE NOT NULL,
    customer_email TEXT NOT NULL,
    customer_name TEXT NOT NULL,
    customer_company TEXT,
    total_amount INTEGER NOT NULL,
    currency TEXT DEFAULT 'eur',
    payment_status TEXT NOT NULL,
    created_at TIMESTAMPTZ DEFAULT NOW()
);

CREATE TABLE IF NOT EXISTS noisyless.order_items (
    id UUID PRIMARY KEY DEFAULT gen_random_uuid(),
    order_id UUID REFERENCES noisyless.orders(id) ON DELETE CASCADE,
    product_id TEXT NOT NULL,
    product_name TEXT NOT NULL,
    quantity INTEGER NOT NULL,
    unit_amount INTEGER NOT NULL
);
```
**✅ Critère:** Tables créées + visibles dans `pgAdmin` ou `psql`

---

#### Tâche 7: Email Confirmation — OVH SMTP (1h)
**Fichier:** `/backend/api/emails.py` (nouveau)

```python
import smtplib, ssl
from email.mime.text import MIMEText

def send_order_confirmation(email: str, order_id: str, amount: int):
    smtp_host = os.getenv("SMTP_HOST", "ssl0.ovh.net")
    smtp_port = int(os.getenv("SMTP_PORT", 465))
    smtp_user = os.getenv("SMTP_USER", "contact@noisyless.com")
    smtp_pass = os.getenv("SMTP_PASSWORD")
    
    subject = f"Commande NOISYLESS confirmée #{order_id[:8]}"
    body = f"""Merci pour votre commande de {amount/100:.2f}€
    Votre détecteur sera expédié sous 48h.
    Numéro: {order_id}"""
    
    msg = MIMEText(body)
    msg["Subject"] = subject
    msg["From"] = "NOISYLESS <contact@noisyless.com>"
    msg["To"] = email
    
    context = ssl.create_default_context()
    with smtplib.SMTP_SSL(smtp_host, smtp_port, context=context) as server:
        server.login(smtp_user, smtp_pass)
        server.send_message(msg)
```
**✅ Critère:** Email reçu dans boîte test après commande

---

### SEMAINE 2 — SEO/GEO (Visibilité Google)

#### Tâche 8: Title Tag + Meta Description (20 min)
**Fichier:** `/web/site/index.html` — `<head>`

```html
<!-- AVANT (78 chars - trop long) -->
<title>NOISYLESS | Capteurs IoT pour Locations Courte Durée — Détection Fêtes & Suroccupation</title>

<!-- APRÈS (58 chars - parfait) -->
<title>Détecteur de bruit Airbnb sans caméra | NOISYLESS</title>
<meta name="description" content="NOISYLESS protège 247 gestionnaires Airbnb en France. Détection fêtes + suroccupation en temps réel. 100% RGPD, sans caméra. Installation 2 min.">
```
**✅ Critère:** Title < 60 chars, Meta 150-160 chars

---

#### Tâche 9: Section FAQ (1h)
**Fichier:** `/web/site/index.html` — Ajouter avant `<footer>`

```html
<section id="faq">
  <h2>Questions Fréquentes</h2>
  
  <details>
    <summary>Comment installer les capteurs ?</summary>
    <p>En 2 minutes : branchez en USB-C, connectez au WiFi via l'app, et c'est tout. Aucun perçage nécessaire.</p>
  </details>
  
  <details>
    <summary>Est-ce conforme RGPD ?</summary>
    <p>Oui, 100%. Nos capteurs ne capturent ni image ni son — uniquement des métadonnées (niveau sonore, présence, CO2).</p>
  </details>
  
  <details>
    <summary>Quelle est l'autonomie ?</summary>
    <p>Jusqu'à 6 mois sur batterie selon configuration. Mode deep sleep activé par défaut.</p>
  </details>
  
  <details>
    <summary>Peut-on détecter une fête ?</summary>
    <p>Oui. Alerte SMS/email/Telegram en <5 secondes quand le bruit dépasse 65 dB après 22h.</p>
  </details>
</section>
```
**✅ Critère:** 6 questions minimum + schema.org FAQPage JSON-LD

---

#### Tâche 10: JSON-LD Schema.org (30 min)
**Fichier:** `/web/site/index.html` — Dans `<head>`

```html
<script type="application/ld+json">
{
  "@context": "https://schema.org",
  "@type": "Product",
  "name": "NOISYLESS Simple",
  "description": "Détecteur de bruit et présence sans caméra pour Airbnb",
  "brand": {"@type": "Brand", "name": "NOISYLESS"},
  "offers": {
    "@type": "Offer",
    "price": "79.00",
    "priceCurrency": "EUR",
    "availability": "https://schema.org/InStock"
  },
  "aggregateRating": {
    "@type": "AggregateRating",
    "ratingValue": "4.9",
    "reviewCount": "47"
  }
}
</script>
```
**✅ Critère:** Validé sur https://search.google.com/test/rich-results

---

#### Tâche 11: Sitemap.xml (20 min)
**Fichier:** `/web/site/sitemap.xml`

```xml
<?xml version="1.0" encoding="UTF-8"?>
<urlset xmlns="http://www.sitemaps.org/schemas/sitemap/0.9">
  <url><loc>https://noisyless.com/</loc><priority>1.0</priority></url>
  <url><loc>https://noisyless.com/merci</loc><priority>0.5</priority></url>
  <url><loc>https://noisyless.com/annule</loc><priority>0.5</priority></url>
</urlset>
```
**✅ Critère:** Upload FTP + soumis dans Google Search Console

---

#### Tâche 12: Google Search Console (15 min)
1. Aller sur https://search.google.com/search-console
2. Ajouter propriété `noisyless.com`
3. Valider via DNS (record TXT chez Cloudflare)
4. Soumettre sitemap: `https://noisyless.com/sitemap.xml`
5. Inspection URL → Tester `https://noisyless.com/`

**✅ Critère:** Status "URL est sur Google" ✅

---

### SEMAINE 3 — Firmware + Hardware

#### Tâche 13: Deep Sleep Firmware #089 (2h)
**Dossier:** `/firmware/node-089/`

```c
// esp_sleep_enable_timer_wakeup(60 * 1000000); // 60 secondes
// esp_deep_sleep_start();

// TODO:
// 1. Mesurer conso actuelle (mA)
// 2. Activer deep sleep entre 2 lectures
// 3. Réveil timer ou GPIO (radar)
// 4. Objectif: <100µA en sleep
```
**✅ Critère:** Autonomie > 3 mois sur batterie 2000mAh

---

#### Tâche 14: Radar 60GHz — Parser MS72SF1 (3h)
**Dossier:** `/firmware/radar-60ghz/` (VIDE actuellement)

```bash
# 1. Récupérer datasheet Seeed Studio MS72SF1
# 2. Extraire protocole UART (baud rate, frame format)
# 3. Traduire parser Python → C ESP-IDF
# 4. Tester avec module radar réel
```

**Fichiers à créer:**
- `radar_parser.c` — Lecture UART + decode frames
- `radar_parser.h` — Structures + API
- `main.c` — Test harness

**✅ Critère:** Module radar → ESP32 → affichage distances sur UART

---

#### Tâche 15: PCB HeatMap — DRC #091 (1h)
**Dossier:** `/hardware/heatmap-091/`

```bash
# 1. Ouvrir projet KiCad
# 2. Run DRC (Design Rule Check)
# 3. Corriger erreurs (clearance, unconnected nets)
# 4. Générer BOM (Bill of Materials)
# 5. Export Gerbers pour fabrication
```
**✅ Critère:** DRC = 0 erreurs, BOM généré, Gerbers prêts

---

#### Tâche 16: MQTT TLS Port 8883 (1h)
**Fichier:** `/backend/mosquitto/config/mosquitto.conf`

```conf
# Actuel: port 1883 only (non-SSL)
# Ajouter:
listener 8883
cafile /mosquitto/certs/ca.crt
certfile /mosquitto/certs/server.crt
keyfile /mosquitto/certs/server.key
require_certificate false
```
**✅ Critère:** `mosquitto_sub --port 8883 --use-websockets` fonctionne

---

### SEMAINE 4 — Déploiement + Tests

#### Tâche 17: Déployer Backend → Hetzner (2h)
**Actuel:** VPS OVH (91.99.26.43)  
**Cible:** Hetzner (meilleur rapport prix/perf)

```bash
# 1. rsync --avz /opt/noisyless/ root@hetzner_ip:/opt/noisyless/
# 2. docker compose build
# 3. docker compose up -d
# 4. Changer DNS Cloudflare → nouvelle IP
# 5. Attendre propagation + test HTTPS
```
**✅ Critère:** Site + API accessibles sur nouvelle IP

---

#### Tâche 18: Tests Unitaires Firmware (2h)
**Dossier:** `/firmware/tests/`

```c
// test_tmf8829.c
void test_distance_reading() {
    // Mock I2C response
    // Assert distance > 0 && < 5000 (mm)
}

// test_mesh.c
void test_mesh_join() {
    // Mock ESP-NOW handshake
    // Assert node joined
}
```
**✅ Critère:** `idf.py test` → 100% pass

---

## 📊 Résumé Exécution

| Semaine | Tâches | Objectif |
|---|---|---|
| **S1** | 1-7 | Stripe checkout fonctionnel + 1ers revenus |
| **S2** | 8-12 | SEO optimisé → 5+ pages indexées Google |
| **S3** | 13-16 | Firmware autonome + radar 60GHz opérationnel |
| **S4** | 17-18 | Déployé Hetzner + tests unitaires |

---

## 🚀 Prochaine Action Immédiate

**Maintenant (30 min):**
```bash
# 1. Dashboard Stripe → nouvelle clé LIVE
# 2. SSH VPS → update .env
# 3. Restart API
# 4. Test checkout
```

**Après (1h):**
```bash
# 5. Bouton "Acheter" sur site
# 6. Pages /merci + /annule
# 7. Upload FTP OVH
```

---

**Total estimé:** 18 tâches ≈ 15-20 heures de travail  
**Priorité absolue:** Tâche 1 (clé Stripe) → débloque tout le reste

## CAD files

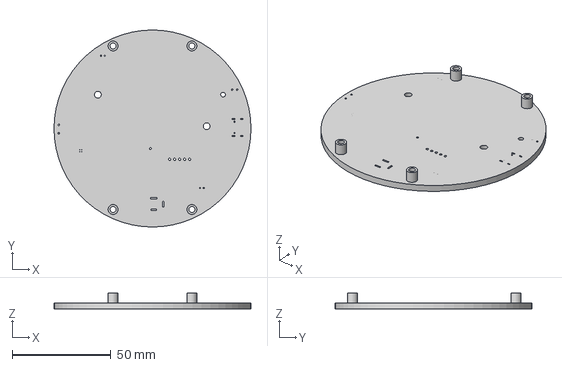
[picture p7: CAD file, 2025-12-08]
01_PROJETS/202604_089_Capteur_Environnemental_V1/03_CAO/Environnemental_sensor_V01/Noisyless v1.step
100.0 x 100.0 x 8.00 mm
Fond
fond_1

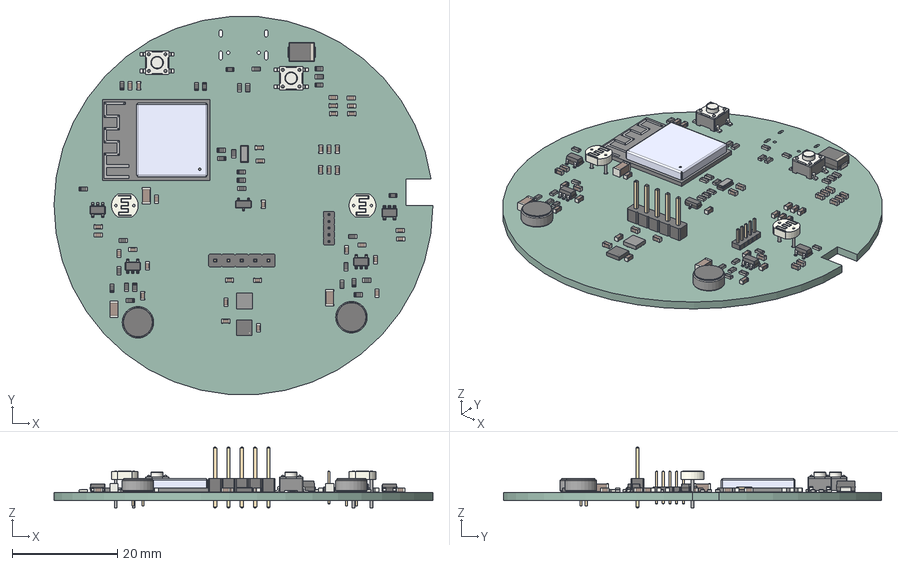
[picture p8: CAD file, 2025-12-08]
01_PROJETS/202604_089_Capteur_Environnemental_V1/03_CAO/Noisyless_RevB/Noisyless_RevB1.step
72.0 x 71.8 x 11.5 mm
C_0603_1608Metric x 35
C_1206_3216Metric x 3
R_0603_1608Metric x 30
PinHeader_1x05_P1.27mm_Vertical
Crystal_SMD_3215-2Pin_3.2x1.5mm
D_SMB
SOT-23
SOT-23-5 x 4
Bosch_LGA-8_3x3mm_P0.8mm_ClockwisePinNumbering
SW_SPST_PTS647Sx38 x 2
POM-2244P-C3310-2-R x 2
PinHeader_1x05_P2.54mm_Vertical
R_LDR_5.1x4.3mm_P3.4mm_Vertical x 2
ESP32-S3-MINI-1-N8
Pins
Noisyless_RevB_PCB

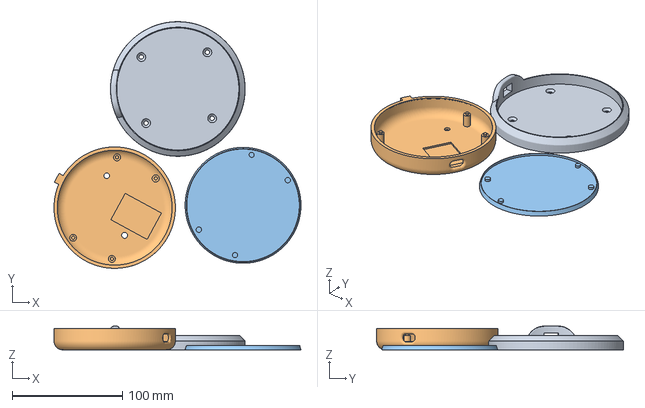
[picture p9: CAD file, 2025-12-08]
01_PROJETS/202604_089_Capteur_Environnemental_V1/04_FABRICATION/couvercle.3mf
223.8 x 223.5 x 21.6 mm
Corps1 x 2
couvercle

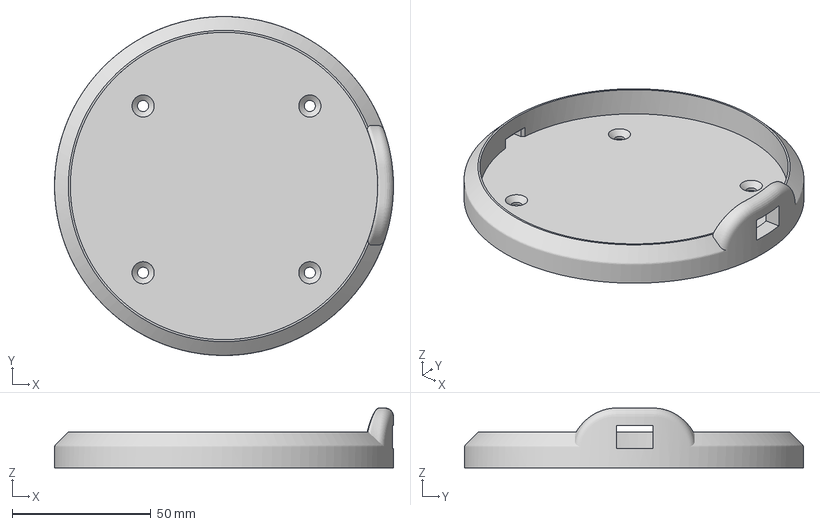
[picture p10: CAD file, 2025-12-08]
01_PROJETS/202604_089_Capteur_Environnemental_V1/04_FABRICATION/support.3mf
122.0 x 122.0 x 21.6 mm

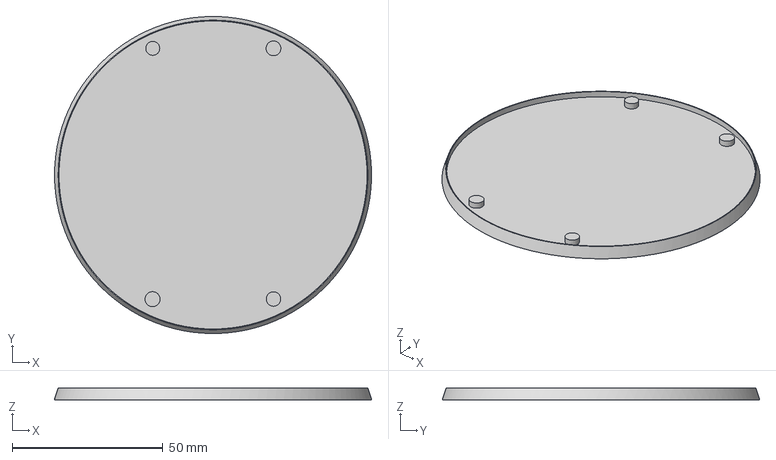
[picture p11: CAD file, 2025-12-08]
01_PROJETS/202604_089_Capteur_Environnemental_V1/04_FABRICATION/fond.3mf
105.0 x 105.0 x 4.00 mm

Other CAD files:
01_PROJETS/202604_089_Capteur_Environnemental_V1/03_CAO/Noisyless_RevB/Noisyless_RevB.f3d

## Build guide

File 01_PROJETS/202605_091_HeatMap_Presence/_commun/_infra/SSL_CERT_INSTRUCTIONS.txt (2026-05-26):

===========================================
LET'S ENCRYPT - DNS TXT RECORDS TO ADD
===========================================

Record 1:
---------
Type:   TXT
Name:   _acme-challenge.platform.noisyless.com
Value:  w5M-4ZML-ievZUAoyMdD2pG4yUs_ZdWgwhdhe6HkXlc
TTL:    300

Record 2:
---------
Type:   TXT
Name:   _acme-challenge.api.platform.noisyless.com
Value:  t56wDsqSqw2groeVfFJiDOM31wOjxggeJd6KOxW3q3k
TTL:    300

===========================================
INSTRUCTIONS:
===========================================

1. Go to your DNS registrar (OVH, Gandi, Cloudflare, etc.)

2. Add BOTH TXT records above

3. Wait 2-10 minutes for DNS propagation

4. Verify with:
   dig _acme-challenge.platform.noisyless.com TXT
   dig _acme-challenge.api.platform.noisyless.com TXT

5. Once both records return the correct values,
   the SSL certificate can be generated

===========================================
COMMAND TO GENERATE CERTIFICATE (after DNS):
===========================================

ssh -i ~/.ssh/id_ed25519 noisyless@91.99.26.43

cd /opt/noisyless

docker run --rm \
  -v /opt/noisyless/nginx/ssl:/etc/letsencrypt \
  certbot/certbot certonly --manual \
  -d platform.noisyless.com \
  -d api.platform.noisyless.com \
  --email contact@noisyless.com \
  --agree-tos --non-interactive \
  --preferred-challenges dns

Then restart nginx:
docker compose restart nginx

===========================================

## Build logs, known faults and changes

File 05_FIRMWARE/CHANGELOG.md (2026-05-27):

# Firmware Changelog

## v1.0.8 — 2026-05-27
- 🔴 LED rouge si WiFi perdu dans loop()
- Comportement LED inchangé quand WiFi ok

## v1.0.7 — 2026-05-27
- Swap mapping LED R/G (GPIO12=rouge, GPIO13=vert) après constat inversion physique
- Correction bug LED jaune (vert allumé avant publication MQTT)
- Clignotement bleu version au boot (3ème chiffre)

## v1.0.5 — 2026-05-27
- LEDs en actif bas (LOW = allumé)
- OTA code prêt, sans partitions OTA dédiées

## v1.0.4 — 2026-05-27
- WiFi + MQTT + OTA + capteurs analogiques
- Build ESP32-S3 QIO natif, full erase
- Correction mot de passe WiFi

## v1.0.1 — 2026-05-26
- OTA check toutes les 60s
- WiFi dur, MQTT, capteurs analogiques

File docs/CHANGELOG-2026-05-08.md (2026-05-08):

# Session du 2026-05-07 / 2026-05-08

## Resume

Premiere mise en service end-to-end : ESP32 physique -> MQTT VPS -> DB -> dashboard live.

## Realisations chronologiques

### 1. Audit (2026-05-07 17h)
- Lecture complete de `05_FIRMWARE/src/main.cpp` (907 lignes)
- Lecture de `noisyless-platform-mvp/` (FastAPI + TimescaleDB + Vue3)
- Lecture de `HANDOFF.md` (etat du dashboard)
- Identification des 5 gaps bloquants vente (WiFi hardcode, MQTT broker incorrect, pas d'ingest, mosquitto down, conversion mic manquante)
- Document : `PLAN_J5_VENTE.md`

### 2. Service mqtt_ingest (2026-05-07 17h-18h)
- Code Python ~150 lignes (paho-mqtt + psycopg2)
- Conversion ADC mic -> dB SPL (formule log)
- Conversion ADC lux -> lux (lineaire 0.25)
- Reconnexion auto MQTT + DB
- Container Docker avec `restart: unless-stopped`
- Document : `deploy/mqtt-ingest/mqtt_ingest.py`

### 3. Deploiement VPS Hetzner (2026-05-07 18h)
- Script `deploy-vps.sh` idempotent
- Fix volumes mosquitto (double-mount config + certs)
- Ajout port 1883 expose
- Creation passwd avec UID 1883 (mosquitto user)
- Ajout `firmware_version` colonne dans table `devices`

### 4. Test MQTT simule + DB (2026-05-07 19h)
- `mosquitto_pub` test message -> ingest -> insert DB OK
- Pipeline valide AVANT branchement firmware reel

### 5. Compilation firmware (2026-05-08 08h-09h)
- Installation PlatformIO en venv Python (`/home/mathieu/.pio-venv/`)
- Premier build : 10 min (toolchain RISC-V + framework Arduino + esptool)
- Output : `firmware.bin` 976 KB
- Modification `credentials.h` pour pointer MQTT vers 91.99.26.43

### 6. Premier flash + connexion live (2026-05-08 09h)
- ESP32 detecte sur `/dev/ttyACM0`
- Flash 6 sec
- WiFi `TP-Link_B150` connecte (RSSI -47 dBm)
- BSEC2 init OK : temp 24.49C, hum 47%, IAQ 50, CO2 500ppm
- MQTT connecte au VPS
- Donnees inserees toutes les 10s -> dashboard

### 7. Probleme LD2410 (2026-05-08 13h)
- LD2410 d'origine : capteur defectueux (pas de LED rouge)
- Mathieu reconnecte un autre capteur fonctionnel
- Mais la lib `ncmreynolds/ld2410@^0.1.4` echoue toujours `radar.begin()`
- Test bauds 256000 / 9600 : aucune reponse

### 8. Diagnostic UART brut (2026-05-08 13h)
- Ajout fonction `diagRadarRaw()` qui dump les bytes bruts
- Reset ESP32 via DTR/RTS pour capturer les logs DIAG au boot
- DECOUVERTE : le LD2410 envoie bien des frames a 256000 baud (`F4 F3 F2 F1 ... F8 F7 F6 F5`)
- La lib etait buggee, pas le hardware

### 9. Parser LD2410 custom (2026-05-08 13h)
- Implementation `parseLD2410Stream()` ~50 lignes
- Base sur datasheet HLK-LD2410 V1.02 fournie par Mathieu
- Parse type frame `02 AA` (target data) avec state, distances moving/stationary, energies, detection_dist
- Bypass complet de la lib
- Re-flash, presence detectee : distance 30-115 cm selon mouvement

### 10. Bug dashboard (2026-05-08 13h)
- Symptome : seul `lux` s'affichait, autres champs vides
- Cause : `/api/devices/{id}/live` retourne format imbrique (`bme.temp`, `ld2410.presence`, `mic.db_avg`) mais dashboard.html lisait en plat (`d.live.temp`, etc.)
- Fix : remplacement par `d.live.bme?.temp`, `d.live.ld2410?.presence`, `d.live.mic?.db_avg`
- Upload + nginx reload

### 11. Documentation (2026-05-08 13h30)
- `docs/ARCHITECTURE.md` (ce repo)
- `docs/CHANGELOG-2026-05-08.md` (ce fichier)

## Donnees live actuellement (2026-05-08 13h)

Device : NL-001 (MAC B43A45B7A9B0)
Mesures toutes les 10s :
- Temp 27.1-27.5°C
- Humidite 43-47%
- IAQ 50 (stabilisation)
- CO2 500 ppm
- Pression 95867 Pa (cohérent altitude)
- Presence : detecte dynamiquement avec distance 30-150 cm
- Bruit 74-82 dB (selon environnement)
- Lumiere : variable selon eclairage piece

## Fix permanents appliques

1. `claw-postgres` (autre infra MBHHOLD) : `restart=unless-stopped` (etait `no`)
2. `claw-postgres` reconnecte au reseau Docker avec alias DNS
3. Mosquitto compose : volumes corriges (separer config et certs)
4. Mosquitto config : listener 1883 avec auth password_file
5. mqtt_ingest : `ON CONFLICT DO NOTHING` sur measurements (idempotent)
6. mqtt_ingest : auto-reconnect DB si OperationalError
7. Firmware : parser LD2410 custom remplace lib

## Restant pour J+5 (vente)

Voir `PLAN_J5_VENTE.md` section "PLAN J+5".
- WiFiManager (provisioning client)
- Device ID auto (MAC)
- LED status
- Webhook Stripe -> creation compte
- Tunnel acquisition sur noisyless.com (CTAs Stripe)
- OTA GitHub Actions

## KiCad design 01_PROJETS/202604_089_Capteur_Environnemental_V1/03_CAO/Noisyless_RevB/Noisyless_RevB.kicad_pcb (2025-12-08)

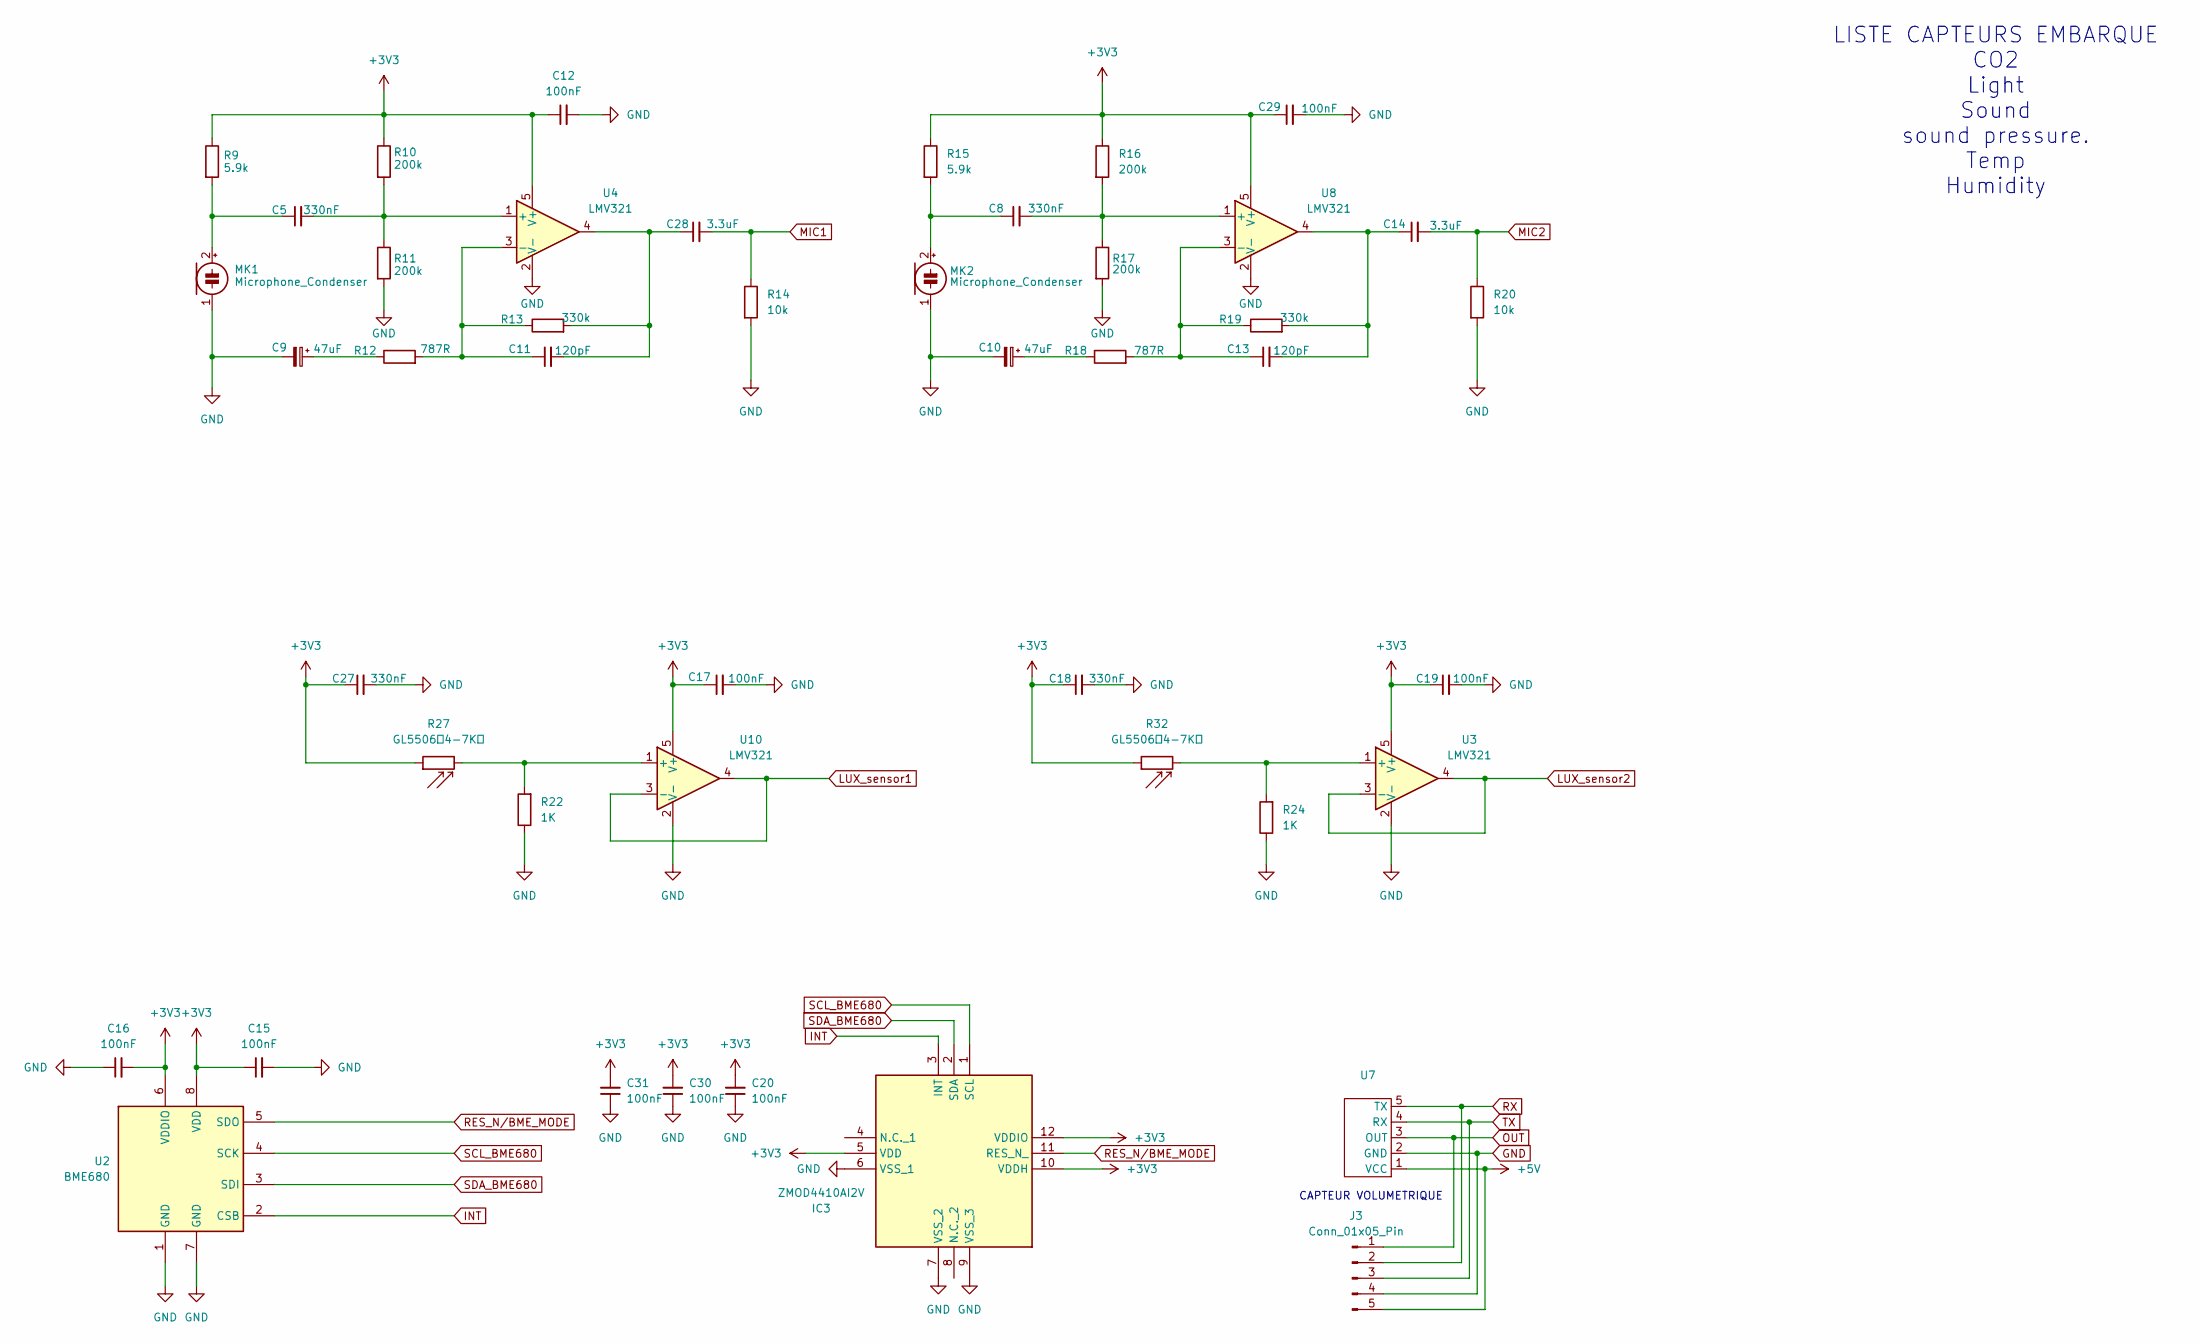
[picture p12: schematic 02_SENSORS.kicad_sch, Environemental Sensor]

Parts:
C5, C8, C18, C27: 330nF; C_0603_1608Metric_Pad1.08x0.95mm_HandSolder; LCSC Part # C282682
C9, C10: 47uF; C_1206_3216Metric; LCSC Part # C94034
C11, C13: 120pF; C_0603_1608Metric_Pad1.08x0.95mm_HandSolder; LCSC Part # C107035
C12, C15, C16, C17, C19, C20, C29, C30, C31: 100nF; C_0603_1608Metric_Pad1.08x0.95mm_HandSolder; LCSC Part # C30926
C14, C28: 3.3uF; C_0603_1608Metric_Pad1.08x0.95mm_HandSolder; LCSC Part # C5360803
IC3: ZMOD4410AI2V; Mouser Part Number 968-ZMOD4410AI2V
J3: Conn_01x05_Pin; HL2410A
MK1, MK2: Microphone_Condenser; POM-2244P-C3310-2-R; LCSC Part # C233939
R9, R15: 5.9k; R_0603_1608Metric; LCSC Part # C23071
R10, R11, R16, R17: 200k; R_0603_1608Metric; LCSC Part # C25811
R12, R18: 787R; R_0603_1608Metric; LCSC Part # C137683
R13, R19: 330k; R_0603_1608Metric; LCSC Part # C25804
R14, R20: 10k; R_0603_1608Metric; LCSC Part # C25804
R22, R24: 1K; R_0603_1608Metric; LCSC Part # C21190
R27, R32: GL5506（4-7K）; R_LDR_5.1x4.3mm_P3.4mm_Vertical; LCSC Part # C11299
U2: BME680; Bosch_LGA-8_3x3mm_P0.8mm_ClockwisePinNumbering; LCSC Part # C125972
U3, U4, U8, U10: LMV321; SOT-23-5_HandSoldering; LCSC Part # C395459
U7: HL2410

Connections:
+3V3: C12.1, C15.1, C16.2, C17.1, C18.1, C19.1, C20.2, C27.1, C29.1, C30.2, C31.2, IC3.5 (VDD), IC3.10 (VDDH), IC3.12 (VDDIO), R9.1, R10.1, R15.1, R16.1, R27.1, R32.1, U2.6 (VDDIO), U2.8 (VDD), U3.5 (V+), U4.5 (V+), U8.5 (V+), U10.5 (V+); also elsewhere on the board
+5V: J3.5, U7.1 (VCC); also elsewhere on the board
GND: C9.2, C10.2, C12.2, C15.2, C16.1, C17.2, C18.2, C19.2, C20.1, C27.2, C29.2, C30.1, C31.1, IC3.6 (VSS_1), IC3.7 (VSS_2), IC3.9 (VSS_3), J3.4, MK1.1 (-), MK2.1 (-), R11.2, R14.2, R17.2, R20.2, R22.1, R24.1, U2.1 (GND), U2.7 (GND), U3.2 (V-), U4.2 (V-), U7.2 (GND), U8.2 (V-), U10.2 (V-); also elsewhere on the board
INT: IC3.3 (INT), U2.2 (CSB); also elsewhere on the board
LUX_sensor1: U10.3 (-), U10.4; also elsewhere on the board
LUX_sensor2: U3.3 (-), U3.4; also elsewhere on the board
MIC1: C28.2, R14.1; also elsewhere on the board
MIC2: C14.2, R20.1; also elsewhere on the board
unnamed: C9.1, R12.1
unnamed: C10.1, R18.1
unnamed: C11.2, C28.1, R13.2, U4.4
unnamed: C13.2, C14.1, R19.2, U8.4
unnamed: C5.1, MK1.2 (+), R9.2
unnamed: C8.1, MK2.2 (+), R15.2
unnamed: R24.2, R32.2, U3.1 (+)
unnamed: C5.2, R10.2, R11.1, U4.1 (+)
unnamed: C11.1, R12.2, R13.1, U4.3 (-)
unnamed: C8.2, R16.2, R17.1, U8.1 (+)
unnamed: C13.1, R18.2, R19.1, U8.3 (-)
unnamed: R22.2, R27.2, U10.1 (+)
OUT: J3.1, U7.3 (OUT); also elsewhere on the board
RES_N/BME_MODE: IC3.11 (RES_N_), U2.5 (SDO); also elsewhere on the board
RX: J3.2, U7.5 (TX); also elsewhere on the board
SCL_BME680: IC3.1 (SCL), U2.4 (SCK); also elsewhere on the board
SDA_BME680: IC3.2 (SDA), U2.3 (SDI); also elsewhere on the board
TX: J3.3, U7.4 (RX); also elsewhere on the board

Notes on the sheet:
CAPTEUR VOLUMETRIQUE
LISTE CAPTEURS EMBARQUE CO2 Light Sound sound pressure. Temp Humidity

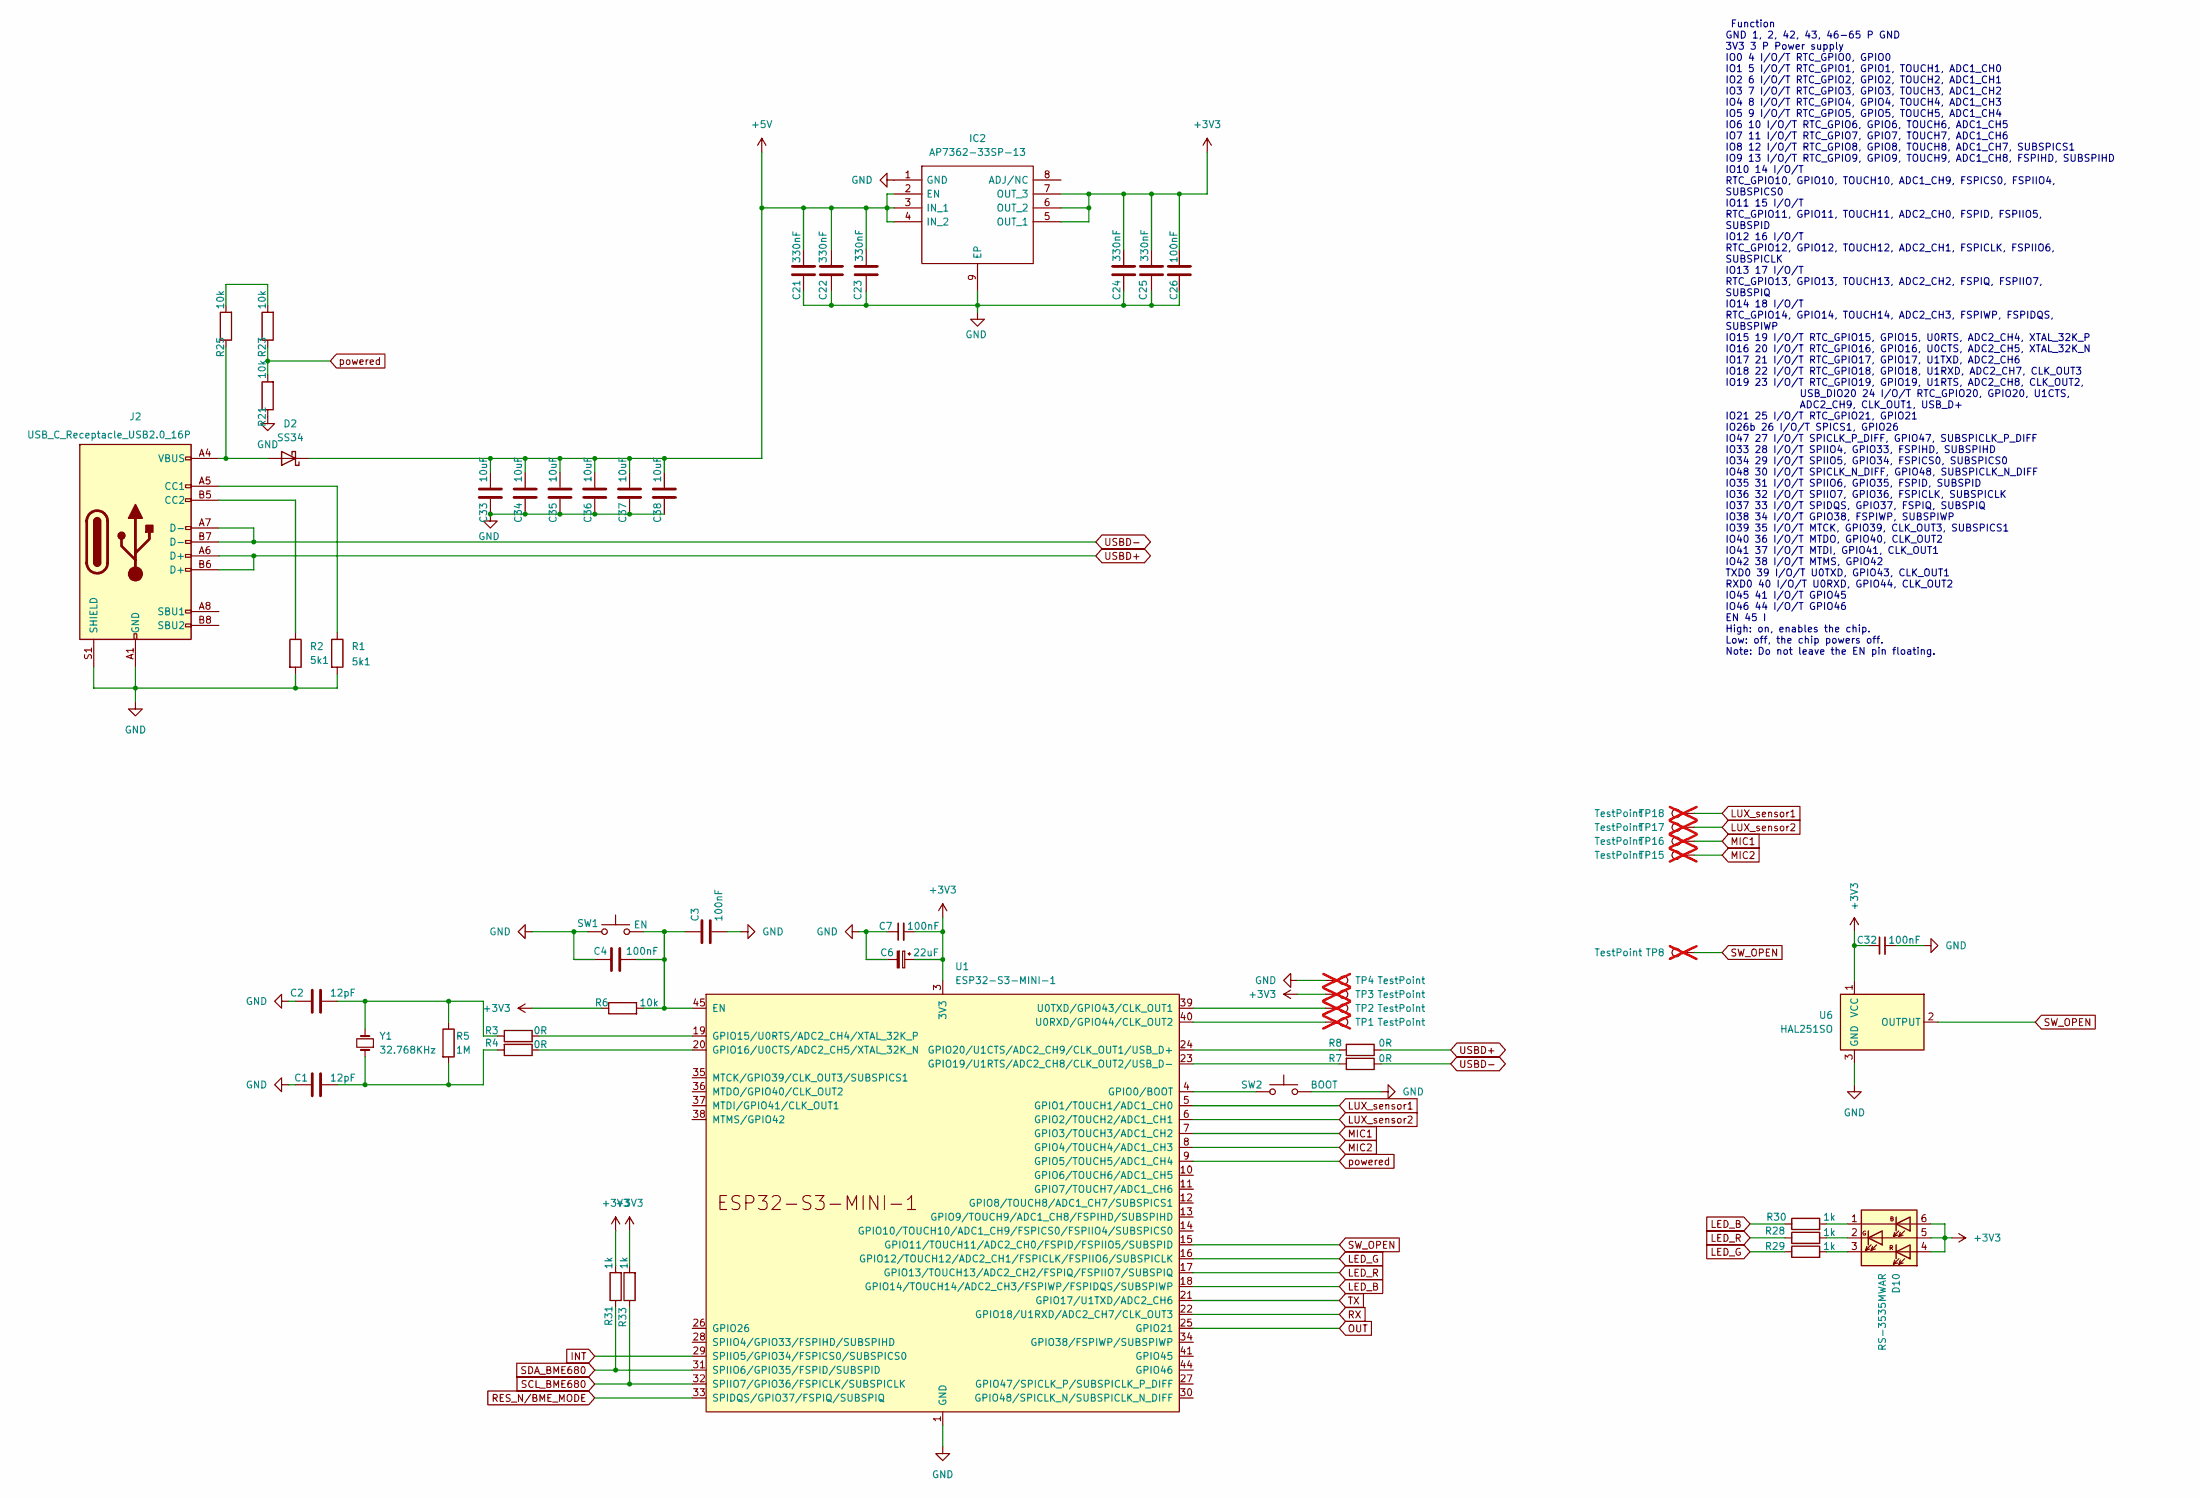
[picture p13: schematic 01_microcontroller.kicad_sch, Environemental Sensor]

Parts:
C1, C2: 12pF; C_0603_1608Metric_Pad1.08x0.95mm_HandSolder; LCSC Part # C107034
C3, C4, C7, C26, C32: 100nF; C_0603_1608Metric_Pad1.08x0.95mm_HandSolder; LCSC Part # C30926
C6: 22uF; C_1206_3216Metric; LCSC Part # C2835562
C21, C22, C23, C24, C25: 330nF; C_0603_1608Metric_Pad1.08x0.95mm_HandSolder; LCSC Part # C282682
C33, C34, C35, C36, C37, C38: 10uF; C_0603_1608Metric_Pad1.08x0.95mm_HandSolder; LCSC Part # C19702
D2: SS34; D_SMA-SMB_Universal_Handsoldering; LCSC Part # C8678
D10: RS-3535MWAR; LED_RGB_PLCC-6; LCSC Part # C110402
IC2: AP7362-33SP-13; SOIC127P600X150-9N; LCSC Part # C780775
J2: USB_C_Receptacle_USB2.0_16P; USB_C_Receptacle_G-Switch_GT-USB-7010ASV; LCSC Part # C2988369
R1, R2: 5k1; R_0603_1608Metric; LCSC Part # C23186
R3, R4, R7, R8: 0R; R_0603_1608Metric; LCSC Part # C21189
R5: 1M; R_0603_1608Metric; LCSC Part # C22935
R6, R21, R23, R25: 10k; R_0603_1608Metric; LCSC Part # C25804
R28, R29, R30, R31, R33: 1k; R_0603_1608Metric; LCSC Part # C21190
SW1: EN; SW_SPST_PTS647_Sx38; LCSC Part # C2689502
SW2: BOOT; SW_SPST_PTS647_Sx38; LCSC Part # C2689502
TP1, TP2, TP3, TP4, TP8, TP15, TP16, TP17, TP18: TestPoint; TestPoint_Pad_D3.0mm; not fitted
U1: ESP32-S3-MINI-1; LCSC Part # C2913206
U6: HAL251SO; SOT-23; LCSC Part # C5261092
Y1: 32.768KHz; Crystal_SMD_3215-2Pin_3.2x1.5mm; LCSC Part # C97606

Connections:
+3V3: C6.1, C7.2, C24.2, C25.2, C26.2, C32.1, D10.4 (AR), D10.5 (AG), D10.6 (AB), IC2.5 (OUT_1), IC2.6 (OUT_2), IC2.7 (OUT_3), R6.1, R31.2, R33.2, TP3.1, U1.3 (3V3), U6.1 (VCC); also elsewhere on the board
+5V: C21.2, C22.2, C23.2, C33.2, C34.2, C35.2, C36.2, C37.2, C38.2, D2.1 (K), IC2.2 (EN), IC2.3 (IN_1), IC2.4 (IN_2); also elsewhere on the board
GND: C1.1, C2.1, C3.1, C4.1, C6.2, C7.1, C21.1, C22.1, C23.1, C24.1, C25.1, C26.1, C32.2, C33.1, C34.1, C35.1, C36.1, C37.1, C38.1, IC2.1 (GND), IC2.9 (EP), J2.A1 (GND), J2.A12 (GND), J2.B1 (GND), J2.B12 (GND), J2.S1 (SHIELD), R1.2, R2.2, R21.1, SW1.1, SW2.2, TP4.1, U1.1 (GND), U1.2 (GND), U1.42 (GND), U1.43 (GND), U1.46 (GND), U1.47 (GND), U1.48 (GND), U1.49 (GND), U1.50 (GND), U1.51 (GND), U1.52 (GND), U1.53 (GND), U1.54 (GND), U1.55 (GND), U1.56 (GND), U1.57 (GND), U1.58 (GND), U1.59 (GND), U1.60 (GND), U1.61 (GND), U1.62 (GND), U1.63 (GND), U1.64 (GND), U1.65 (GND), U6.3 (GND); also elsewhere on the board
INT: U1.29 (SPIIO5/GPIO34/FSPICS0/SUBSPICS0); also elsewhere on the board
LED_B: R30.1, U1.18 (GPIO14/TOUCH14/ADC2_CH3/FSPIWP/FSPIDQS/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)
LED_G: R29.1, U1.16 (GPIO12/TOUCH12/ADC2_CH1/FSPICLK/FSPIIO6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)
LED_R: R28.1, U1.17 (GPIO13/TOUCH13/ADC2_CH2/FSPIQ/FSPIIO7/S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)
LUX_sensor1: TP18.1, U1.5 (GPIO1/TOUCH1/ADC1_CH0); also elsewhere on the board
LUX_sensor2: TP17.1, U1.6 (GPIO2/TOUCH2/ADC1_CH1); also elsewhere on the board
MIC1: TP16.1, U1.7 (GPIO3/TOUCH3/ADC1_CH2); also elsewhere on the board
MIC2: TP15.1, U1.8 (GPIO4/TOUCH4/ADC1_CH3); also elsewhere on the board
unnamed: C1.2, R4.2, R5.2, Y1.1
unnamed: C2.2, R3.1, R5.1, Y1.2
unnamed: D2.2 (A), J2.A4 (VBUS), J2.A9 (VBUS), J2.B4 (VBUS), J2.B9 (VBUS), R25.1
unnamed: D10.1 (KB), R30.2
unnamed: D10.2 (KG), R28.2
unnamed: D10.3 (KR), R29.2
unnamed: J2.A5 (CC1), R1.1
unnamed: J2.B5 (CC2), R2.1
unnamed: R23.2, R25.2
unnamed: C3.2, C4.2, R6.2, SW1.2, U1.45 (EN)
unnamed: SW2.1, U1.4 (GPIO0/BOOT)
unnamed: R3.2, U1.19 (GPIO15/U0RTS/ADC2_CH4/XTAL_32K_P)
unnamed: R4.1, U1.20 (GPIO16/U0CTS/ADC2_CH5/XTAL_32K_N)
unnamed: R7.2, U1.23 (GPIO19/U1RTS/ADC2_CH8/CLK_OUT2/USB_D-)
unnamed: R8.2, U1.24 (GPIO20/U1CTS/ADC2_CH9/CLK_OUT1/USB_D+)
unnamed: TP1.1, U1.40 (U0RXD/GPIO44/CLK_OUT2)
unnamed: TP2.1, U1.39 (U0TXD/GPIO43/CLK_OUT1)
OUT: U1.25 (GPIO21); also elsewhere on the board
RES_N/BME_MODE: U1.33 (SPIDQS/GPIO37/FSPIQ/SUBSPIQ); also elsewhere on the board
RX: U1.22 (GPIO18/U1RXD/ADC2_CH7/CLK_OUT3); also elsewhere on the board
SCL_BME680: R33.1, U1.32 (SPIIO7/GPIO36/FSPICLK/SUBSPICLK); also elsewhere on the board
SDA_BME680: R31.1, U1.31 (SPIIO6/GPIO35/FSPID/SUBSPID); also elsewhere on the board
SW_OPEN: TP8.1, U1.15 (GPIO11/TOUCH11/ADC2_CH0/FSPID/FSPIIO5/S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), U6.2 (OUTPUT)
TX: U1.21 (GPIO17/U1TXD/ADC2_CH6); also elsewhere on the board
USBD+: J2.A6 (D+), J2.B6 (D+), R8.1
USBD-: J2.A7 (D-), J2.B7 (D-), R7.1
powered: R21.2, R23.1, U1.9 (GPIO5/TOUCH5/ADC1_CH4)

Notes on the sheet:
Function GND 1, 2, 42, 43, 46-65 P GND 3V3 3 P Power supply IO0 4 I/O/T RTC_GPIO0, GPIO0 IO1 5 I/O/T RTC_GPIO1, GPIO1, TOUCH1, ADC1_CH0 IO2 6 I/O/T RTC_GPIO2, GPIO2, TOUCH2, ADC1_CH1 IO3 7 I/O/T RTC_GPIO3, GPIO3, TOUCH3, ADC1_CH2 IO4 8 I/O/T RTC_GPIO4, GPIO4, TOUCH4, ADC1_CH3 IO5 9 I/O/T RTC_GPIO5,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

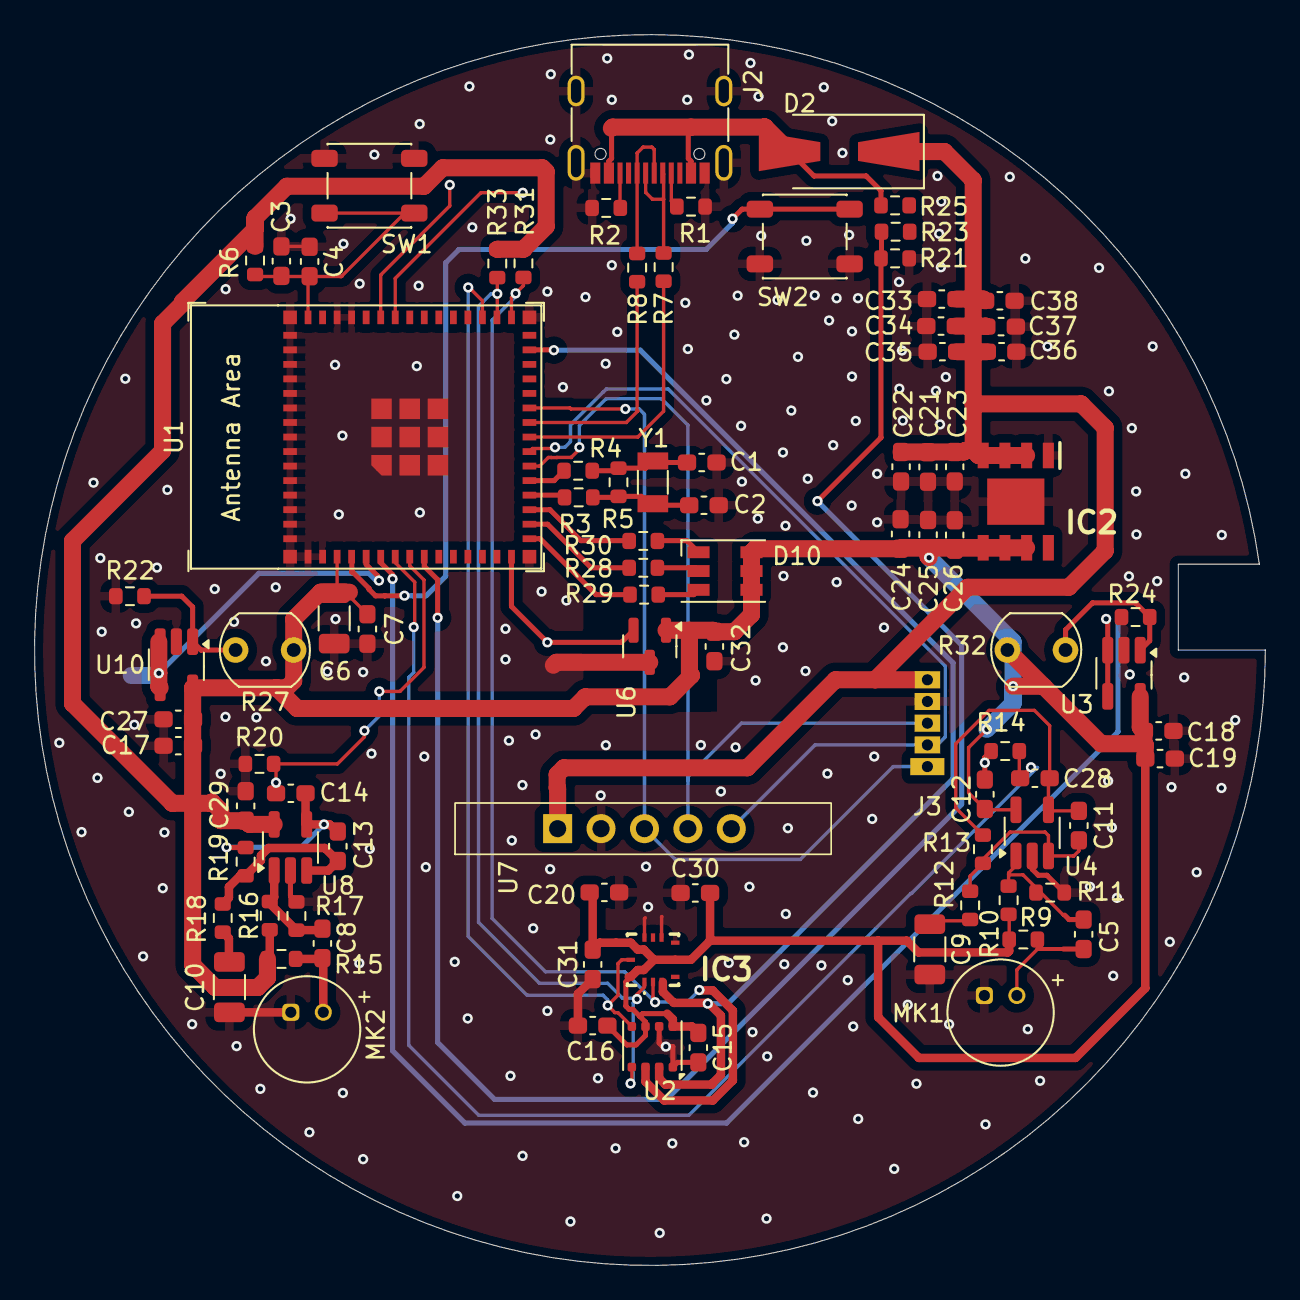
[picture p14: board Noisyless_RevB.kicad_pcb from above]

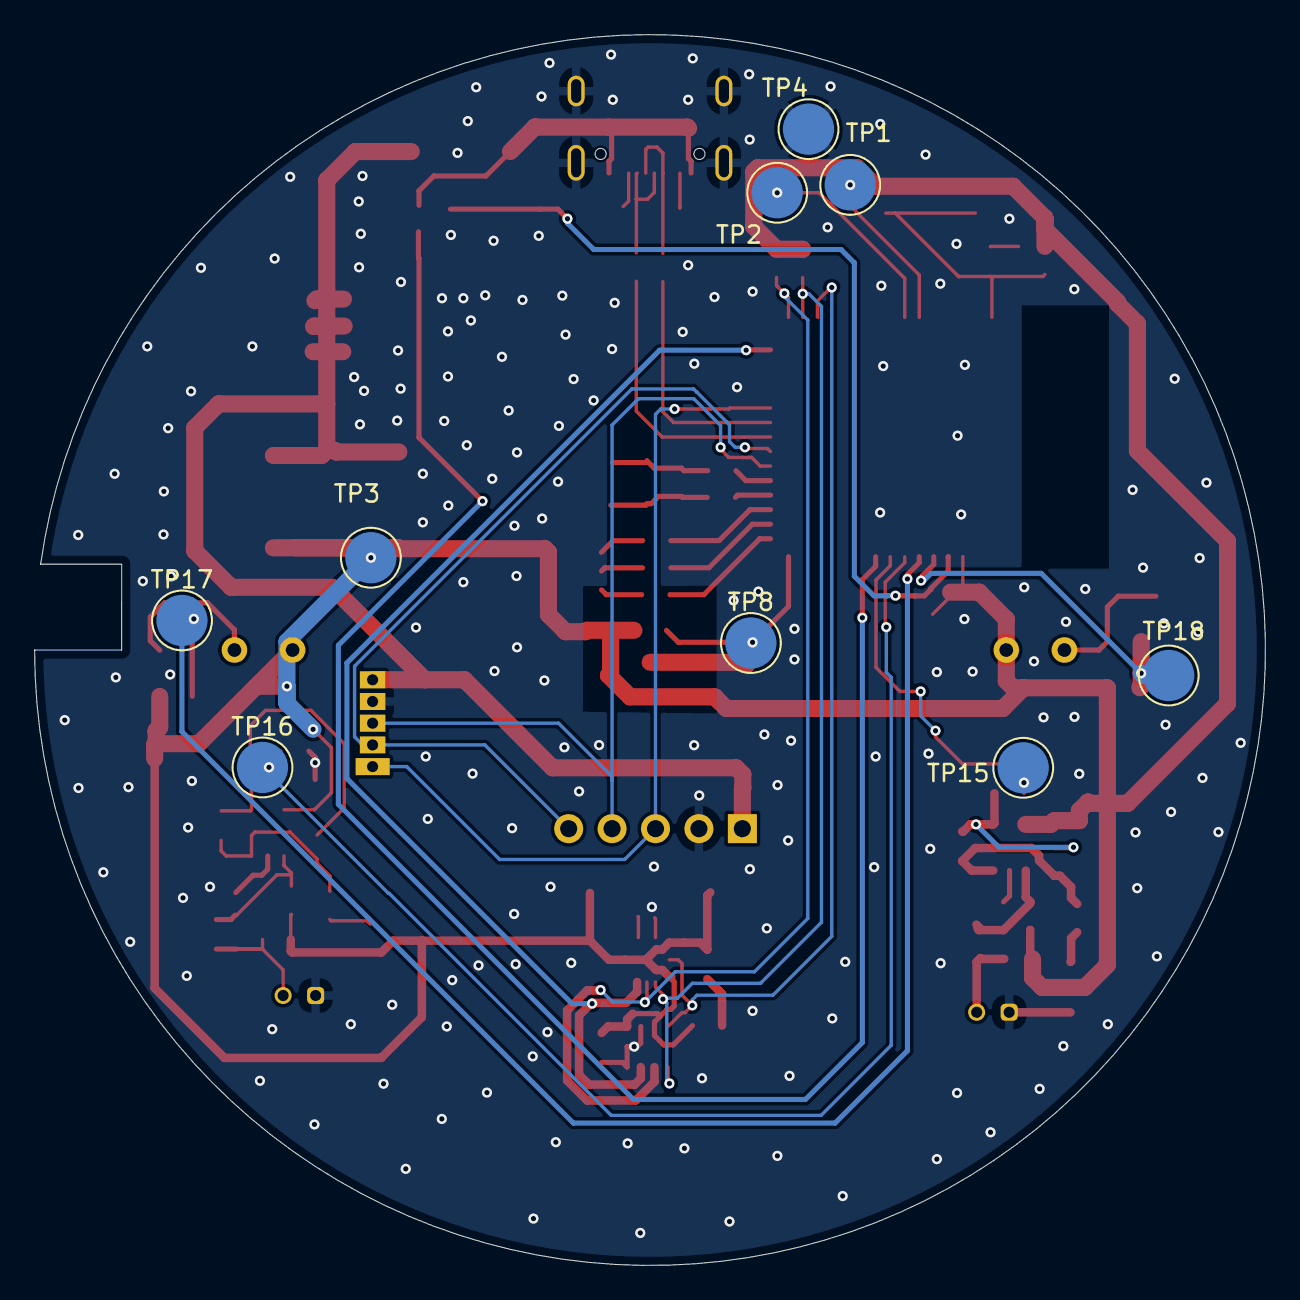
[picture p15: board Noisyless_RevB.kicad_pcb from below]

Board: 2 copper layers, 72.0 x 72.0 mm, 98 parts (9 on the bottom side), 50 nets.

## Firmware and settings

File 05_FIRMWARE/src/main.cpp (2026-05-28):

// Firmware Noisyless - ESP32-S3
// Capteurs: BME680 (I2C), LD2410 (UART)
// Réseau: WiFi + MQTT (PubSubClient)

#include <Arduino.h>
#include <WiFi.h>
#include <WiFiManager.h>
#include <PubSubClient.h>
#include <Wire.h>
#include <bsec2.h>    // Préférer l'API Bsec (compatible BSEC2 Arduino)
#include <HardwareSerial.h>
#include <ld2410.h>  // Bibliothèque LD2410 (ncmreynolds/ld2410@^0.1.4)
#include <HTTPClient.h>
#include <Update.h>
#include <mbedtls/sha256.h>
#include <Preferences.h>

#include "credentials.h"  // Contient uniquement les secrets MQTT
// -------------------- Brochage --------------------
static const int PIN_LUX1_AIN = 1;
static const int PIN_LUX2_AIN = 2;
static const int PIN_MIC1 = 3;
static const int PIN_MIC2 = 4;
static const int PIN_SYSTEM_POWERED = 5;
static const int PIN_SW_OPEN = 11;
static const int PIN_LED_B = 14;  // actif bas (0 = allumé)
static const int PIN_LED_G = 13;  // actif bas
static const int PIN_LED_R = 12;  // actif bas
static const int PIN_LD2410_RX_ESP = 18;  // LD2410 TX → ESP RX
static const int PIN_LD2410_TX_ESP = 17;  // LD2410 RX → ESP TX
static const int PIN_OUT_SIGNAL = 21;
static const int PIN_BME_INT = 34;
static const int PIN_I2C_SDA = 35;
static const int PIN_I2C_SCL = 36;
static const int PIN_BME_MODE = 37;

// -------------------- Configuration Produit --------------------
static const char* WIFI_SSID = "TP-Link_B150";
static const char* WIFI_PASS = "12902637";

// WiFiManager — captive portal pour configuration client
static WiFiManager wifiManager;
static Preferences prefs;
static const char* PREFS_NS = "noisyless";

static const char* PRODUCT = "noisyless_env";
static const char* CLIENT_CODE = "client_demo";
static char DEVICE_ID[20] = {0};  // NL-XXXXXXXXXXXX (base MAC, generé au boot)
static char CLIENT_ID[32] = {0};   // noisyless_<device_id>
static const char* FW_VERSION = "0.0.3";

static const unsigned long PUBLISH_INTERVAL_MS = 10000UL;  // 10s
static const unsigned long SENSOR_ADC_WINDOW_MS = 50UL;
static const unsigned long RADAR_READ_PERIOD_MS = 100UL;
static const unsigned long OTA_CHECK_INTERVAL_MS = 3600000UL; // 1h
// Manifest OTA (canal: stable)
static const char* OTA_MANIFEST_URL = "https://raw.githubusercontent.com/mberthod/noisyless/main/ota/stable.json";
static const char* OTA_USER_AGENT = "Noisyless-ESP32";

// -------------------- Objets globaux --------------------
WiFiClient espClient;
PubSubClient mqtt(espClient);

ld2410 radar;                   // Capteur LD2410
HardwareSerial& RadarSerial = Serial1;


#define ERROR_DUR 1000

#define SAMPLE_RATE BSEC_SAMPLE_RATE_ULP


static bool g_bsec_ok = false;
static bool g_ld_ok = false;
static unsigned long g_lastBsecInitAttemptMs = 0;
static unsigned long g_lastPublishMs = 0;
static char g_mqttTopic[128] = {0};
static char g_mqttTopicLine[128] = {0};
static char g_macStr[20] = {0};
void newDataCallback(const bme68xData data, const bsecOutputs outputs, Bsec2 bsec);

/* Create an object of the class Bsec2 */
Bsec2 envSensor;

// Dernières valeurs BSEC pour alimentation du JSON
struct BsecLastValues {
  bool valid = false;
  float temp_comp_c = 0.0f;
  float hum_comp_pct = 0.0f;
  uint32_t pressure_pa = 0;
  uint32_t gas_ohms = 0;
  float raw_temp_c = 0.0f;
  float raw_hum_pct = 0.0f;
  uint32_t raw_gas_ohms = 0;
  float iaq = 0.0f;
  float s_iaq = 0.0f;
  float co2eq_ppm = 0.0f;
  float bvoc_eq_ppm = 0.0f;
  float gas_pct = 0.0f;
  uint8_t iaq_accuracy = 0;
  uint8_t stab_status = 0;
  uint8_t run_in_status = 0;
};
static volatile BsecLastValues g_bsec_last;

// Données partagées (protégées par mutex)
struct SharedMeasurements {
  BsecLastValues bsec;
  bool presence = false;
  uint16_t distance_cm = 0;
  uint16_t lux1_raw = 0;
  uint16_t lux2_raw = 0;
  uint16_t mic1_pp = 0;
  uint16_t mic2_pp = 0;
};
static SharedMeasurements g_shared{};
static SemaphoreHandle_t g_sharedMutex = nullptr;
static SemaphoreHandle_t g_otaMutex = nullptr;  // ProtègeOTA check/flash
static bool g_otaRunning = false;                // Drapeau: OTA en cours


// ------------------------------------------------
// Traduction des codes d'erreur MQTT
static const char* mqttError(int8_t code) {
  switch (code) {
    case -4: return "MQTT_CONNECTION_TIMEOUT";
    case -3: return "MQTT_CONNECTION_LOST";
    case -2: return "MQTT_CONNECT_FAILED";
    case -1: return "MQTT_DISCONNECTED";
    case  0: return "MQTT_CONNECTED";
    case  1: return "MQTT_CONNECT_BAD_PROTOCOL";
    case  2: return "MQTT_CONNECT_BAD_CLIENT_ID";
    case  3: return "MQTT_CONNECT_UNAVAILABLE";
    case  4: return "MQTT_CONNECT_BAD_CREDENTIALS";
    case  5: return "MQTT_CONNECT_NOT_AUTHORIZED";
  }
  return "UNKNOWN";
}

void errLeds(void)
{
  digitalWrite(PIN_LED_R, HIGH);
  delay(100);
  digitalWrite(PIN_LED_R, LOW);
  delay(100);
}

void checkBsecStatus(Bsec2 bsec)
{
  if (bsec.status < BSEC_OK)
  {
    Serial.println("BSEC error code : " + String(bsec.status));
    errLeds(); /* Blink LEDs once, then continue */
  }
  else if (bsec.status > BSEC_OK)
  {
    Serial.println("BSEC warning code : " + String(bsec.status));
  }

  if (bsec.sensor.status < BME68X_OK)
  {
    Serial.println("BME68X error code : " + String(bsec.sensor.status));
    errLeds(); /* Blink LEDs once, then continue */
  }
  else if (bsec.sensor.status > BME68X_OK)
  {
    Serial.println("BME68X warning code : " + String(bsec.sensor.status));
  }
}
// ------------------------------------------------
// Connexion au WiFi avec WiFiManager + captive portal
// Premier boot : captive portal "NOISYLESS-Setup"
// Boots suivants : auto-connect via NVS
void connectWiFi() {
  if (WiFi.status() == WL_CONNECTED) return;

  // LED rouge pendant connexion
  digitalWrite(PIN_LED_R, LOW);   // allumé (actif bas)
  digitalWrite(PIN_LED_G, HIGH);
  digitalWrite(PIN_LED_B, HIGH);

  prefs.begin(PREFS_NS, false);
  String savedSSID = prefs.getString("ssid", "");
  String savedPass = prefs.getString("pass", "");

  if (savedSSID.length() > 0) {
    // Credentials déjà sauvegardés → auto-connect
    Serial.printf("[WiFi] Auto-connect to saved AP \"%s\"\n", savedSSID.c_str());
    WiFi.mode(WIFI_STA);
    WiFi.begin(savedSSID.c_str(), savedPass.c_str());

    int dots = 0;
    while (WiFi.status() != WL_CONNECTED && dots < 30) { // timeout 15s
      delay(500);
      Serial.print(".");
      dots++;
    }
    if (WiFi.status() == WL_CONNECTED) {
      digitalWrite(PIN_LED_R, HIGH); // LED éteinte
      Serial.println("\n[WiFi] Connected to saved AP");
      prefs.end();
      return;
    }
    // Échec auto-connect → fallback captive portal
    Serial.println("\n[WiFi] Saved AP failed, starting captive portal...");
  }

  // Captive portal "NOISYLESS-Setup"
  wifiManager.setConfigPortalTimeout(180); // 3 minutes
  wifiManager.setAPCallback([](WiFiManager* mgr) {
    Serial.println("[WiFiManager] Captive portal ACTIVE — connect to 'NOISYLESS-Setup'");
    // LED bleue = captive portal actif
    digitalWrite(PIN_LED_R, HIGH);
    digitalWrite(PIN_LED_G, HIGH);
    digitalWrite(PIN_LED_B, LOW);  // allumé (actif bas)
  });

  Serial.println("[WiFi] Starting captive portal...");
  if (wifiManager.autoConnect("NOISYLESS-Setup")) {
    // Connexion réussie → sauvegarder en NVS
    String newSSID = wifiManager.getWiFiSSID();
    String newPass = wifiManager.getWiFiPass();
    if (newSSID.length() > 0) {
      prefs.putString("ssid", newSSID);
      prefs.putString("pass", newPass);
      Serial.printf("[WiFi] Saved credentials for \"%s\" to NVS\n", newSSID.c_str());
    }
    digitalWrite(PIN_LED_R, HIGH);
    digitalWrite(PIN_LED_B, HIGH);
    Serial.println("\n[WiFi] Connected via captive portal");
  } else {
    // Timeout portal → fallback hardcoded
    Serial.println("[WiFi] Captive portal timeout, using hardcoded fallback");
    WiFi.mode(WIFI_STA);
    WiFi.begin(WIFI_SSID, WIFI_PASS);
    int dots = 0;
    while (WiFi.status() != WL_CONNECTED && dots < 40) {
      delay(500);
      Serial.print(".");
      dots++;
    }
  }
  prefs.end();

  digitalWrite(PIN_LED_R, HIGH);
  digitalWrite(PIN_LED_B, HIGH);
  Serial.println("\n[WiFi] Connected");
  Serial.printf("[WiFi] IP  : %s\n", WiFi.localIP().toString().c_str());
  Serial.printf("[WiFi] RSSI: %d dBm\n", WiFi.RSSI());
}

// ------------------------------------------------
// Connexion au broker MQTT, avec logs d'erreur
void connectMQTT() {
  if (mqtt.connected()) return;

  mqtt.setServer(MQTT_HOST, MQTT_PORT);
  Serial.printf("\n[MQTT] Connexion à %s:%u ...\n", MQTT_HOST, MQTT_PORT);
  Serial.printf("[MQTT] ClientID : %s\n", CLIENT_ID);
  Serial.printf("[MQTT] User     : %s\n", MQTT_USER);

  if (mqtt.connect(CLIENT_ID, MQTT_USER, MQTT_PASS)) {
    Serial.println("[MQTT] Connecté");
  } else {
    Serial.printf("[MQTT] Échec rc=%d (%s)\n", mqtt.state(), mqttError(mqtt.state()));
  }
}



void newDataCallback(const bme68xData data, const bsecOutputs outputs, Bsec2 bsec)
{
  if (!outputs.nOutputs)
  {
    return;
  }

  Serial.println("BSEC outputs:\n\tTime stamp = " + String((int)(outputs.output[0].time_stamp / INT64_C(1000000))));
  for (uint8_t i = 0; i < outputs.nOutputs; i++)
  {
    const bsecData output = outputs.output[i];
    switch (output.sensor_id)
    {
    case BSEC_OUTPUT_IAQ:
      Serial.println("\tIAQ = " + String(output.signal));
      Serial.println("\tIAQ accuracy = " + String((int)output.accuracy));
      g_bsec_last.iaq = output.signal;
      g_bsec_last.iaq_accuracy = output.accuracy;
      break;
    case BSEC_OUTPUT_RAW_TEMPERATURE:
      Serial.println("\tTemperature = " + String(output.signal));
      g_bsec_last.raw_temp_c = output.signal;
      break;
    case BSEC_OUTPUT_RAW_PRESSURE:
      Serial.println("\tPressure = " + String(output.signal));
      // La lib affiche en hPa dans l'exemple → convertir en Pa pour le JSON
      g_bsec_last.pressure_pa = (uint32_t)(output.signal * 100.0f + 0.5f);
      break;
    case BSEC_OUTPUT_RAW_HUMIDITY:
      Serial.println("\tHumidity = " + String(output.signal));
      g_bsec_last.raw_hum_pct = output.signal;
      break;
    case BSEC_OUTPUT_RAW_GAS:
      Serial.println("\tGas resistance = " + String(output.signal));
      g_bsec_last.raw_gas_ohms = (uint32_t)(output.signal + 0.5f);
      g_bsec_last.gas_ohms = (uint32_t)(output.signal + 0.5f);
      break;
    case BSEC_OUTPUT_STABILIZATION_STATUS:
      Serial.println("\tStabilization status = " + String(output.signal));
      g_bsec_last.stab_status = (uint8_t)output.signal;
      break;
    case BSEC_OUTPUT_RUN_IN_STATUS:
      Serial.println("\tRun in status = " + String(output.signal));
      g_bsec_last.run_in_status = (uint8_t)output.signal;
      break;
    case BSEC_OUTPUT_SENSOR_HEAT_COMPENSATED_TEMPERATURE:
      Serial.println("\tCompensated temperature = " + String(output.signal));
      g_bsec_last.temp_comp_c = output.signal;
      break;
    case BSEC_OUTPUT_SENSOR_HEAT_COMPENSATED_HUMIDITY:
      Serial.println("\tCompensated humidity = " + String(output.signal));
      g_bsec_last.hum_comp_pct = output.signal;
      break;
    case BSEC_OUTPUT_STATIC_IAQ:
      Serial.println("\tStatic IAQ = " + String(output.signal));
      g_bsec_last.s_iaq = output.signal;
      break;
    case BSEC_OUTPUT_CO2_EQUIVALENT:
      Serial.println("\tCO2 Equivalent = " + String(output.signal));
      g_bsec_last.co2eq_ppm = output.signal;
      break;
    case BSEC_OUTPUT_BREATH_VOC_EQUIVALENT:
      Serial.println("\tbVOC equivalent = " + String(output.signal));
      g_bsec_last.bvoc_eq_ppm = output.signal;
      break;
    case BSEC_OUTPUT_GAS_PERCENTAGE:
      Serial.println("\tGas percentage = " + String(output.signal));
      g_bsec_last.gas_pct = output.signal;
      break;
    case BSEC_OUTPUT_COMPENSATED_GAS:
      Serial.println("\tCompensated gas = " + String(output.signal));
      break;
    default:
      break;
    }
  }
  g_bsec_last.valid = true;
}
// ------------------------------------------------
// Initialisation BSEC2 (scan @0x76 puis @0x77) - échantillonnage Low Power
bool initBSEC() {
  Wire.begin(PIN_I2C_SDA, PIN_I2C_SCL);

  // Pilote le sélecteur d'adresse si câblé (LOW=0x76, HIGH=0x77)
  pinMode(PIN_BME_INT, OUTPUT);
  digitalWrite(PIN_BME_INT, HIGH);

  pinMode(PIN_BME_MODE, OUTPUT);
  digitalWrite(PIN_BME_MODE, LOW);
  delay(5);

  
  
  bsecSensor sensorList[] = {
    BSEC_OUTPUT_IAQ,
    BSEC_OUTPUT_RAW_TEMPERATURE,
    BSEC_OUTPUT_RAW_PRESSURE,
    BSEC_OUTPUT_RAW_HUMIDITY,
    BSEC_OUTPUT_RAW_GAS,
    BSEC_OUTPUT_STABILIZATION_STATUS,
    BSEC_OUTPUT_RUN_IN_STATUS,
    BSEC_OUTPUT_SENSOR_HEAT_COMPENSATED_TEMPERATURE,
    BSEC_OUTPUT_SENSOR_HEAT_COMPENSATED_HUMIDITY,
    BSEC_OUTPUT_STATIC_IAQ,
    BSEC_OUTPUT_CO2_EQUIVALENT,
    BSEC_OUTPUT_BREATH_VOC_EQUIVALENT,
    BSEC_OUTPUT_GAS_PERCENTAGE,
    BSEC_OUTPUT_COMPENSATED_GAS};

Wire.begin(PIN_I2C_SDA, PIN_I2C_SCL);

/* Initialize the library and interfaces */
if (!envSensor.begin(BME68X_I2C_ADDR_LOW, Wire))
{
  checkBsecStatus(envSensor);
}

/*
 *	The default offset provided has been determined by testing the sensor in LP and ULP mode on application board 3.0
 *	Please update the offset value after testing this on your product
 */
if (SAMPLE_RATE == BSEC_SAMPLE_RATE_ULP)
{
  envSensor.setTemperatureOffset(TEMP_OFFSET_ULP);
}
else if (SAMPLE_RATE == BSEC_SAMPLE_RATE_LP)
{
  envSensor.setTemperatureOffset(TEMP_OFFSET_LP);
}

/* Subsribe to the desired BSEC2 outputs */
if (!envSensor.updateSubscription(sensorList, ARRAY_LEN(sensorList), SAMPLE_RATE))
{
  checkBsecStatus(envSensor);
}

/* Whenever new data is available call the newDataCallback function */
envSensor.attachCallback(newDataCallback);

Serial.println("BSEC library version " +
               String(envSensor.version.major) + "." + String(envSensor.version.minor) + "." + String(envSensor.version.major_bugfix) + "." + String(envSensor.version.minor_bugfix));
return true;
}

// ------------------------------------------------
// Initialisation du LD2410 - parser custom (lib bypass)
bool initLD2410() {
  static bool serial_started = false;
  if (!serial_started) {
    RadarSerial.begin(256000, SERIAL_8N1, PIN_LD2410_RX_ESP, PIN_LD2410_TX_ESP);
    serial_started = true;
    Serial.println("[LD2410] UART @256000 baud, parser custom");
  }
  return true; // Toujours OK, on parse directement les frames
}

// Parser custom LD2410 - lit les frames F4F3F2F1...F8F7F6F5
// Frame target data (cyclic mode):
//   F4 F3 F2 F1 | LL LL | 02 AA | STATE | MD_L MD_H | ME | SD_L SD_H | SE | DD_L DD_H | 55 | CK | F8 F7 F6 F5
// STATE: 0=none, 1=moving, 2=stationary, 3=both
static struct {
  bool valid;
  uint8_t state;
  uint16_t moving_dist_cm;
  uint8_t moving_energy;
  uint16_t still_dist_cm;
  uint8_t still_energy;
  uint16_t detection_dist_cm;
  unsigned long last_update_ms;
} g_ld_data = {};

void parseLD2410Stream() {
  static uint8_t buf[64];
  static size_t pos = 0;
  static const uint8_t HDR[4] = {0xF4, 0xF3, 0xF2, 0xF1};

  while (RadarSerial.available()) {
    uint8_t b = RadarSerial.read();
    if (pos < sizeof(buf)) buf[pos++] = b;

    // Cherche le header
    if (pos < 4) continue;
    if (memcmp(buf, HDR, 4) != 0) {
      // shift left
      memmove(buf, buf + 1, pos - 1);
      pos--;
      continue;
    }
    // On a le header. Attendre au moins 6 bytes pour lire la longueur.
    if (pos < 6) continue;
    uint16_t len = buf[4] | (buf[5] << 8);
    size_t total = 4 + 2 + len + 4; // header + len + payload + footer
    if (total > sizeof(buf)) { pos = 0; continue; } // trop grand, reset
    if (pos < total) continue;

    // Verifier footer
    if (buf[total-4] == 0xF8 && buf[total-3] == 0xF7 &&
        buf[total-2] == 0xF6 && buf[total-1] == 0xF5) {
      // Frame complete - parser type 02 AA (target data)
      if (len >= 11 && buf[6] == 0x02 && buf[7] == 0xAA) {
        g_ld_data.state             = buf[8];
        g_ld_data.moving_dist_cm    = buf[9]  | (buf[10] << 8);
        g_ld_data.moving_energy     = buf[11];
        g_ld_data.still_dist_cm     = buf[12] | (buf[13] << 8);
        g_ld_data.still_energy      = buf[14];
        g_ld_data.detection_dist_cm = buf[15] | (buf[16] << 8);
        g_ld_data.valid = true;
        g_ld_data.last_update_ms = millis();
      }
    }
    // Avancer apres ce frame (qu'il soit valide ou non)
    if (pos > total) memmove(buf, buf + total, pos - total);
    pos = (pos > total) ? pos - total : 0;
  }
}


// ------------------------------------------------
// Lecture LD2410 via parser custom. presence=true si mouvement ou stationnaire.
bool readLD2410(bool& presence, uint16_t& distance_cm) {
  parseLD2410Stream();

  // Si pas de frame recu depuis 2s, considere offline
  if (!g_ld_data.valid || (millis() - g_ld_data.last_update_ms > 2000)) {
    presence = false;
    distance_cm = 0;
    return false;
  }

  bool motion = (g_ld_data.state & 0x01) != 0;
  bool still  = (g_ld_data.state & 0x02) != 0;
  presence = motion || still;

  if (motion && g_ld_data.moving_dist_cm > 0) {
    distance_cm = g_ld_data.moving_dist_cm;
  } else if (still && g_ld_data.still_dist_cm > 0) {
    distance_cm = g_ld_data.still_dist_cm;
  } else {
    distance_cm = g_ld_data.detection_dist_cm;
  }
  return true;
}

// ------------------------------------------------
// Lecture luminosité (deux entrées analogiques). Retourne toujours true.
bool readLightSensors(uint16_t& lux1_raw, uint16_t& lux2_raw) {
  lux1_raw = analogRead(PIN_LUX1_AIN);
  lux2_raw = analogRead(PIN_LUX2_AIN);
  return true;
}

// ------------------------------------------------
// Mesure simple du niveau sonore par pic-à-pic (P2P) sur ~50 ms
bool readMicrophones(uint16_t& mic1_pp, uint16_t& mic2_pp) {
  const uint32_t windowMs = 50;
  uint32_t t0 = millis();

  uint16_t min1 = 4095, max1 = 0;
  uint16_t min2 = 4095, max2 = 0;

  while ((millis() - t0) < windowMs) {
    uint16_t s1 = analogRead(PIN_MIC1);
    uint16_t s2 = analogRead(PIN_MIC2);
    if (s1 < min1) min1 = s1;
    if (s1 > max1) max1 = s1;
    if (s2 < min2) min2 = s2;
    if (s2 > max2) max2 = s2;
    delay(1);
  }

  mic1_pp = (max1 > min1) ? (max1 - min1) : 0;
  mic2_pp = (max2 > min2) ? (max2 - min2) : 0;
  return true;
}
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
void loop() {
  vTaskDelay(pdMS_TO_TICKS(100)); // boucle idle, les tâches gèrent tout
}

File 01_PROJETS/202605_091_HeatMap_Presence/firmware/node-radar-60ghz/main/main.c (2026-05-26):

/*
 * main.c — NOISYLESS HeatMap Node Radar 60GHz firmware.
 *
 * ESP32-S3 + MinewSemi MS72SF1 (UART 115200 bauds).
 * Roles: SLAVE (default) = radar read → parse → ESP-NOW to master.
 *        MASTER (elected)   = collect all nodes → fusion → MQTT.
 *
 * One binary for all roles. Role determined by mesh election.
 */

#include <stdio.h>
#include <string.h>
#include <math.h>
#include "freertos/FreeRTOS.h"
#include "freertos/task.h"
#include "freertos/semphr.h"
#include "esp_log.h"
#include "esp_sleep.h"
#include "esp_timer.h"
#include "nvs_flash.h"
#include "esp_netif.h"
#include "esp_event.h"
#include "driver/gpio.h"
#include "driver/adc.h"

#include "ms72sf1.h"
#include "mesh.h"
#include "config.h"
#include "mqtt.h"

#define TAG "MAIN"

/* ── Hardware pins ── */
#define LED_RED    GPIO_NUM_48
#define LED_GREEN  GPIO_NUM_47
#define LED_BLUE   GPIO_NUM_38
#define BAT_ADC    ADC1_CHANNEL_0  /* GPIO1 */

#define UART_NUM_RADAR   UART_NUM_2
#define RADAR_TX_PIN     GPIO_NUM_17
#define RADAR_RX_PIN     GPIO_NUM_18

/* ── MQTT config ── */
#define MQTT_BROKER_IP  "192.168.0.176"
#define MQTT_PORT       8883

/* ── Timing ── */
#define SENSOR_PERIOD_MS    1000
#define HEALTH_PERIOD_MS    30000
#define MASTER_FUSION_MS    5000
#define CRITICAL_BAT_SLEEP_S 600

/* ── Globals ── */
static SemaphoreHandle_t sensor_sem = NULL;
static bool master_mode = false;

/* ── Forward declarations ── */
static void sensor_task(void *arg);
static void health_task(void *arg);
static void master_task(void *arg);
static void sensor_wake_callback(void *arg);
static void master_recv_callback(const void *payload, size_t size);
static uint16_t get_battery_mv(void);
static void led_init(void);

/* ══════════════════════════════════════════════════════════════
 * Sensor task (Core 0)
 * ══════════════════════════════════════════════════════════════ */

static void sensor_task(void *arg) {
    ESP_LOGI(TAG, "Sensor task started");

    if (!ms72sf1_init()) {
        ESP_LOGE(TAG, "MS72SF1 init failed — sensor task aborting");
        vTaskDelete(NULL);
        return;
    }

    for (;;) {
        xSemaphoreTake(sensor_sem, pdMS_TO_TICKS(SENSOR_PERIOD_MS * 2));

        ms72sf1_frame_t frame;
        if (!ms72sf1_read_frame(&frame)) {
            continue;
        }

        /* Send via ESP-NOW to mesh master */
        if (frame.target_count > 0) {
            mesh_send_radar_payload(&frame);
            ESP_LOGD(TAG, "Radar frame: %d targets sent", frame.target_count);
        }

        vTaskDelay(pdMS_TO_TICKS(10));
    }
}

/* ══════════════════════════════════════════════════════════════
 * Health task (Core 0)
 * ══════════════════════════════════════════════════════════════ */

static uint16_t get_battery_mv(void) {
    int raw = adc1_get_raw(BAT_ADC);
    /* Voltage divider 1:2 → ADC = Vbat * (100k / (100k + 100k)) */
    return (uint16_t)(raw * 3.3f / 4095.0f * 2.0f * 1000.0f);
}

static void health_task(void *arg) {
    /* Init ADC */
    adc1_config_width(ADC_WIDTH_BIT_12);
    adc1_config_channel_atten(BAT_ADC, ADC_ATTEN_DB_11);

    for (;;) {
        uint16_t bat = get_battery_mv();

        /* LED indication */
        gpio_set_level(LED_GREEN, (bat > 3200) ? 0 : 1);
        gpio_set_level(LED_RED,   (bat < 3000) ? 0 : 1);

        ESP_LOGI(TAG, "Health: bat=%dmV, role=%s",
                 bat, master_mode ? "MASTER" : "SLAVE");

        /* Critical battery → deep sleep */
        if (bat < 3000) {
            ESP_LOGW(TAG, "Battery critical (%dmV) — deep sleep %ds",
                     bat, CRITICAL_BAT_SLEEP_S);
            gpio_set_level(LED_RED, 0);
            vTaskDelay(pdMS_TO_TICKS(1000));
            esp_deep_sleep(CRITICAL_BAT_SLEEP_S * 1000000ULL);
        }

        vTaskDelay(pdMS_TO_TICKS(HEALTH_PERIOD_MS));
    }
}

/* ══════════════════════════════════════════════════════════════
 * Master task (Core 0) — only runs if this node is elected master
 * ══════════════════════════════════════════════════════════════ */

#define MASTER_PAYLOAD_BUF_SIZE  4096
#define MASTER_MAX_SLAVES        20

typedef struct {
    uint8_t mac[6];
    uint16_t battery_mv;
    ms72sf1_frame_t last_frame;
    uint32_t last_update_ms;
} slave_data_t;

static slave_data_t slave_data[MASTER_MAX_SLAVES];
static uint8_t slave_count = 0;

static slave_data_t *find_slave(const uint8_t *mac) {
    for (int i = 0; i < slave_count; i++) {
        if (memcmp(slave_data[i].mac, mac, 6) == 0) {
            return &slave_data[i];
        }
    }
    if (slave_count < MASTER_MAX_SLAVES) {
        slave_data_t *s = &slave_data[slave_count++];
        memcpy(s->mac, mac, 6);
        return s;
    }
    return NULL;
}

static void master_recv_callback(const void *payload, size_t size) {
    if (size < 12) return; /* Need at least type + mac + count */

    const uint8_t *p = (const uint8_t *)payload;

    uint8_t type = p[0];
    if (type != MESH_TYPE_DATA_RADAR) return;

    const uint8_t *src_mac = p + 1;
    uint8_t target_count = p[12];

    slave_data_t *slave = find_slave(src_mac);
    if (!slave) return;

    slave->last_update_ms = esp_timer_get_time() / 1000;
    slave->last_frame.target_count = target_count;

    const mesh_radar_target_t *targets = (const mesh_radar_target_t *)(p + 13);
    for (int i = 0; i < target_count && i < MS72SF1_MAX_TARGETS; i++) {
        slave->last_frame.targets[i].x_m = targets[i].x_cm / 100.0f;
        slave->last_frame.targets[i].y_m = targets[i].y_cm / 100.0f;
        slave->last_frame.targets[i].z_m = targets[i].z_cm / 100.0f;
        slave->last_frame.targets[i].q   = targets[i].quality;
    }
}

static void build_heatmap_json(char *buf, size_t buf_size) {
    int offset = snprintf(buf, buf_size,
        "{\"schema\":\"nl.telemetry.v1\",\"model\":\"nl-map-out\","
        "\"duid\":\"radar-master\",\"ts\":%lld,\"metrics\":{\"targets\":[",
        (long long)(esp_timer_get_time() / 1000));

    bool first = true;
    for (int s = 0; s < slave_count; s++) {
        ms72sf1_frame_t *f = &slave_data[s].last_frame;
        for (int i = 0; i < f->target_count; i++) {
            ms72sf1_target_t *t = &f->targets[i];
            if (offset + 120 >= (int)buf_size) break;
            if (!first) buf[offset++] = ','; else first = false;
            offset += snprintf(buf + offset, buf_size - offset,
                "{\"id\":%d,\"x\":%.2f,\"y\":%.2f,\"z\":%.2f,"
                "\"vx\":%.2f,\"vy\":%.2f,\"q\":%d}",
                (int)t->id, t->x_m, t->y_m, t->z_m,
                t->vx, t->vy, (int)t->q);
        }
    }

    snprintf(buf + offset, buf_size - offset,
        "],\"count\":%d},\"health\":{\"battery_mv\":%d,\"rssi\":-60,\"fw\":\"1.0.0\"}}",
        slave_count, get_battery_mv());
}
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

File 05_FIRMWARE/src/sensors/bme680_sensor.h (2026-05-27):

/**
 * bme680_sensor.h — BME680 + BSEC2 NOISYLESS v2.0.0
 * 
 * Pins I2C  : SDA=GPIO35, SCL=GPIO36 (schéma RevB)
 * Mode      : Ultra Low Power (ULP) — 3s entre mesures
 * Sorties   : IAQ, CO2eq, bVOCeq, T°/Hum/Pression compensées,
 *             Gas, Raw T/H/G, stab/run-in status
 * 
 * Usage :
 *   BME680Sensor bme;
 *   bme.init();             // scan @0x76 puis @0x77
 *   bme.tick();             // appel régulier (depuis task FreeRTOS)
 *   BME680Readings data = bme.last();
 * 
 * NB : BSEC2 nécessite des appels réguliers à tick() pour
 *      maintenir la calibration IAQ (toutes les 3s en ULP).
 */

#ifndef BME680_SENSOR_H
#define BME680_SENSOR_H

#include <Arduino.h>
#include <Wire.h>
#include <bsec2.h>

// Pins I2C (schéma RevB)
#define PIN_BME_INT  34   // pas utilisé en mode polling
#define PIN_BME_MODE 37   // LOW = mode normal
#define PIN_I2C_SDA  35
#define PIN_I2C_SCL  36

// Nombre total de sorties BSEC demandées
#define BSEC_OUTPUT_COUNT 13

struct BME680Readings {
  bool  valid          = false;
  // Valeurs compensées
  float temp_comp_c    = 0.0f;
  float hum_comp_pct   = 0.0f;
  uint32_t pressure_pa = 0;
  // Qualité d'air
  float iaq            = 0.0f;   // 0-500 (0=clean)
  float s_iaq          = 0.0f;   // static IAQ
  float co2eq_ppm      = 0.0f;
  float bvoc_eq_ppm    = 0.0f;
  uint8_t iaq_accuracy = 0;      // 0..3 (3=max)
  // Gas
  uint32_t gas_ohms    = 0;
  float gas_pct        = 0.0f;
  // Raw
  float raw_temp_c     = 0.0f;
  float raw_hum_pct    = 0.0f;
  uint32_t raw_gas_ohms = 0;
  // Statut
  uint8_t stab_status   = 0;     // 0=ongoing, 1=complete
  uint8_t run_in_status = 0;     // 0=ongoing, 1=complete
};

class BME680Sensor {
public:
  bool init() {
    // Config pins BME
    pinMode(PIN_BME_INT, OUTPUT);
    digitalWrite(PIN_BME_INT, HIGH);
    pinMode(PIN_BME_MODE, OUTPUT);
    digitalWrite(PIN_BME_MODE, LOW);
    
    // I2C sur pins dédiés
    Wire.setPins(PIN_I2C_SDA, PIN_I2C_SCL);
    Wire.begin();
    delay(50);
    
    // Scan I2C — le BME680 répond à 0x76 ou 0x77
    Wire.beginTransmission(0x76);
    if (Wire.endTransmission() != 0) {
      Wire.beginTransmission(0x77);
      if (Wire.endTransmission() != 0) {
        Serial.println("[BME680] Introuvable sur le bus I2C");
        return false;
      }
    }
    Serial.println("[BME680] Détecté sur I2C");
    
    // Liste des sorties BSEC demandées
    bsecSensor sensorList[BSEC_OUTPUT_COUNT] = {
      BSEC_OUTPUT_IAQ,
      BSEC_OUTPUT_STATIC_IAQ,
      BSEC_OUTPUT_CO2_EQUIVALENT,
      BSEC_OUTPUT_BREATH_VOC_EQUIVALENT,
      BSEC_OUTPUT_SENSOR_HEAT_COMPENSATED_TEMPERATURE,
      BSEC_OUTPUT_SENSOR_HEAT_COMPENSATED_HUMIDITY,
      BSEC_OUTPUT_RAW_PRESSURE,
      BSEC_OUTPUT_RAW_GAS,
      BSEC_OUTPUT_GAS_PERCENTAGE,
      BSEC_OUTPUT_RAW_TEMPERATURE,
      BSEC_OUTPUT_RAW_HUMIDITY,
      BSEC_OUTPUT_STABILIZATION_STATUS,
      BSEC_OUTPUT_RUN_IN_STATUS,
    };
    
    if (!_bsec.begin(BME68X_I2C_ADDR_LOW, Wire)) {
      Serial.println("[BME680] BSEC2 init failed");
      return false;
    }
    
    // Config mode Ultra Low Power
    if (!_bsec.updateSubscription(sensorList, BSEC_OUTPUT_COUNT, BSEC_SAMPLE_RATE_ULP)) {
      Serial.println("[BME680] BSEC2 subscription failed");
      return false;
    }
    
    _bsec.attachCallback(newDataCallback_static);
    
    Serial.printf("[BME680] BSEC2 v%d.%d initialized (ULP mode)\n", 
                  _bsec.version.major, _bsec.version.minor);
    _initialized = true;
    return true;
  }
  
  /**
   * À appeler régulièrement (~chaque loop ou task 100ms).
   * BSEC2 gère son propre timing interne.
   */
  void tick() {
    if (!_initialized) return;
    _bsec.run();
  }
  
  const BME680Readings& last() const { return _data; }
  
  bool initialized() const { return _initialized; }

private:
  Bsec2     _bsec;
  bool      _initialized = false;
  BME680Readings _data;
  
  // Callback statique → instance
  static void newDataCallback_static(const bme68xData data, 
                                     const bsecOutputs outputs, 
                                     Bsec2 bsec) {
    // Récupère l'instance singleton
    extern BME680Sensor& bme680_instance();
    bme680_instance()._onData(data, outputs, bsec);
  }
  
  void _onData(const bme68xData data, const bsecOutputs outputs, Bsec2 /*bsec*/) {
    for (uint8_t i = 0; i < outputs.nOutputs; i++) {
      const bsecData& out = outputs.output[i];
      switch (out.sensor_id) {
        case BSEC_OUTPUT_IAQ:
          _data.iaq = out.signal;
          _data.iaq_accuracy = out.accuracy;
          break;
        case BSEC_OUTPUT_STATIC_IAQ:
          _data.s_iaq = out.signal;
          break;
        case BSEC_OUTPUT_CO2_EQUIVALENT:
          _data.co2eq_ppm = out.signal;
          break;
        case BSEC_OUTPUT_BREATH_VOC_EQUIVALENT:
          _data.bvoc_eq_ppm = out.signal;
          break;
        case BSEC_OUTPUT_SENSOR_HEAT_COMPENSATED_TEMPERATURE:
          _data.temp_comp_c = out.signal;
          break;
        case BSEC_OUTPUT_SENSOR_HEAT_COMPENSATED_HUMIDITY:
          _data.hum_comp_pct = out.signal;
          break;
        case BSEC_OUTPUT_RAW_PRESSURE:
          _data.pressure_pa = (uint32_t)(out.signal * 100.0f + 0.5f);
          break;
        case BSEC_OUTPUT_RAW_GAS:
          _data.gas_ohms = (uint32_t)(out.signal + 0.5f);
          break;
        case BSEC_OUTPUT_GAS_PERCENTAGE:
          _data.gas_pct = out.signal;
          break;
        case BSEC_OUTPUT_RAW_TEMPERATURE:
          _data.raw_temp_c = out.signal;
          break;
        case BSEC_OUTPUT_RAW_HUMIDITY:
          _data.raw_hum_pct = out.signal;
          break;
        case BSEC_OUTPUT_STABILIZATION_STATUS:
          _data.stab_status = (uint8_t)out.signal;
          break;
        case BSEC_OUTPUT_RUN_IN_STATUS:
          _data.run_in_status = (uint8_t)out.signal;
          break;
        default: break;
      }
    }
    _data.valid = true;
  }
};

// Singleton — déclaré dans le .cpp
extern BME680Sensor g_bme680;

#endif // BME680_SENSOR_H

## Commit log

2025-12-08 first commit repertoire
    [01_microcontroller.kicad_sch, 02_SENSORS.kicad_sch, ENVIRONEMENTAL SENSOR_bom.csv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]
2026-05-08 firmware(esp32): point to VPS broker + custom LD2410 parser
    - MQTT_HOST: 85.215.145.44 -> 91.99.26.43 (VPS NOISYLESS)
    - LD2410: bypass buggy ncmreynolds lib, parse F4F3F2F1...F8F7F6F5
    frames directly from Serial1 @256000 baud (per HLK-LD2410 datasheet
    V1.02). Fixes radar.begin() returning false even when sensor sends
    valid frames.
    - LD2410 init now retries every 5s instead of giving up at boot.
    Validated end-to-end: ESP32 -> MQTT -> TimescaleDB, presence detected
    at 30-150 cm with movement.
    [main.cpp]
2026-05-08 deploy(vps): MQTT ingest service + Mosquitto bridge to TimescaleDB
    - mqtt_ingest.py: paho-mqtt subscriber that parses ESP32 JSON, converts
    ADC mic peak-to-peak to dB SPL (log formula) and ADC lux to lux
    (linear), inserts into TimescaleDB measurements table, updates
    devices.last_seen + firmware_version. Auto-reconnect on DB/MQTT loss.
    - Dockerfile + requirements (paho-mqtt 2.1, psycopg2-binary 2.9).
    - mosquitto.conf: plain listener 1883 with password_file auth.
    - deploy-vps.sh: idempotent script that uploads files, creates passwd
    with correct UID 1883 ownership via temp container, patches
    docker-compose.yml (separates LE certs from config mount, exposes
    port 1883), generates compo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
2026-05-08 docs: architecture, J+5 sale plan, flashing guide, session changelog
    - ARCHITECTURE.md: end-to-end pipeline (ESP32 -> MQTT -> ingest -> DB
    -> dashboard), endpoints, schemas, file paths, current limitations.
    - PLAN_J5_VENTE.md: 5-day roadmap to ready-to-sell system (WiFiManager,
    device ID auto, LED status, Stripe webhook, acquisition tunnel).
    - FLASHER_FIRMWARE.md: practical guide compile + flash + verify +
    troubleshooting (LD2410 hardware checks, common build errors).
    - CHANGELOG-2026-05-08.md: 11-step chronology of the bring-up session.
2026-05-24 ota: initial stable.json manifest for firmware updates
    [MCU.kicad_sch, netlist.csv, netlist.xlsx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]
2026-05-24 fix: mqtt-ingest asyncio thread-safe queue + heatmap_agg_5min table
2026-05-24 chore: gitignore SSL accounts and KiCad history
2026-05-24 fix: convert 089 from broken gitlink to regular folder
    [01_microcontroller.kicad_sch, 02_SENSORS.kicad_sch, ENVIRONEMENTAL SENSOR_bom.csv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]
2026-05-24 refactor: align NOISYLESS on MATLOG structure (01_PROJETS/)
    - Move 202604_089_* and 202605_091_* into 01_PROJETS/
    - Move deployment code (backend/frontend/web/services/_infra/nginx/ota/visu/
    noisyless-deployment) into 091/_commun/ (shared by the 3 firmware variants)
    - Move deployment docs (BACKEND_PLAN, DEPLOYMENT_*, TODO, TASKS_ORDERED,
    PROMPTS, tasks.json, README_DEPLOYMENT) into 091/_commun/docs/
    - Move OSRAM TMF8829 datasheet into 091/docs/datasheets/
    - Delete noisyless-deployment.zip (duplicate of deployment/)
    - Convert 089 from broken gitlink to regular folder
    - Gitignore SSL accounts and KiCad history
    [01_microcontroller.kicad_sch, 02_SENSORS.kicad_sch, ENVIRONEMENTAL SENSOR_bom.csv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]
2026-05-24 feat: add node-radar-60ghz firmware components (ESP-IDF)
    - Add components: config, mesh, mqtt, ms72sf1 (radar sensor driver)
    - Add platformio.ini, partitions.csv, sdkconfig.defaults
    - Update main.c with radar heatmap implementation
    Project 091 - HeatMap Presence firmware
    [partitions.csv]
2026-05-26 sync: rapatriement code API production + cahier de recette
    - auth.py (432 lignes): auth JWT, register, login, magic-link, reset password
    - customer.py (62 lignes): gestion clients
    - devices.py (179 lignes): CRUD devices
    - emails.py (55 lignes): SMTP OVH
    - pilot.py (165 lignes): programme pilote
    - shop.py (87 lignes): endpoint checkout Stripe
    - shop_webhook.py (53 lignes): webhook Stripe checkout.session.completed
    - main.py: remplacement par version serveur (routeurs séparés)
    - CAHIER_RECETTE_NOISYLESS.md: audit complet infrastructure
    Source: rsync depuis noisyless@91.99.26.43:/opt/noisyless/services/api/
2026-05-26 feat: kit de démarrage agent Hermes (.hermes/)
    - SOUL.md: instructions système minimales (IP, design, biz model, pièges)
    - skills/noisyless-heatmap: règles firmware/hardware #091 + refs
    - skills/noisyless-deployment: procédures déploiement + refs (stripe, nginx, ota...)
    - backlog/todo.json: 28 tâches avec statuts (21 done, 6 blocked, 1 error)
    - backlog/logs/: 23 logs d'exécution horodatés
    - knowledge/: fiches clients + projets NOISYLESS (#045, #089, #091)
    - README.md: instructions d'installation pour nouvel agent
    Permet à un agent sur 192.168.0.176 de reprendre avec tout le contexte.
2026-05-27 firmware v1.0.8: LED rouge si WiFi perdu, OTA déployé sur 4 modules
2026-05-27 docs: README complet — capteurs, OTA, LED, architecture, pièges
2026-05-27 firmware v2.0.0: architecture modulaire FreeRTOS — BME680/BSEC2, LD2410, OTA, LED
2026-05-27 docs: README v2.0.0 — architecture modulaire, 5 capteurs, FreeRTOS
2026-05-27 ota: v1.1.0 — manifest pointe vers VPS (noisyless.com/firmware/), SHA256 vérifié
2026-05-27 ota: v0.0.1 — firmware production, I2C fix, LED OTA, check every 10min
2026-05-27 ota: v0.0.2 — test OTA, LED bleue 3s
2026-05-28 feat: v0.0.3 - fix double exception crash during OTA
    - WiFiClientSecure heap-allocated (new) instead of stack
    - g_otaMutex semaphore to prevent concurrent OTA calls
    - g_otaRunning flag to track OTA state
    - errLeds() non-blocking (blink once then continue)
    - All variables declared before goto ota_cleanup (C++ compliance)
    SHA256: d4346d9452dde7186495a99e70b9602fbc6a7a5ad5d1a1d9895527b8c400e268
    [custom_partitions.csv]
2026-05-29 sync: VPS production v1 snapshot (29 mai 2026)
    - Snapshot complet du VPS Hetzner 91.99.26.43 vers _live/
    - admin.py, env-ingest (3 fichiers) ajoutés à _infra
    - auth.py, devices.py, main.py mis à jour (VPS version live)
    - platform.html, admin.html, dashboard.html + pages HeatMap
    - produits/, cas-usage/, comparatif/, technologie/ complétés
    - firmware/stable.json, latest.json
    - docker-compose.yml, nginx.conf, mosquitto.conf synchronisés
    - _live/STATE.md : état des lieux complet + bugs v1 connus
